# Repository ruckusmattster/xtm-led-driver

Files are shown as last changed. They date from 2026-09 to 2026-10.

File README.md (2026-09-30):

<div align="center">

# XTM LED Driver

**A flicker-free, four-decade DC LED driver for theatrical fixtures.**<br>
1.4 A down to 5 µA as pure DC: no PWM anywhere, nothing for a camera to catch.

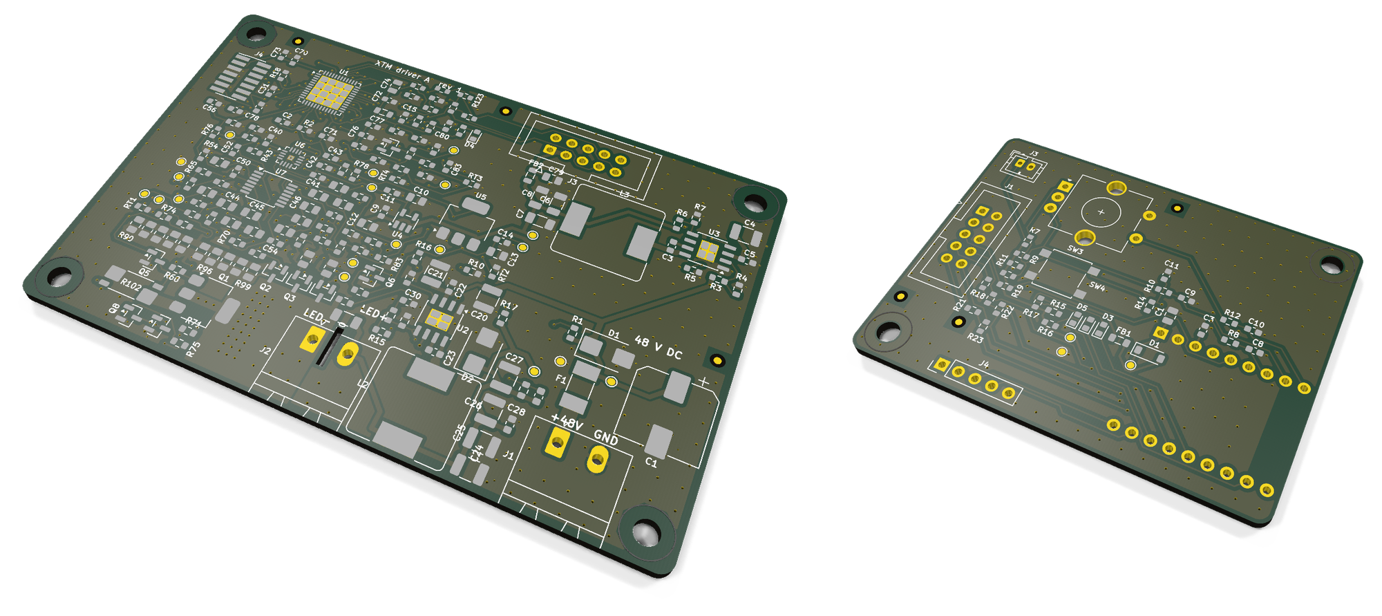
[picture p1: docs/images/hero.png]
3D renders of Board A, the driver, and Board B, the controller








[**Build guide**](docs/BUILD_GUIDE.md) ·
[**Design process**](docs/DESIGN_PROCESS.md) ·
[Hardware](docs/HARDWARE.md) ·
[Firmware](docs/FIRMWARE.md) ·
[Design record](docs/design-record/)

</div>

---

I'm building four stage fixtures around the **Xicato XTM19803050CCA** (19 mm LES, 3000 K, about
5000 lm at 1.4 A). Off-the-shelf drivers either dim with PWM, which rolling-shutter cameras turn
into bands, or bottom out around 1%, which makes the end of every fade snap to black. This
project is a two-board driver that does neither: the LED current is DC at every level from full
output down to 5 µA (0.0004%), fades are smooth enough to film in 240 fps slow motion, and each
fixture is a normal dimmable light in Home Assistant with a knob on the back and a sync button
that makes the others follow it.

Everything is here: the schematics (as code), the design calculations and simulations, scripted
KiCad 9 layouts that come out DRC-clean, Gerbers and placement files, BOMs with verified part
numbers, firmware for both boards with its tests, and the procedures to bring it up, calibrate
it and prove it doesn't flicker.

## Highlights

- **Four DC ranges, not PWM.** Four linear current sinks with 0.1 Ω, 1 Ω, 10 Ω and 100 Ω shunts
  sit in parallel under the LED. Each covers a decade at the same 14–140 mV sense voltage, so
  every range is equally precise, and a calibrated tail carries the last decade and a half to 5 µA.
- **Crossovers you can't see.** Where two ranges meet, both channels share the current on a
  log-domain blend, and the incoming channel idles at a small keep-alive current so it's already
  regulating when it's needed. Simulated deviation at a crossover: 0.14% on a 10 s fade.
- **A tracking buck that stays out of the picture.** A forced-PWM buck at 400 kHz holds the LED
  anode about 1 V above what the sinks need, set ahead of every current change by the MCU. Its
  ripple sits far above anything a camera or eye integrates.
- **Precision where it counts.** 16-bit DAC, zero-drift op-amps, Kelvin-sensed shunts (a
  four-terminal 0.1 Ω and 0.1% thin film for the rest), a guarded "precision island" on a 4-layer board. After calibration each range
  holds about ±0.1% of reading.
- **Real-time control on the driver.** An STM32G431 runs fades at 4 kHz, the crossovers, the
  headroom loop and the protection (a shorted LED clamps every sink within 100 µs). Wi-Fi never
  touches the light.
- **A friendly controller.** Board B is a socketed Waveshare ESP32-S3-Zero running ESPHome:
  Home Assistant light, rotary encoder with push, status LED, and fixture-to-fixture sync over
  ESP-NOW with authenticated packets. Every fixture also works completely on its own.
- **Layout by script.** Python scripts place every part, draw the critical copper by hand-coded
  rules, route the rest with Freerouting, pour and stitch ground, run DRC and export JLCPCB files.
  Both boards come out with 0 errors and 0 unconnected items.

## How it works

```mermaid
flowchart TB
  mains(["Mains"]) --> psu["Mean Well LRS-100-48<br/>isolated 48 V, off-board"]
  subgraph A["Board A · driver · 90 × 60 mm, 4 layers"]
    fuse["Fuse + TVS"] --> buck["Tracking buck<br/>LMR38020, forced PWM"]
    fuse --> aux["Aux buck + LDOs<br/>5.5 V · 5 V · 3.3 V"]
    mcu["STM32G431<br/>4 kHz control loop"] -->|SPI| dac["DAC80504<br/>4 × 16-bit"]
    dac --> sinks["OPA4388 + 4 linear sinks<br/>0.1 Ω · 1 Ω · 10 Ω · 100 Ω"]
    mcu -->|"DAC → feedback"| buck
    sinks -.->|"cathode tap<br/>fast trip"| mcu
  end
  subgraph L["LED"]
    led(["Xicato XTM<br/>up to 1.4 A"])
  end
  subgraph B["Board B · controller · 60 × 45 mm"]
    knob["Encoder · push · sync"] --> esp["ESP32-S3-Zero<br/>ESPHome"]
  end
  ha(["Home Assistant"])
  other(["Other fixtures"])
  psu -->|"48 V DC"| fuse
  buck -->|"LED+"| led
  led -->|"LED−"| sinks
  mcu ---|"10-way ribbon<br/>UART · 5.5 V · reset"| esp
  esp -.-|"Wi-Fi"| ha
  esp -.-|"ESP-NOW"| other
```

The **sinks** set the LED current; the **buck** only supplies the voltage they need. Board A's
MCU knows the LED's forward voltage at every current (it learns it as it runs), so on a rising
cue it raises the buck first and then the current, and on a falling cue the reverse. Only a
level, a fade time and status cross the ribbon to Board B.

<picture>
  <source media="(prefers-color-scheme: dark)" srcset="docs/images/ranges-dark.png">
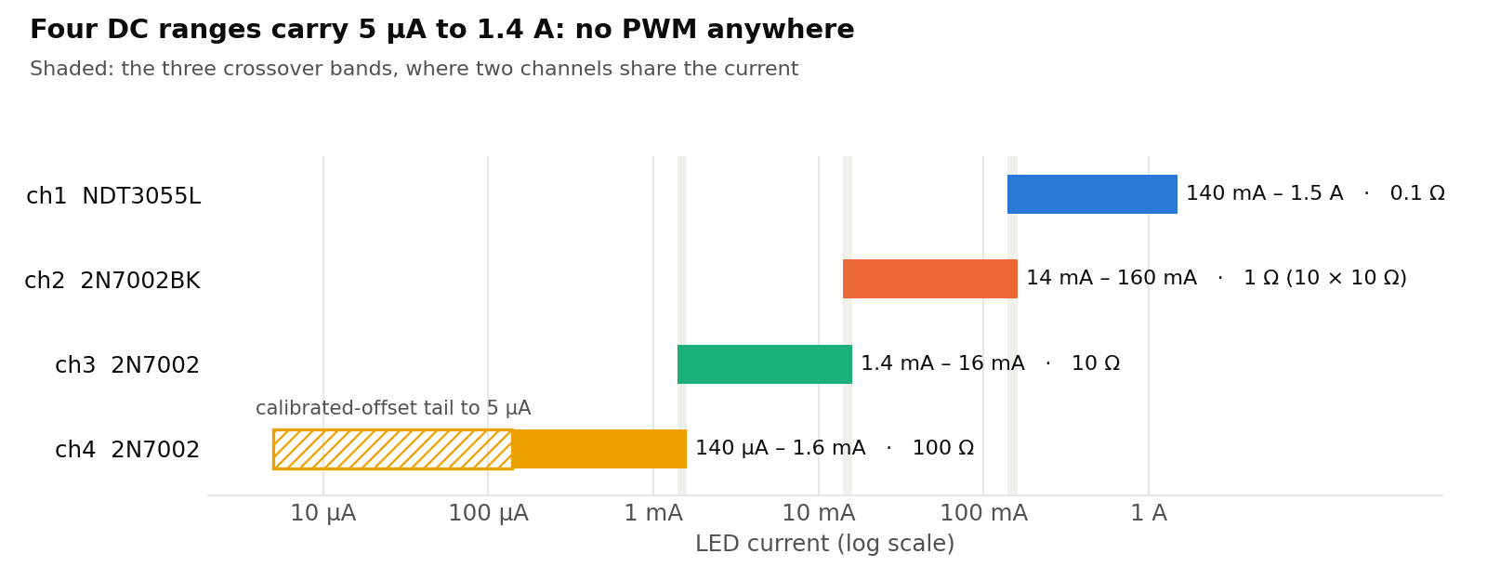
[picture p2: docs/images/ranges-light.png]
Bar chart of the four current ranges on a log scale: ch4 140 µA to 1.6 mA with a tail to 5 µA, ch3 1.4 to 16 mA, ch2 14 to 160 mA, ch1 140 mA to 1.5 A
  
</picture>

Brightness is exponential in the setting, so every step looks the same size: 1% of the scale is
about 13% more light, from 5 µA at the bottom to 1.4 A at the top.

<picture>
  <source media="(prefers-color-scheme: dark)" srcset="docs/images/curve-dark.png">
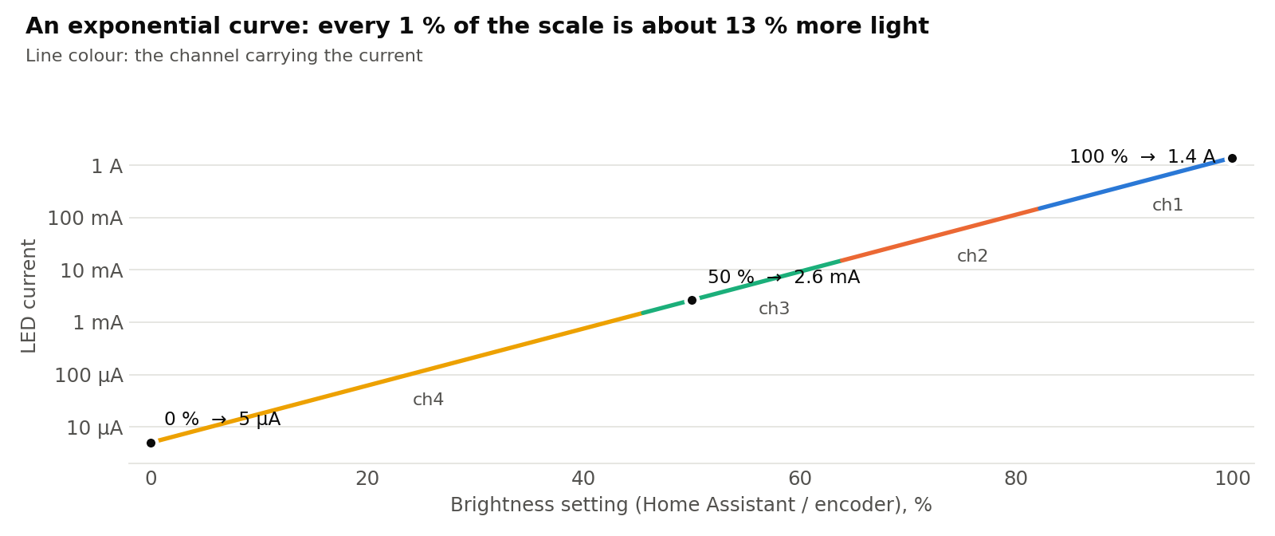
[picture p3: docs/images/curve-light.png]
Line chart of LED current against brightness setting on a log axis: a straight line from 5 µA at 0% to 1.4 A at 100%, coloured by the channel carrying the current
  
</picture>

## The boards

| | Board A: driver | Board B: controller |
| --- | --- | --- |
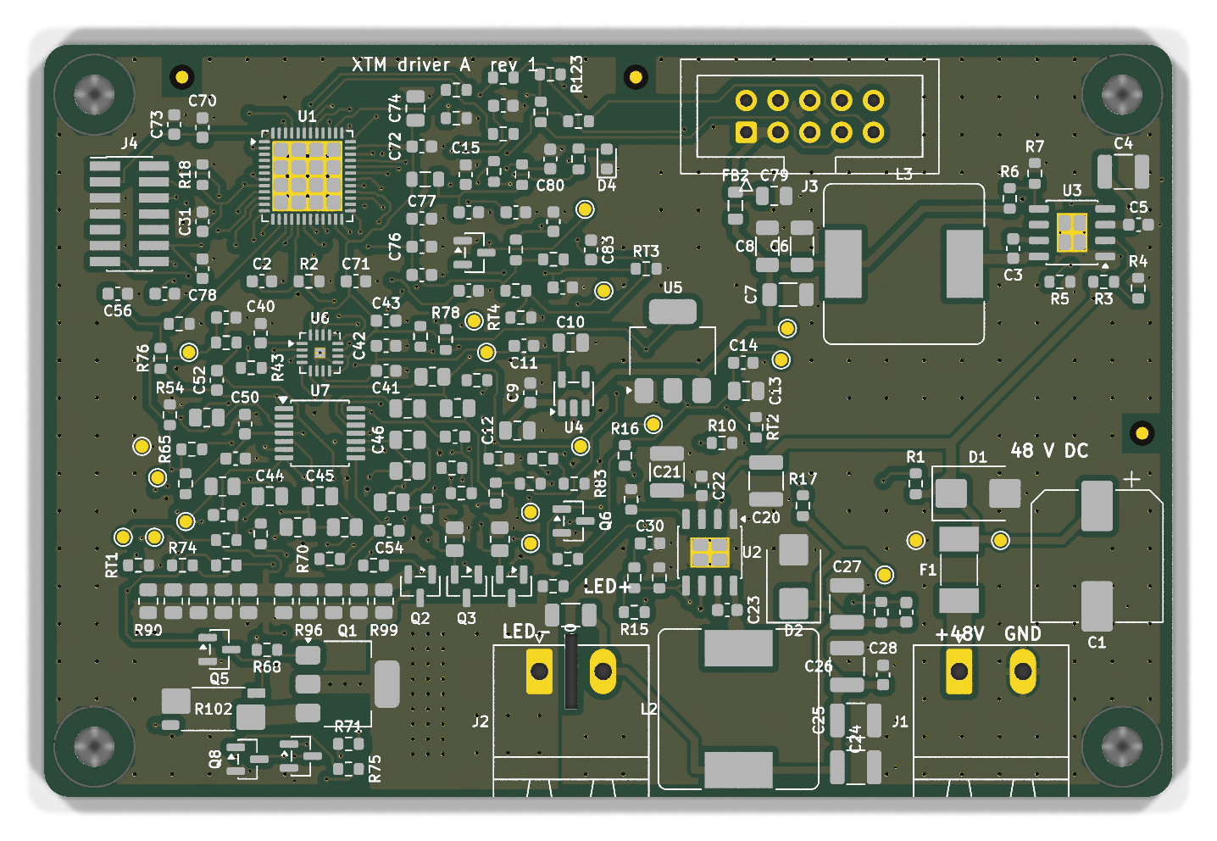
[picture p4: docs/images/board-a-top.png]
Board A top
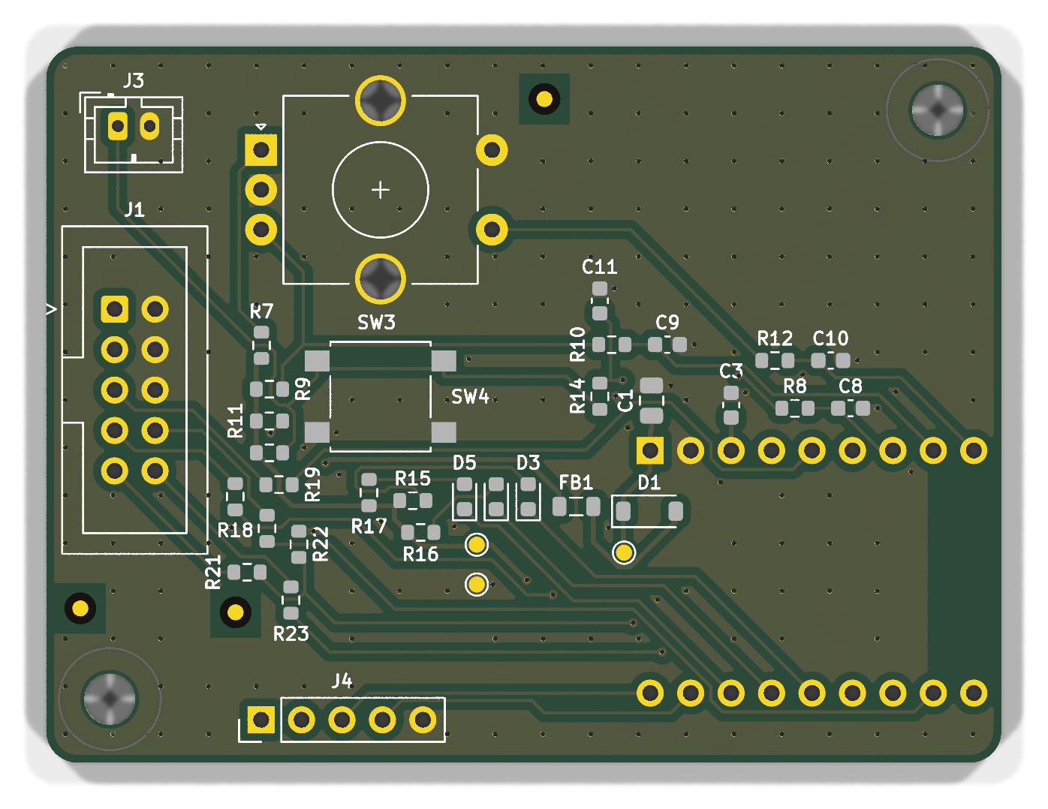
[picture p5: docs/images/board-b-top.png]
Board B top
| **Top** |  |  |
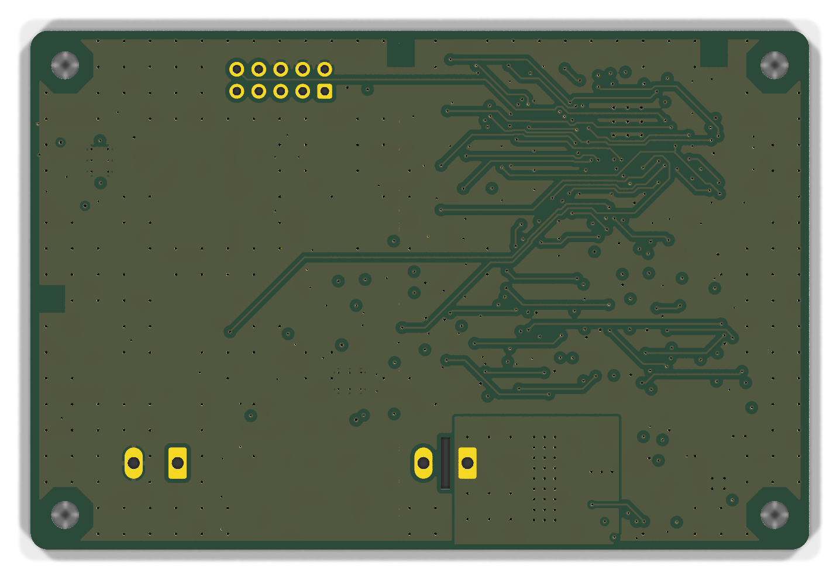
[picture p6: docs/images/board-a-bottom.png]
Board A bottom
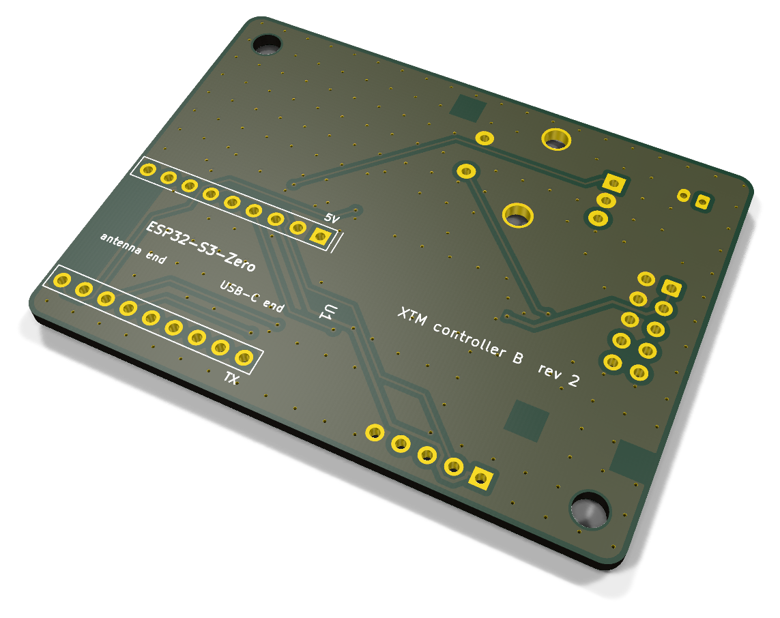
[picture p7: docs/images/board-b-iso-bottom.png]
Board B bottom with the ESP32-S3-Zero sockets
| **Bottom** |  |  |
| Size | 90 × 60 mm, 4 layers, ENIG | 60 × 45 mm, 2 layers, ENIG |
| Parts | 206 on 96 nets | 42 on 32 nets |
| Does | 48 V in, tracking buck, four sinks, protection, fades, calibration | Wi-Fi and Home Assistant, knob, sync, status LED |
| Key parts | STM32G431CBU6, DAC80504, OPA4388, 2 × LMR38020, NDT3055L, WSK2512 | Waveshare ESP32-S3-Zero-M on sockets, Bourns PEC11R encoder |
| Layout result | 0 DRC errors, 0 unconnected | 0 DRC errors, 0 unconnected |

Renders are bare boards from KiCad (no 3D models for the parts). The ESP32-S3-Zero plugs into
two sockets on Board B's back, so it can be pulled out and flashed over its own USB-C.

## Specifications

Design values from the calculations and simulations in [`design/`](design/). None of this has
been measured on hardware yet.

| Parameter | Design value |
| --- | --- |
| Output | 5 µA to 1.4 A DC (1.5 A with tolerance), four ranges plus a calibrated tail |
| Brightness curve | Exponential: 0–100% → 5 µA–1.4 A, about 13% more light per 1% step |
| Flicker target | Under 1% at any frequency from 100 Hz to 20 kHz, at every level and during fades |
| Accuracy after calibration | ±0.09–0.11% RSS in each range; ±0.6% at 14 µA and ±1.6% at 5 µA |
| Crossover smoothness | 0.11–0.14% on a 10 s full-range fade, 0.9–1.5% on a 1 s fade (simulated) |
| Response | Snaps within 5 ms; fades updated at 4 kHz, from instant to 10 minutes |
| Input | 48 V DC (43.2–52.8 V) from a Mean Well LRS-100-48; about 45 W at full output |
| LED voltage | 3.5 V floor to 38 V usable, 40.4 V hard ceiling |
| Protection | Shorted LED (every sink clamped within 50–100 µs), open LED, undervoltage, four temperature sensors with derating, DAC read-back, watchdog, 3 A fuse, TVS on input and output |
| Link loss | Board A blinks twice and settles at 20% if Board B goes quiet; planned restarts hold the level |
| Control | Home Assistant (ESPHome native API), encoder with push, sync button and a header for a panel-mount button |
| Group sync | ESP-NOW broadcast, fixture to fixture, HMAC-SHA256 authenticated; no router or HA in the path |

## Status

| Stage | State |
| --- | --- |
| ✅ Circuit design, calculations, crossover simulation | Done; `design/calc.py` asserts the limits that matter |
| ✅ Schematics (as code) with connectivity check | Done; 0 ERC errors on both boards |
| ✅ Part numbers | Every numbered part checked against a distributor or manufacturer page (29 Sep 2026) |
| ✅ PCB layout | Done by script; both boards 0 DRC errors, 0 unconnected |
| ✅ Board A firmware | Builds (50–58 KB of 126 KB, depending on the toolchain); 97,146 host-test checks pass |
| ✅ Board B firmware | ESPHome config validates; 89 unit checks and a 43-check end-to-end test on ESPHome's Linux build pass |
| ⏳ ESP32-S3 build | Not yet run; the CI workflow in `.github/workflows/` runs it on every push |
| ⏳ Fabrication, assembly, bring-up, flicker measurements | Not started |
| ⚠️ Known firmware issue | Board A detects an open LED only near full output, and learns a bad correction while the LED is disconnected; see [known issues](docs/FIRMWARE.md#known-issues) |

If you build one before I do, I'd love to hear how it went.

## Repository map

```text
xtm-led-driver/
├── design/                 schematics as code, calculations, simulation
│   ├── board_a.py          every Board A part and pin-to-net connection
│   ├── board_b.py          the same for Board B
│   ├── catalog.py          part data: MPNs, LCSC numbers, footprints, verification notes
│   ├── build.py            regenerates hardware/ and runs the connectivity check (ERC)
│   ├── calc.py             every design number; prints calc_output.txt
│   ├── sim/handover.c      time-domain model of a crossover between two sinks
│   ├── compare_netlists.py checks your own KiCad schematic against the generated netlist
│   └── kicad_pos_to_jlc_cpl.py   KiCad position file → JLCPCB CPL, with rotation fixes
├── hardware/               generated from design/: per board, sheet tables, netlist, BOMs
│   ├── board_a/  board_b/
│   ├── board_a.kicad_dru   custom DRC rules (48 V spacing, precision-island clearance)
│   └── LAYOUT.md           the layout rules the scripts follow and you review against
├── layout/                 scripted KiCad 9 layout + Freerouting
│   ├── run_layout.bat      Windows launcher (double-click)
│   ├── make_board.py       stages: place, route, pour, stitch, DRC, export
│   ├── board_a_layout.py   Board A placement, hand-drawn copper, pours, rules
│   ├── board_b_layout.py   Board B the same
│   ├── lib/XTM.pretty/     this project's ESP32-S3-Zero socket footprint
│   └── out/                the finished boards: KiCad projects, Gerbers, CPL, DRC reports
├── firmware/
│   ├── board-a/            STM32G431 firmware in C (CMake), host tests, calibrate.py, flicker.py
│   └── board-b/            ESPHome configs + the xtm_driver external component, tests
└── docs/
    ├── BUILD_GUIDE.md      how to use these files and build the whole thing
    ├── DESIGN_PROCESS.md   how the design got here, and why
    ├── HARDWARE.md         circuit reference
    ├── FIRMWARE.md         firmware reference
    └── design-record/      the Phase 1 review and Phase 2 detailed design, as written
```

## Quick start

**Just want the boards?** The finished layouts are in [`layout/out/`](layout/out/): upload
`board_a-gerbers.zip` and `board_b-gerbers.zip` to JLCPCB with the settings in
[the build guide](docs/BUILD_GUIDE.md#6-order-the-pcbs-and-stencils), and order parts from the
hand-assembly BOMs in [`hardware/`](hardware/). Read [section 5](docs/BUILD_GUIDE.md#5-review-before-ordering)
first.

**Want to check or change the design?**

```sh
python3 design/build.py            # regenerate netlists and BOMs, run the connectivity check
python3 design/calc.py             # every design number (needs numpy, and gcc for the simulation)
make -C firmware/board-a/tests     # Board A host tests
make -C firmware/board-b/tests     # Board B unit tests
layout\run_layout.bat              # both layouts, on Windows with KiCad 9 and Java 21
```

**Building the firmware?**

```sh
cd firmware/board-a
cmake -B build -G Ninja -DCMAKE_TOOLCHAIN_FILE=cmake/arm-none-eabi.cmake && cmake --build build

cd ../board-b
cp secrets.yaml.example secrets.yaml   # fill in Wi-Fi and keys
esphome run xtm-1.yaml
```

The [build guide](docs/BUILD_GUIDE.md) walks through all of it, from installing the tools to a
calibrated, flicker-tested fixture.

## Documentation

| Document | What's in it |
| --- | --- |
| [Build guide](docs/BUILD_GUIDE.md) | Every step to make one yourself: tools, files, ordering, assembly, flashing, bring-up, calibration, flicker testing, use, troubleshooting, pinouts |
| [Design process](docs/DESIGN_PROCESS.md) | From a 0–10 V dimmer idea to this: the requirements, the reviews, the decisions and what changed them |
| [Hardware reference](docs/HARDWARE.md) | Both boards block by block, with values and the reasoning behind them |
| [Firmware reference](docs/FIRMWARE.md) | Board A's control loop, the link protocol, the ESPHome component |
| [Layout scripts](layout/README.md) | Running and changing the automated layout |
| [Layout rules](hardware/LAYOUT.md) | Stackup, floorplan, power and sense routing, clearances |
| [Design record](docs/design-record/) | The Phase 1 review and the Phase 2 detailed design, complete, as written |

## The design in one chart

The first plan used PWM for the bottom decade and handed the current between ranges with a
simple crossfade. Working through the dynamics showed the crossfade would dip the light by up to
17% on a fast fade, because the incoming channel starts from a wound-down integrator. Priming it
with a keep-alive current and blending in the log domain fixed it:

<picture>
  <source media="(prefers-color-scheme: dark)" srcset="docs/images/crossover-dark.png">
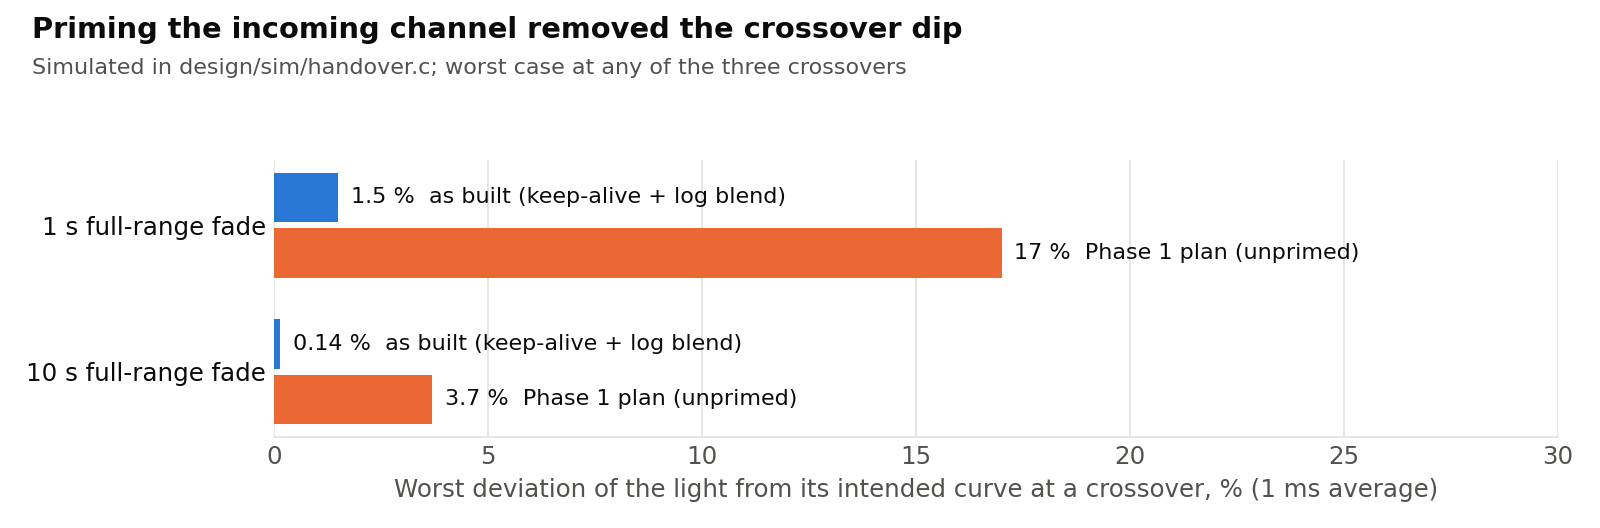
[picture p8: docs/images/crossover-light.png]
Bar chart: worst crossover deviation is 1.5% as built versus 17% in the Phase 1 plan on a 1 s fade, and 0.14% versus 3.7% on a 10 s fade
  
</picture>

That story, and the others like it, are in [the design process](docs/DESIGN_PROCESS.md).

## Safety

Board A runs from 48 V and can put 38 V on the LED connector. Neither board carries mains: the
48 V comes from a separate, certified, isolated supply (Mean Well LRS-100-48) with its own fused
inlet. Wire and enclose the mains side of that supply properly, or have someone qualified do it.
Never plug or unplug the LED while the output is on.

## Acknowledgements

- [KiCad](https://www.kicad.org), [Freerouting](https://github.com/freerouting/freerouting),
  [ESPHome](https://esphome.io) and [Home Assistant](https://www.home-assistant.io) do the heavy
  lifting.
- `firmware/board-a/third_party/` carries Arm's CMSIS (Apache-2.0) and ST's STM32G4 device files
  (Apache-2.0) and LL drivers (BSD-3-Clause), under their own licences.
- The ESP32-S3-Zero footprint's pin order was cross-checked against
  [jtomka/kicad-esp32-s3-zero](https://github.com/jtomka/kicad-esp32-s3-zero).

## License

Not chosen yet. Until a `LICENSE` file is added, the default applies: all rights reserved,
except the third-party files under their own licences.

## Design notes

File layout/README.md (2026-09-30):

# Board layout scripts

These scripts turn the two netlists in `design/` into finished KiCad 9 boards and JLCPCB files,
without anyone drawing the layout by hand. For each board they:

1. build the outline, mounting holes, slots and keep-outs, and place every part: the connectors,
   ICs and power parts at fixed coordinates, the small parts next to the pins they serve;
2. draw the copper that decides whether the board works before anything is routed: both switch
   nodes and bootstrap links (L1 only, no vias), the fused 48 V input and the +48V trunk to the
   buck, Q1's source to its shunt, the ch2 shunt ladder's bus bars, the CATHODE tab copper and heat
   spreader with its vias, the L2 ground plane, escapes for the few pins the router can't get out
   of, and a via to the plane beside every ground pad, while there's still room for them;
3. route everything else with Freerouting (kept out of the CATHODE copper), clean up what it
   leaves (stubs, doubled segments, dangling vias), and route again whatever is still open;
4. pour ground, stitch every pour fragment and pad the pours miss, place the reference labels;
5. run KiCad's DRC with the project's custom rules (`hardware/board_x.kicad_dru`: the 48 V
   spacing from IPC-2221B, 0.5 mm where a bare pad is involved and 0.3 mm between coated tracks;
   2 mm between precision and HV nets; 10 mm from the switch nodes; no vias on them);
6. export Gerbers, drill files and a JLCPCB placement file, and preview images.

The result is a normal KiCad project you open, inspect and adjust like one you drew yourself.

## What you need

- **KiCad 9.0** (any 9.0.x) from https://www.kicad.org/download/windows/ , installed to its default
  folder. Nothing else from KiCad: the scripts use its own Python and `kicad-cli`.
- **A Java 21 runtime** for Freerouting. From a Command Prompt:
  `winget install EclipseAdoptium.Temurin.21.JRE` (or the Temurin 21 JRE installer from
  https://adoptium.net with "Add to PATH" ticked). Open a new Command Prompt afterwards.
- **Internet on the first run**, to download Freerouting 1.9.0 (5 MB, from its GitHub releases)
  into `layout\tools\`. If that's blocked, download `freerouting-1.9.0.jar` from
  https://github.com/freerouting/freerouting/releases/tag/v1.9.0 into `layout\tools\` yourself, or
  set `FREEROUTING_JAR` to where you put it. (Board B's footprint for the ESP32-S3-Zero on its
  sockets is this project's own, in `lib\XTM.pretty`.)

Freerouting 1.9.0 rather than the newer 2.x on purpose: on Board A, 2.1 left over a hundred
connections open where 1.9 leaves a handful, and 2.1 ignores its pass limit.

## Running it

Double-click `run_layout.bat`, or from a Command Prompt in this folder:

```bat
run_layout.bat                          :: both boards, start to finish
run_layout.bat board_b                  :: one board
run_layout.bat board_a --stage place    :: placement only, with a preview (a minute)
run_layout.bat board_a --attempts 10    :: more routing attempts (each board tries 6 by default)
```

Board B takes a few minutes and Board A 5 to 30, most of it in Freerouting, which opens its own
window while it works and closes it when it's done: leave it alone. The same command in the
"KiCad 9.0 Command Prompt" (Start menu) is `python make_board.py board_a`.

Each run writes `out\board_a\` (or `board_b`):

| File | What it is |
| --- | --- |
| `board_a.kicad_pro`, `.kicad_pcb`, `.kicad_dru` | The KiCad project: open the `.kicad_pro` |
| `board_a-gerbers.zip` | Gerbers and drill files for JLCPCB, ready to upload |
| `board_a-cpl-jlc.csv` | Placement file in JLCPCB's format (`board_a-pos.csv` is KiCad's own) |
| `board_a_drc.json` | The final DRC report |
| `board_a-1-FCu_FSilkS.png` and the others | Preview images of each copper layer (SVG if no PNG converter) |
| `board_a_run.log` | What happened, with the DRC summary at the end |
| `board_a_freerouting-1.log`, `.dsn`, `.ses` | The router's input, output and log |

The last line of the log reads `done in ... s: 0 DRC errors, 0 unconnected` when the board is
complete. `run_layout.bat` says so too, and exits with an error otherwise.

## If connections are left open

Freerouting's result changes from run to run. If the log ends with a few connections open:

1. Run the board again, perhaps with `--attempts 10`; each attempt clears a wider circle
   around what's still open before routing it again; or
2. open `out\board_a\board_a.kicad_pro` in KiCad, route the ratsnest lines that remain (they're
   listed in the log), press **B** to refill the zones, save, close KiCad, and run
   `run_layout.bat board_a --stage export`. That re-stitches the pours, re-runs the DRC and writes
   new Gerbers and placement files without touching anything you drew.

The export stage is also how to regenerate the outputs after any hand edit. Running the full
script again starts over from the netlist and discards hand edits.

## Checking the result before ordering

Open each `.kicad_pro` in KiCad 9 and go through this list. The DRC covers the numeric rules; these
are the things a rule can't see.

- **Inspect > Design Rules Checker**, "Refill all zones" ticked: no errors, nothing unconnected.
  Silkscreen warnings are fine; look at any that sit on a pad.
- **View > 3D Viewer**: every part present and on the right side; J1, J2 and J3's openings face
  off the board. Board B's U1 is on the back, shown by its outline on the F.Fab/B.Fab layers
  (there's no 3D model for the module).
- Board A power stage: U2's SW pin, C23 and L2 pad 1 joined by short, wide copper on L1 with no
  vias (the same for U3, C3 and L3); C22 right at U2's VIN pin with a ground via beside it.
- Board A cathode: J2 pin 1, C60, R110 and the four drains all on the tab copper; the heat
  spreader under it on the bottom layer, joined by the grid of vias; R102 at least 2 mm from it.
- Board A sinks: each channel's SNSHI and SNSLO tracks start at the shunt's Kelvin pads (R102
  pads 2 and 3; NT1/NT2 at the ladder's mid-points; NT3–NT6 at R100 and R101); the divider
  bottoms (R46, R48, R50, R52) and C44–C47 return to SNSLO, not to ground.
- Board A precision island: nothing from the switch nodes nearby; the DRC's 2 mm rule keeps HV
  copper away.
- Board B: U1's two socket rows on the back, pin 1 (square pad) at the USB-C end nearest the
  middle of the board; no copper on either side under the antenna end at the right-hand edge.
  Print the board 1:1 (File > Plot, B.Cu, B.SilkS and Edge.Cuts to PDF, mirrored) and lay the
  module on it, pins into the pads, before ordering.
- Holes: Board A's four M3 holes and Board B's two are unplated, with nothing inside their rings.
- The Gerbers in KiCad's Gerber viewer (or JLCPCB's): four copper layers for Board A and two for
  Board B, the slot between J2's pads in the drill/outline file, paste layers present.

References that didn't fit on the silkscreen are on the F.Fab layer: for hand assembly, print it
(File > Plot, F.Fab and Edge.Cuts to PDF) as the assembly drawing.

At JLCPCB: upload the Gerber zip; for assembly, use `hardware/board_x/board_x-bom-jlc.csv` as the
BOM and `board_x-cpl-jlc.csv` as the placement file, and check every part's rotation in their
preview (their library's zero angle doesn't always match KiCad's; polarised parts and the ICs are
the ones to look at).

## What the scripts don't do

- They don't keep each Kelvin pair (SNSHIx with SNSLOx) side by side: the router draws them
  separately. They start at the right sense points, which is what matters most at these slow
  signals; redrawing them as pairs by hand is the one refinement worth the time.
- The router doesn't know which tracks matter more than others: look over the power stage, the
  sinks and the precision island against `hardware/LAYOUT.md` before ordering.
- Freerouting's result varies from run to run, and the placement of small parts follows simple
  rules; a second run can come out better or worse.

## Changing the layout

Everything that decides the layout is in `board_a_layout.py` and `board_b_layout.py`:

- `L.place("U2", 53.1, 40.5, 270)`: fixed parts, in mm from the board's top-left corner, rotation
  in degrees counter-clockwise. Move one, run `--stage place` to see it, then run the whole board.
- `A([...], Rect(x0, y0, x1, y1), anchor_pad=...)`: small parts placed automatically inside the
  rectangle, as close as possible to the pad named (decoupling capacitors) or to the parts they
  connect to. `SPACING` sets the room left between them for routing.
- `NET_CLASSES` and `PATTERNS`: track widths and clearances per net. The widths have to fit the
  pins a net lands on (0.2 mm reaches the 0.5 mm-pitch QFN pins).
- `prerouted()`, `cathode_copper()` and `finish()`: the copper drawn by hand and the pours.
- `SPEC`: how the board is routed: attempts and the time each may take, whether to start over
  every few attempts (`restart_every`, Board B) or keep repairing (Board A), the ground fan-out,
  and which nets are poured rather than routed.

The netlists themselves come from `design/board_a.py` and `design/board_b.py`; after changing
those, run `python design/build.py` (BOMs, sheet tables and netlists) and then the layout.

## Files

| File | Role |
| --- | --- |
| `make_board.py` | The run itself: stages, routing attempts, checks, outputs |
| `board_a_layout.py`, `board_b_layout.py` | Each board's placement, pre-drawn copper, pours and rules |
| `pcbkit.py` | Building a board from a netlist: footprints, placement, tracks, vias, zones, keep-outs |
| `route.py` | Freerouting round trip, clean-up, stitching, DRC, previews, fabrication outputs |
| `kicadlib.py` | Finds KiCad 9's footprint libraries, and this project's own in `lib\` |
| `run_layout.bat` | Windows launcher: finds KiCad and Java, runs both boards |

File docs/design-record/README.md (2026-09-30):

# Design record

The two design documents as they were written during the project. They're addressed to me: I
wrote a brief, Claude reviewed it (Phase 1), I answered its questions, and Claude produced the
detailed design (Phase 2). They're kept as the record of *why* the design is what it is.

| Document | What's in it |
| --- | --- |
| [Phase 1: design review](phase1-review.md) | The critique of my original brief (PWM, the buck, the headroom loop), the error and leakage budgets, power and thermal budgets, the picks for the open decisions, and my answers |
| [Phase 2: detailed design](phase2-detailed-design.md) | Every value on both boards with its reasoning, the crossover analysis, schematics, layout rules, parts and ordering, both firmwares, bring-up, calibration, flicker verification, the pre-order checklist and every assumption |

Where these differ from each other, Phase 2 wins; where either differs from the files in the
repository, the files win. For a shorter, current overview, start with the
[design process](../DESIGN_PROCESS.md), the [hardware reference](../HARDWARE.md) and the
[firmware reference](../FIRMWARE.md).

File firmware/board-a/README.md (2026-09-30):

# Board A firmware (STM32G431CBU6)

Bare-metal C on ST's LL drivers. Runs the four sinks, the tracking buck, fades, crossovers,
headroom, protection, the link to Board B and a calibration console.

## Layout

| Path | What |
| --- | --- |
| `src/main.c` | Start-up order and the main loop |
| `src/app/control.c` | The controller: 4 kHz tick (fades, crossovers, V_out lead, sink codes), fault handling, headroom learning, blink sequences |
| `src/app/link.c` | Board B protocol (COBS + CRC-16 frames, see `src/core/link_protocol.h`) and link-loss handling |
| `src/app/console.c` | Calibration and bring-up console on the STLINK virtual COM port |
| `src/app/settings.c` | Parameters settable from Board B or the console |
| `src/core/` | Portable logic with host tests: brightness curve and light matching, channel calibration and blend, fade engine, LED model, framing, parameter storage format |
| `src/hw/` | Everything that touches a register |
| `third_party/` | CMSIS core, the G4 device header and startup file, and the LL headers, with their licences (`VERSIONS.txt` records the upstream commits) |
| `tests/` | Host tests for `src/core` |
| `tools/calibrate.py` | Current and light calibration over the console |

## Build

Needs CMake 3.20 or later, Ninja or Make, and `arm-none-eabi-gcc` 12 or later. The Arm GNU
Toolchain or the xPack build both work; the firmware was compiled here with xPack GCC 14.2.1.

```sh
cmake -B build -G Ninja -DCMAKE_TOOLCHAIN_FILE=cmake/arm-none-eabi.cmake
cmake --build build
```

That gives `build/board_a.elf`, `.bin` and `.hex`, 50–58 KB of the 126 KB available depending on
the toolchain. The last
2 KB page of flash holds the calibration and settings.

If the toolchain isn't on your PATH, add `-DARM_TOOLCHAIN_DIR=/path/to/toolchain/bin` to the first command.

Host tests (any C compiler; they run under AddressSanitizer):

```sh
make -C tests
```

## Flash

Plug the STLINK-V3MINIE into J4 (STDC14; its cable is keyed) and power Board A from 48 V.
The STLINK senses the target's voltage but does not power it. Any one of these works:

```sh
# STM32CubeProgrammer
STM32_Programmer_CLI -c port=SWD mode=UR -w build/board_a.elf -v -rst
# OpenOCD
openocd -f interface/stlink.cfg -f target/stm32g4x.cfg -c "program build/board_a.elf verify reset exit"
# pyOCD
pyocd flash -t stm32g431cbux build/board_a.elf
```

The factory option bytes are what this design expects. Leave nSWBOOT0 = 1 so the PB8/BOOT0
pin decides boot mode: that is how Board B can put Board A in its ROM bootloader through the
ribbon later. Check them with `STM32_Programmer_CLI -c port=SWD -ob displ`.

## Console

The console runs on the same STLINK's virtual COM port at 115200 8N1. Every command answers
with `key=value` lines and ends with a line starting `ok` or `err`.

| Command | Does |
| --- | --- |
| `st` | One status line: state, level, current, V_out, cathode, 48 V, codes, gate monitors, temperatures, link |
| `lvl L [ms]`, `b pos [ms]`, `off` | Set a level (0-65535, or 0-1 on the curve) with an optional fade |
| `raw ch code`, `rawi ch amps`, `ka ch`, `dark`, `exit` | Calibration mode: one channel alone at a DAC code, at a current, at its keep-alive, or all off; `exit` leaves |
| `cal ch amps` | Record the measured current for the raw channel's present code. Two points replace the channel's model; a third low point is its keep-alive |
| `calreset ch`, `calshow`, `dark_a amps` | Calibration housekeeping |
| `set id value`, `get id`, `params` | Settings (ids in `src/core/link_protocol.h`, `enum link_param`) |
| `save` | Write calibration and settings to flash. The write waits until the light is off or below 10 mA, because erasing flash stalls the CPU for about 20 ms |
| `vf`, `clear`, `id [n]`, `defaults`, `reboot` | Learned V_f table, clear a latched fault, blink to identify, factory defaults (not saved), restart |

## Calibration

See [the build guide, "Calibrate"](../../docs/BUILD_GUIDE.md#12-calibrate), or section "Calibration" of
[the Phase 2 design](../../docs/design-record/phase2-detailed-design.md#calibration). In short:

```sh
pip install pyserial        # and pyvisa for a SCPI meter
python3 tools/calibrate.py current --port /dev/ttyACM0 [--dmm VISA-resource]
python3 tools/calibrate.py lux --port /dev/ttyACM0
python3 tools/calibrate.py fleet --port /dev/ttyACM0 --ref <lux>
```

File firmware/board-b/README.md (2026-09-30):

# Board B firmware (ESPHome, ESP32-S3)

Board B is an ESPHome device. A local external component, `xtm_driver`, talks to Board A over
the ribbon UART, exposes the fixture to Home Assistant as a dimmable light, reads the knob,
and runs the ESP-NOW group sync.

## Layout

| Path | What |
| --- | --- |
| `xtm-common.yaml` | The device configuration, shared by every fixture |
| `xtm-1.yaml` … `xtm-4.yaml` | One per fixture: name and keys, then includes `xtm-common.yaml` |
| `secrets.yaml.example` | Copy to `secrets.yaml` and fill in |
| `components/xtm_driver/` | The external component |
| `components/xtm_driver/link_client.*` | The Board A link: framing, pings, level ownership, start-up, retries (no ESPHome code, so it's tested on a PC) |
| `components/xtm_driver/sync_core.*` | Group sync logic (no ESPHome code either) |
| `components/xtm_driver/xtm_*.{h,cpp}` | ESPHome glue: the hub, the light, entities, ESP-NOW transport |
| `components/xtm_driver/link_protocol.h`, `frame.h`, `frame_c.h` | Verbatim copies of Board A's `src/core` files; the tests fail if they drift |
| `tests/` | Unit tests, and an end-to-end test on ESPHome's Linux build (`tests/host`) |

## Build and flash

Needs ESPHome 2026.9.0 or later (Python 3.12 or later): `pip install esphome`, or `uv tool install esphome`.

```sh
cp secrets.yaml.example secrets.yaml      # then edit it
esphome run xtm-1.yaml                    # first time: the module's USB-C; afterwards over Wi-Fi
```

Board B's ESP32 is a Waveshare ESP32-S3-Zero plugged into two sockets on the back of the board.
For the first flash, pull it out and plug it into the computer with a USB-C cable. If the port
doesn't show up, unplug it, hold its BOOT button while plugging the cable back in, and run the
command again. Then put it back in its sockets, USB-C end toward the middle of the board (the
silkscreen on the back marks both ends). Every later update goes over Wi-Fi. Logs:
`esphome logs xtm-1.yaml` (over Wi-Fi once it's running).

Never plug USB into the module while it's in Board B with the ribbon from Board A connected:
its 5V pin is its USB supply, so Board A's 5.5 V would push back into the computer. For USB logs
in place, unplug the ribbon first; the module then runs from USB, with no link to Board A.

Each fixture needs its own API key in `secrets.yaml` (it also encrypts OTA updates). All
fixtures share `sync_key`.

## What it does

**The light.** Home Assistant sees one dimmable light. Brightness goes to Board A as a 16-bit
level on Board A's own curve (so `gamma_correct` is fixed at 1.0), and a transition goes as
one "fade to X over T ms" command that Board A runs itself. ESPHome's loop timing never
touches the light.

**Knob and buttons.** One detent is 1% of the brightness scale, about a 13% change in light,
as an 80 ms fade; spinning fast takes 2× or 4× steps. Turning up from off starts at the
bottom; turning down stops at the bottom (the push switches off). Push toggles with a 400 ms
fade. The sync button is described below.

**Who decides the level.** Board B does. It sends a level when the light's target changes and
otherwise leaves Board A alone. Board A echoes the last level it received in every STATUS
(`level_link`), so Board B re-sends only when that echo shows a problem: a frame lost on the
wire, Board A reset, or Board A's link-loss fallback. A level typed on Board A's console
stands until Board B next changes the light.

**Restarts.**

| What restarts | What happens |
| --- | --- |
| Both boards (power-up) | The light's saved state (`restore_mode: RESTORE_DEFAULT_OFF`) fades in over 1 s |
| Board B, planned (OTA, restart button) | Board B asks Board A to hold for 30 s (120 s for OTA); the light doesn't change; Board B adopts Board A's level when it's back |
| Board B, crash | Board A blinks twice and drops to the link-loss level (20%) after 1.5 s; Board B restores the previous level over 1 s when it's back |
| Board A | Board B sends its level again over 1 s |

**Status LED** (on Board B, dimmed to 30%, 25 kHz PWM):

| Pattern | Meaning |
| --- | --- |
| Green, first 2 s | Starting |
| Red, slow blink | No link to Board A |
| Red, fast blink | Board A reports a fault (see the Fault sensor) |
| Blue, steady | This fixture leads the sync group |
| Blue, short blip each second | This fixture follows the group |
| Amber blip every 3 s | Not connected to Wi-Fi (the fixture still works) |
| Off | Normal |

**Entities.** Light; LED current and voltage; driver output and 48 V input voltages; four
temperatures; driver state, fault, sync role and firmware; link, derating, calibrated and
light-matched flags; clear fault, identify and restart buttons; Board A settings (link-loss
level, bottom current, full-scale current, fleet reference light, link timeout); a Sync lead
switch.

## Group sync

Press the sync button on any fixture: it becomes the lead and every other fixture follows its
level. Press it on another fixture and the lead moves there. Press it on the lead to end the
group; every fixture keeps its level. Adjusting a follower by hand (knob, push, Home
Assistant) takes that fixture out of the group. A fixture that restarts while a group is
running rejoins it.

It runs over ESP-NOW broadcasts, fixture to fixture, with no Home Assistant or router in the
path. The lead sends its target and remaining fade time on every change (repeated after 100
and 300 ms) and once a second; followers let go after 5 s without hearing it. Every packet
carries an HMAC-SHA256 tag under `sync_key`, so fixtures with a different key, and anyone
else's radio, are ignored.

ESP-NOW shares the Wi-Fi radio's channel, so every fixture in a group must be on the same
access point. Without one, sync is unreliable: each ESP32 keeps scanning channels looking for
it. For a venue with no Wi-Fi at all, a variant of `xtm-common.yaml` with `wifi:`, `api:`,
`ota:` and `captive_portal:` removed and `espnow: channel: 1` added syncs reliably, at the
cost of Home Assistant and over-the-air updates (reflash with the module out, over its USB-C).

## Tests

```sh
make -C tests                        # unit tests: link client and sync (ASan/UBSan)

cd tests/host                        # ESPHome's Linux build against a simulated Board A
esphome compile --only-generate xtm-host.yaml
python3 build_host.py                # compiles it with the system g++
python3 run_host_test.py             # drives it through the native API, as Home Assistant does
python3 check_sync_glue.py           # type-checks the ESP-NOW glue against ESPHome's headers
```

`run_host_test.py` covers turn on and off with transitions, the knob and push, settings,
buttons, a lost frame, a Board A reset, a Board A fallback, link silence, planned and
unplanned restarts of Board B, and power-up restore.

What could not be run here: the ESP32-S3 build itself (`esphome compile xtm-1.yaml`), because
it downloads the toolchain from the PlatformIO registry. The component sources are the same
ones compiled and tested in the host build above. Run that compile first.

## Not included

Flashing Board A from Board B. The ribbon carries BOOT0 and NRST for it, and the component
already drives both (the Restart driver button pulses NRST), but the STM32 bootloader client
isn't written. Flash Board A with the STLINK.

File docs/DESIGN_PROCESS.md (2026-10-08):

# Design process

How this went from "a dimmer for my Xicato fixtures" to a two-board, four-decade driver with its
own firmware and scripted layout, in the order it happened, with the reasoning at each turn.

I did this in collaboration with Claude. Claude assisted in firmware development and testing, documentation, and helped answer my questions regarding design practices.
The complete documents from the two design phases are in [`design-record/`](design-record/).

```mermaid
flowchart TB
  subgraph p1["1 · From idea to brief"]
    direction LR
    a["0–10 V dimmer<br/>for an LTF driver"] --> b["Own CC driver:<br/>requirements"] --> c["Architecture:<br/>tracking buck +<br/>parallel sinks"] --> d["Design brief<br/>(locked decisions)"]
  end
  subgraph p2["2 · Design"]
    direction LR
    e["Phase 1 review<br/>+ my answers"] --> f["Phase 2<br/>detailed design"] --> g["Independent<br/>final check"]
  end
  subgraph p3["3 · Layout and build"]
    direction LR
    h["Scripted layout<br/>(KiCad 9)"] --> i["Board B rev 2:<br/>socketed ESP32"] --> j(["Build and<br/>measure"])
  end
  p1 --> p2 --> p3
```

---

## 1. Where it started

I'm building four stage fixtures around the **Xicato XTM19803050CCA**: a 19 mm LES, 3000 K,
roughly 5000 lm module driven at up to 1.4 A. The first plan was modest: an ESPHome controller
putting out 0–10 V to an off-the-shelf constant-current driver.

Two requirements broke that plan:

- **Smooth dimming to 0.1% of full output.** 0–10 V interfaces are specified to about 1% at best,
  and most drivers bottom out well above 0.1%, so the end of every fade snaps to black.
- **Flicker-free on camera, including phone slow motion.** Cameras would be pointed at these
  fixtures. Most drivers dim the bottom of their range with PWM or drop into pulse-skipping at
  light load; a rolling shutter turns either into bands across the frame.

Neither can be fixed from outside the driver, so I dropped the 0–10 V stage and the commercial
driver and decided to build the constant-current driver myself: one board for the power and
current control, a separate ESPHome board for the controls, fed by an off-the-shelf isolated
48 V supply so that no mains voltage ever touches my boards.

## 2. Choosing an architecture

With cameras ruling out PWM, the whole range had to be analog, and 0.1% at the bottom means the
current-sense signal can't be allowed to shrink to nothing. Several ways to get there came up:

| Option | Verdict |
| --- | --- |
| One buck as the current source, with switched sense shunts | A buck at 0.1% load runs into its minimum on-time and pulse-skips into the audio band; the range switching is a glitch in every fade |
| Buck for the top, a linear sink for the bottom decade | Works, but adds a mode change and a second kind of handover |
| A dedicated current-source IC for the bottom (LT3092 and similar) | Less design work, but you inherit its accuracy and drift rather than choosing your own shunts |
| A second small buck in parallel | Two switchers, cross-conduction, and the small one still pulse-skips at its own bottom |
| **A tracking buck feeding linear sinks that do all the current control** | **Chosen** |

The chosen structure: the buck never regulates current. It holds the LED's anode about 1 V above
what the sinks need, so it drops out of the accuracy path entirely. The current is set by
**parallel linear sinks**, each with its own FET, op-amp and shunt straight to ground, one per
decade: 0.1 Ω for 140 mA–1.4 A, 1 Ω for 14–140 mA, 10 Ω for 1.4–14 mA. Every range sees the same
14–140 mV of sense voltage, so every range is equally precise. Parallel currents simply add, so
a range change is one channel ramping up while the other ramps down, with no FET in any sense
path and each FET sized for its own current.

Then the question "why stop at 1.4 mA?" Perceived brightness goes roughly as the square root of
luminance, so 0.1% of the light still looks like about 3% brightness, and the last step to black
is visible. Going a decade deeper makes the fade look like it disappears rather than switches
off. My brief did that with **PWM on the low channel for the bottom decade**, down to 140 µA
average.

### The brief

I wrote a detailed brief with the requirements and a set of "locked decisions" to design around:

1. An isolated 48 V module; **no mains voltage on either of my boards**.
2. A buck that may be asynchronous and pulse-skip, with a slow analog headroom loop and OVP
   around 40 V.
3. Three parallel linear sinks with Kelvin-sensed shunts.
4. A crossfade with hysteresis between ranges.
5. PWM on the low channel for the bottom decade.
6. A 16-bit quad DAC and a logarithmic curve.
7. An ESP32 running ESPHome on Board B, with an encoder, a push button and a sync button.

## 3. Phase 1: the review that changed the plan

The first phase was a critique of the brief before any schematic existed. Three of the locked
decisions didn't survive analysis. The full review is
[design-record/phase1-review.md](design-record/phase1-review.md).

**Buck ripple reaches the LED even with ideal sinks.** Capacitance from the LED's cathode to
ground (the off channels' FETs, the leads, the module-to-heatsink path) has to be charged through
the LED whenever V_out moves, and no sink sees that current. At 140 µA the LED's dynamic
resistance is about 4.6 kΩ, so a pulse-skipping buck rippling 20 mV at 10 kHz would put 0.9%
flicker on the light by itself. **Fix:** a synchronous buck locked in forced PWM at a fixed
400 kHz, far above anything a camera or eye integrates.

**The case for PWM falls apart.** Off-channel leakage flows through the LED continuously, so its
error is the same whether the average comes from PWM or DC. And the LED doesn't really switch
off between pulses: the cathode capacitance keeps it conducting at microamps. Meanwhile PWM adds
pulse-charge errors that drift with the FET's threshold, beats with the buck, and phone banding
at short exposures. **Fix:** a fourth DC range, 100 Ω for 140 µA–1.4 mA: one small FET, one
precision resistor, and the fourth sections of the op-amp and DAC that were there anyway.
Below 140 µA it keeps dimming on calibrated offset to about 5 µA.

**A slow headroom loop can't follow a snap cue.** The LED's forward voltage rises with current,
so a snap from 10% to full would starve the sink until a slow loop caught up, then overshoot.
**Fix:** move the headroom loop into an MCU on Board A with feed-forward: it knows (and learns)
the forward voltage at every current, raises V_out *before* raising the current, and lowers the
current before V_out on the way down.

Smaller changes: a **100 W** supply instead of 60 W (the worst case is 56 W); a **static blend**
between ranges instead of hysteresis (a stateless blend has nothing to hunt); a **fast
comparator trip**, because a shorted LED doesn't "fall out" but puts all of V_out across the
active FET; a **V_out floor** so that off really is dark; and a **zero bias plus gate clamps**, so
DAC code 0 is reliably off. And one observation that shaped the calibration plan: the module's
own ±10% flux tolerance dwarfs the driver's accuracy, so matching fixtures needs a light gain per
fixture, not just matched current.

The real-time control went to an **STM32G431** on Board A, so fades, ranging, headroom and faults
stay deterministic and independent of Wi-Fi: a Wi-Fi stack crash can't leave the LED unsafe.

## 4. Phase 2: the detailed design

Phase 2 put a value on every part, wrote both boards' firmware, and wrote the bring-up,
calibration and flicker procedures. The complete document is
[design-record/phase2-detailed-design.md](design-record/phase2-detailed-design.md).

### Every number from a script

Every value comes from [`design/calc.py`](../design/calc.py), which asserts the limits that
matter (loop phase margins, the buck's minimum on- and off-times, inductance, the V_out ceiling),
and from a time-domain model of a crossover, [`design/sim/handover.c`](../design/sim/handover.c).
Change a value, rerun, and anything that breaks fails loudly.

### The flaw the simulation found

Modelling the crossovers in the time domain turned up a real problem with the Phase 1 plan. A
channel sitting unused has its integrator wound down to 0 V. Before it can carry any current, its
output has to climb to the FET's threshold, about 2 V, at a rate set by a tiny error signal. So
during a crossfade the incoming channel lagged its setpoint through the whole band, and the
light dipped: about 3.5% on a 10-second fade and 16% on a 1-second one. Visible, and on camera.

The fix has three parts. **Keep-alive:** a channel about to be needed regulates a tiny current
(2.5 µA on the 10 Ω channel, for example), which parks its integrator at the FET's threshold,
ready to move; the MCU subtracts that current from the active channel. **Arming:** a channel arms
when the level passes half its band's bottom, or when a fade's trajectory will reach its band
within 0.4 s. **A log-domain blend:** inside a band, the ratio of the two channels' currents runs
linearly in log(I), so each channel's share grows exponentially, which a loop biased near
threshold can follow.

<picture>
  <source media="(prefers-color-scheme: dark)" srcset="images/crossover-dark.png">
  Bar chart: worst crossover deviation 1.5% as built versus 17% for the Phase 1 plan on a 1 s fade; 0.14% versus 3.7% on a 10 s fade
</picture>

### Other changes that came out of the detail

- **A 22 nF capacitor across the LED.** It makes the cathode follow V_out at audio frequencies,
  so buck ripple barely reaches the LED current: the ripple allowed at the bottom of the range
  rose from about 6 mV to over 100 mV. With it in place the two bucks free-run instead of being
  synced to the MCU.
- **The MCU holds the main buck off whenever it's in reset**, so a crashed or unprogrammed MCU
  can't light the LED.
- **The buck's feedback network was rescaled**, because the STM32's buffered DAC can't swing
  within 0.2 V of its rails.
- **An ADC tap on each op-amp output**, so firmware sees when a channel is primed or short of
  headroom.
- **Off and on are sequenced, with a voltage-mode tail.** Below 5 µA the sink holds and V_out
  keeps falling instead, and the LED's current follows it exponentially down to picoamps. The
  final fade to black is continuous, with no last step.
- **The LED heatsink and the 48 V side stay unearthed.** A floating heatsink follows the array's
  voltage, which keeps its capacitance out of the ripple path.

### Schematics as code

Instead of drawing schematics, every part and every pin-to-net connection is declared in Python
([`design/board_a.py`](../design/board_a.py), [`board_b.py`](../design/board_b.py)), with the
part data in [`catalog.py`](../design/catalog.py). One command regenerates the netlists, BOMs and
sheet tables and runs a connectivity check. That gave one source of truth for connectivity, a
check on every build, and a design that doesn't depend on a particular KiCad version's schematic
format. Anyone who wants a drawn schematic can capture it from the sheet tables and prove it
matches with `compare_netlists.py`.

### Firmware, tested before there's hardware

Board A's firmware splits into `src/core` (the curve, calibration, blend, fade engine, LED model,
framing, parameter storage: no registers) and `src/hw`. The core runs on a PC under
AddressSanitizer: 97,146 checks. Board B's ESPHome component is tested the same way, and
end-to-end: ESPHome's Linux build runs the component against a simulated Board A on a
pseudo-terminal, driven through the same native API Home Assistant uses.

### Testing kept to a minimum, by design

Per my answer, nothing gets measured before layout. The design instead states its assumptions
about the XTM (a low-current slope near 0.65 V per e-fold, at most about 50 nA of internal
bypass, 0.3–1 nF on the cathode) and makes the one thing that depends on them, the tail's end
point, a setting. The bring-up procedure is seven steps, each with a pass line, that prove the
board is safe and the loops behave; calibration and a flicker check catch the rest.

## 5. The independent check

| Found | Changed |
| --- | --- |
| The DAC80504's 2.5 V reference, undivided, sits exactly at the datasheet's VDD/2 limit on a 5 V supply, where a reference alarm turns every output off | Reference halved and gain doubled (REFDIV and GAIN strapped high), full scale unchanged; the footprint corrected to TI's RTE0016D with its 0.8 mm pad |
| The buck enable was on PB9, which the STM32's ROM bootloader uses as its CAN transmit pin, idling high: the buck would have started during a reflash | Moved to PC13, with a pull-down |
| No distributor stocked the WSK2512 0.1 Ω shunt | The two-terminal WSL2512 named as a same-pads fallback, with its effect on the error budget |
| ST's STDC14 header part has alignment pins that need holes the footprint lacks | FTSH-107-01-L-DV-K instead of -K-A |
| LCSC's encoder is the knurled-shaft variant; a chosen electrolytic was a 12.5 mm can; two LEDs were out of stock; a ferrite rated 500 mA sat on a 600 mA rail | BOM corrected, each replacement verified |
| The thermal estimate used a generic board | Recomputed on the real 90 × 60 mm outline and copper: about 127 °C FET junction in 45 °C air, against 150 °C |
| — | Encoder footprint with round lug holes; tactile switch footprint that current KiCad versions still ship |

Every part number in the BOMs now carries a status saying where and when it was verified, and the
parts that don't need a specific maker are listed by description.

## 6. Layout by script

I use KiCad 9 on Windows, and I wanted a layout I could regenerate after any change rather than a
one-off drawing. So the layout is done by Python scripts running inside KiCad 9 (see
[`layout/`](../layout/)): they place every part, draw the copper that decides whether the board
works, route the rest with Freerouting, pour and stitch ground, check everything with KiCad's
DRC and a set of custom rules, and export JLCPCB's files. The rules they follow are written down
in [`hardware/LAYOUT.md`](../hardware/LAYOUT.md), which doubles as the review checklist.

Getting both boards to **0 DRC errors and 0 unconnected** took solving a series of problems:

- **Router version.** Freerouting 2.1 left over a hundred connections open on Board A and ignored
  its pass limit; 1.9.0 leaves a handful and is pinned.
- **The router cut through copper that matters.** Q1's heat-spreading "tab" copper is on the LED
  cathode net, and the router happily ran other tracks through it. The scripts now pass keep-out
  areas to Freerouting.
- **No room left for ground vias.** After routing, 83 ground pads had nowhere to put a via to the
  plane. The scripts now fan out a via beside every ground pad *before* routing, with the track
  width adapted to each pad.
- **Router crumbs.** Dangling stubs and vias connected to nothing, removed automatically from the
  DRC report.
- **Missing pour.** KiCad removed "island" pour fragments before the stitching vias that would
  have connected them were placed; island removal is now off while stitching.
- **A connectivity bug in my own tools.** Two pads with the same number on one part (a switch's
  pad 2, twice) were treated as joined when KiCad doesn't join them; pads are now tracked by
  their unique IDs.
- **High-voltage spacing.** A blanket 0.6 mm clearance on the 48 V nets walled the buck's enable
  pin in. The rules now follow IPC-2221B's table for 51–100 V properly: 0.5 mm where a bare pad is
  involved, 0.3 mm between coated tracks and on inner layers.
- **Layer use.** Routing about 200 parts on the outer layers alone left too many connections
  open, so the third layer carries signals too, with the second a solid, unbroken ground plane.
- **Heat.** The channel-1 FET dissipates 1.2 W with no heatsink. The layout gives it 2.3 cm² of
  copper on top, 2.8 cm² on the bottom and 39 vias between them.

Board A now routes completely on the first attempt in about four minutes; Board B in under one.

<picture>
  <source media="(prefers-color-scheme: dark)" srcset="images/floorplan-dark.png">
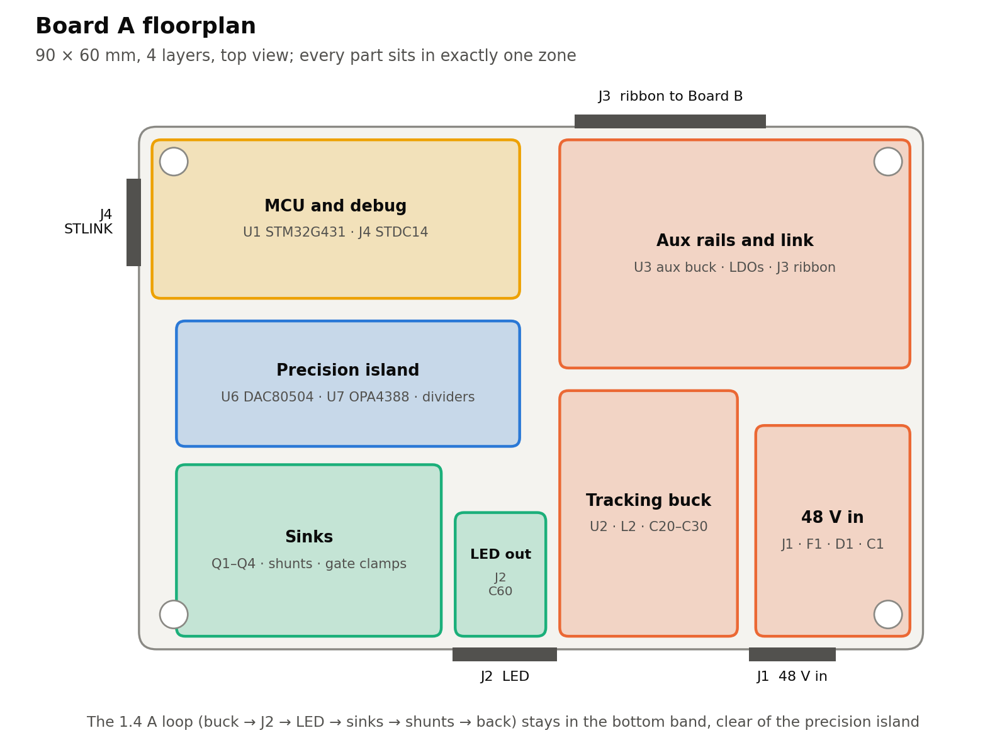
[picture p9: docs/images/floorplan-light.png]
Board A floorplan: MCU top left, aux rails top right, precision island in the middle left, sinks and LED output bottom left, tracking buck and 48 V input bottom right
  
</picture>

## 7. Board B, revision 2: a socketed module

The first Board B carried a bare ESP32-S3-WROOM-1 module with its own USB-C connector, ESD
protection, 3.3 V regulator and reset circuit. The USB-C receptacle (0.5 mm pitch) was the
hardest part to hand-solder on either board and the one the router struggled with most. So I
looked at the alternatives:

| Option | For | Against |
| --- | --- | --- |
| WROOM module on the board (as designed) | Smallest, cleanest | The fiddly USB-C and support parts; a dead module means desoldering |
| A pre-built dev board SMD-soldered flat | Fewer parts | Still soldered in; castellations are hard to inspect or rework |
| **A dev board with male headers in female sockets** | 17 fewer parts, no USB-C to solder, a ten-second swap, flashed off the board | Height; the module's own quirks |

The **Waveshare ESP32-S3-Zero-M** won: ESP32-S3 with 4 MB flash and 2 MB PSRAM, its own USB-C,
regulator and buttons, a ceramic antenna, and 2.54 mm edge pins with headers already fitted.
Its trade-offs shaped the board:

- On its sockets it stands 12–14 mm tall, and the operator panel sits a few millimetres above
  Board B's top side, on the encoder's nut. So the sockets are on the **back**.
- Its 5V pin is its USB supply, with no diode. A Schottky keeps USB power out of Board A, but
  nothing keeps Board A's supply out of a computer, so the module is **flashed out of its
  sockets**.
- It fits turned round, which would put 5 V on a GPIO, so the back silkscreen names both ends
  and marks pins 1 and 18.
- Its footprint is this project's own, drawn from Waveshare's figures and cross-checked against
  a community footprint and product photos, so the build guide asks for a 1:1 print check.
- The link to Board A moved to IO1/IO2, keeping UART0 (which the boot ROM talks on) off Board A's
  line; IO3, a strapping pin, is left spare.

## 8. What's next

1. Build the first set and run bring-up; the procedures are written to fail early and clearly.
2. Measure what the design assumed about the XTM at microamp currents (its low-current slope,
   internal bypass and cathode capacitance) and set the tail's end point from it.
3. Calibrate, then verify flicker with the photodiode rig and a phone at 240 fps.
4. Run the ESP32-S3 build in CI (the workflow in `.github/workflows/` does it).

Improvements on the list, none needed for a first build: a matched divider network (it would
restore Phase 1's tighter error budget), 10 ppm/°C shunts, routing each Kelvin pair side by side
by hand, a larger Board A outline for thermal margin, and a bootloader client on Board B so it
can reflash Board A over the ribbon (the ribbon already carries BOOT0 and NRST for it).

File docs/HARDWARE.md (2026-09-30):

# Hardware reference

Both boards block by block: what each part of the circuit does, its values, and why. Every
number comes from [`design/calc.py`](../design/calc.py) (output in
[`calc_output.txt`](../design/calc_output.txt)) and the crossover model
[`design/sim/handover.c`](../design/sim/handover.c). For every part and pin, see the sheet tables
[`hardware/board_a/board_a-sheets.md`](../hardware/board_a/board_a-sheets.md) and
[`board_b-sheets.md`](../hardware/board_b/board_b-sheets.md); for the full reasoning, the
[Phase 2 design](design-record/phase2-detailed-design.md).

## Contents

- [System](#system)
- [Board A: power entry and aux rails](#board-a-power-entry-and-aux-rails)
- [Board A: tracking buck](#board-a-tracking-buck)
- [Board A: setpoints and the four sinks](#board-a-setpoints-and-the-four-sinks)
- [Board A: crossovers](#board-a-crossovers)
- [Board A: LED output, protection, off and on](#board-a-led-output-protection-off-and-on)
- [Board A: MCU](#board-a-mcu)
- [Board A: accuracy](#board-a-accuracy)
- [Board A: thermal](#board-a-thermal)
- [Board A: layout](#board-a-layout)
- [Board B](#board-b)
- [The ribbon link](#the-ribbon-link)

---

## System

| Item | Value |
| --- | --- |
| Supply | Mean Well LRS-100-48 (110 W, 43.2–52.8 V adjustable, left at 48 V), off-board, its case earthed |
| Load | Xicato XTM19803050CCA: 1.4 A rated (1.5 A with tolerance), V_f 28.6 / 29.9 / 36.0 V (min / typ / max at 1.4 A over 20–90 °C), ±10% flux |
| Draw at full output | About 45 W typical, 54 W worst case: 41–49% of the supply's rating |
| Board A | 90 × 60 mm, 4 layers, 206 parts, 96 nets |
| Board B | 60 × 45 mm, 2 layers, 42 parts, 32 nets |

The LED current is set entirely by four linear sinks under the LED's cathode. The buck only
supplies the voltage they need, set by the MCU ahead of every change in current.

## Board A: power entry and aux rails

*Sheet A1.*

| Block | Parts and values | Why |
| --- | --- | --- |
| Input | J1 Phoenix MSTBA 2,5/2-G-5,08 (pin 1 +48 V). F1 Littelfuse 0452003.MRL, 3 A slow-blow. D1 SMBJ58A. C1 47 µF 100 V electrolytic, 10 × 10.2 mm | F1 protects the wiring below the supply's hiccup threshold; D1 clamps surges and conducts on reverse polarity so F1 or the supply's hiccup takes over; C1 damps the supply leads |
| 48 V monitor | 100k / 6.2k with 10 nF, to PB0 | 52.8 V reads 3.08 V |
| Aux buck U3 | LMR38020FDDAR at 500 kHz: RT 52.3k, FB 100k / 22.1k (5.53 V), EN 280k / 10k from VIN, BOOT 100 nF. L3 SRR1260-150M (15 µH). In: 4.7 µF 100 V 1210 + 100 nF. Out: 3 × 22 µF 25 V 1206 | Starts at about 36 V (31.9–40.6 V over the EN tolerance); the same part as the main buck |
| +5VA | TPS7A2050PDBVR from 5.5 V | DAC, op-amp and the zero-bias source |
| +3V3 | LDL1117S33R from 5.5 V; a ferrite and 1 µF + 100 nF to VDDA/VREF+ | The MCU. The raw 5.5 V also feeds Board B over the ribbon |

## Board A: tracking buck

*Sheet A2.*

- **Converter:** U2, LMR38020FDDAR in **forced PWM** at 400 kHz (RT 64.9k). L2 SRR1260-330M,
  still 26.4 µH at −20%, above the 24.4 µH the datasheet needs at 39 V; its 2.8 A saturation
  current covers the 1.84 A peak in use. Input 2 × 4.7 µF 100 V 1210 + 100 nF; output 4 × 4.7 µF
  + 100 nF (about 10 µF effective at 30 V): 27 mV p-p ripple at 400 kHz.
- **Feedback with injection:** 200k top, 7.32k bottom; the MCU's DAC (PA4) injects through
  8.25k + 8.25k with 47 nF from the midpoint to ground. A 22 pF C_ff footprint (C29) is not fitted.
- **Transfer:** **V_out = 40.44 − 12.12 × V_dac**, 9.8 mV per 12-bit code.
  - DAC at its 0.2 V buffer limit: 38.0 V, 1 V above the worst-case need (36.0 V + 1.0 V headroom).
  - DAC at 3.05 V: the 3.5 V floor (off).
  - DAC stuck at 0 V: a 40.4 V ceiling, below D2's 43 V standoff.
  - V_out follows the DAC with a 0.19 ms time constant, 95% in about 0.6 ms.
- **Safe off:** EN comes from PC13 with a 100k pull-down, so the buck is off whenever the MCU is
  in reset, unprogrammed or in its ROM bootloader.
- **Status:** power-good to PC4 (100k pull-up); D2 SMBJ43A on V_out; V_out sensed through
  1M / 82k with 10 nF to PA0.
- **Loop:** the injection lowers loop gain to 0.38–0.72× of a plain divider, which lowers the
  crossover and adds phase margin. Every operating point from 3.5 V to the 40.4 V ceiling meets
  the 131 ns minimum on-time and 300 ns minimum off-time with 43.2–52.8 V in (38 V sits exactly
  at the off-time limit at 43.2 V, so the supply stays at 48 V).

## Board A: setpoints and the four sinks

*Sheets A3 and A4.*

**Setpoints.** A DAC80504 (U6), four 16-bit channels, runs its 2.5 V reference halved and its
gain doubled (REFDIV and GAIN strapped to VIO) for 2.5 V full scale; undivided, the reference
would sit at the datasheet's VDD/2 limit on 5 V, where an alarm turns every output off. REF has
220 nF; RSTSEL low, so it powers up at zero. SPI mode 1 on PA15/PB3/PB5/PB4 through 22 Ω; the
firmware reads the registers back every few milliseconds, the alarm included. Each channel then
goes through a **÷13 divider** (12.0k / 1.00k, 0.1%, 25 ppm/°C thin film, 10 nF C0G): 192 mV full
scale, 2.93 µV per code. The bottom of every range is code 4771, where one code is 0.021%.

**Sinks.** OPA4388 (U7) sections A–D, one per channel. Each loop:

| Element | Value | Role |
| --- | --- | --- |
| Integrator | R_IN 1.00k from the Kelvin sense to −IN; C_C 2.2 nF C0G from output to −IN | The loop's compensation, identical on every channel |
| Gate drive | R_G 220 Ω at the gate | Isolates the FET's capacitance |
| Zero bias | 1.82 MΩ from a BIAS node (10k / 1k from +5VA, 1 µF): 250 µV | Worst-case code-0 input is 126 µV, so code 0 is firmly off |
| Gate clamp | 2N7002BK gate to ground, its gate pulled up to +3V3 by 100k | On in reset; holds the gate at 90–210 mV even with the op-amp at its rail |
| Gate monitor | 100k / 100k from the op-amp output, 1 nF at the ADC pin | Firmware sees when a channel is primed or short of headroom |

| | ch1 | ch2 | ch3 | ch4 |
| --- | --- | --- | --- | --- |
| Range | 140 mA–1.5 A | 14–160 mA | 1.4–16 mA | 5 µA–1.6 mA |
| Shunt | Vishay WSK2512 0.1 Ω, four-terminal | 10 × 10 Ω 0.1% 0805 in a ladder, Kelvin via net ties | 10 Ω 0.1% 0805 | 100 Ω 0.1% 0805 |
| FET | NDT3055L (SOT-223) | 2N7002BK | 2N7002 | 2N7002 |
| Clamp pin / monitor pin | PC6 / PA6 | PA8 / PA7 | PC10 / PB2 | PB7 / PB15 |
| Loop crossover (keep-alive, range bottom, band top) | 43 Hz, 8.3 kHz, 21.6 kHz | 46 Hz, 7.6 kHz, 20.5 kHz | 46 Hz, 16 kHz, 36 kHz | 46 Hz, 0.9 kHz at 5 µA, 54 kHz |
| Phase margin | ≥ 89° | ≥ 89° | ≥ 89° | ≥ 89° |
| Keep-alive current | 250 µA | 25 µA | 2.5 µA | 0.25 µA |

The small FETs are chosen for leakage: off channels leak straight through the LED, and at 5 µA
every nanoamp counts. Nexperia's 2N7002 specifies gate leakage ≤100 nA at ±15 V, where the
2N7002BK allows 10 µA at 20 V, so the 10 Ω and 100 Ω channels use the plain 2N7002.

## Board A: crossovers

Where two ranges meet (1.4–1.6 mA, 14–16 mA, 140–160 mA) both channels carry current.

1. **Keep-alive.** An armed channel regulates 25 µV above its calibrated dead-zone edge (25 µV / R_s,
   2.5 µA on the 10 Ω channel), which parks its integrator at the FET's threshold. The firmware
   subtracts the keep-alive current from the active channel. A channel arms once the level passes
   half its band's bottom, or when a fade will reach its band within 0.4 s; it disarms below a
   quarter. Channel 4 stays armed whenever the light is on.
2. **Priming** from the dead zone takes 70–320 ms (threshold 1.0–2.5 V); the gate monitor shows
   when it's done.
3. **Log-ratio blend.** Inside a band, ln(I_high / I_low) runs linearly in log(I), so each
   channel's share grows exponentially. The blend stays monotonic unless the two channels'
   calibrated gains disagree by more than 3.6%; after calibration they agree to about 0.1%.

| Full-range fade | Deviation at a crossover, as built | Without priming (the Phase 1 plan) |
| --- | --- | --- |
| 1 s | 0.9–1.5% for about 10 ms, while the light changes 1.3% per ms | 15–17% |
| 10 s | 0.11–0.14% | 3.1–3.7% |
| 60 s | ≤ 0.03% | — |

Simulated summed sink current against the intended curve, after a 1 ms low-pass (roughly what a
240 fps frame integrates). Fades update the DAC at 4 kHz; static levels never update.

## Board A: LED output, protection, off and on

*Sheet A5.*

**The cathode node.** J2 (pin 1 LED−, pin 2 LED+) has C_a, 22 nF 100 V X7R, across its pins; the
node carries the four drains and a 1 MΩ tap into 1 nF, clamped by a BAV199, to PA1. From 100 Hz
to 20 kHz, down to 5 µA, it now takes over 200 mV of V_out ripple to make 1% of LED-current
modulation, against 6.5 mV without C_a.

**Short.** PA1 is also COMP1's input, at a fixed 3.0 V from the internal DAC3; its interrupt
engages all four gate clamps in about 1 µs, 50–100 µs in all with the tap's RC. The trip is masked
only while the expected cathode voltage is above 2.6 V (V_out leading a turn-on) and for 3 ms
after; a V_f reading under 15 V catches a short on the next ADC pass. A V_out stuck at its
ceiling, which would put 16 W in the FET, trips it too.

**Open LED.** V_out reaches its ceiling while the cathode stays near 0 V: firmware drops to the
floor and reports it. With the default LED model that only happens near full output; see the
[firmware's known issues](FIRMWARE.md#known-issues).

**Off:** every sink in its dead zone and V_out at its 3.5 V floor, where the array can't conduct.

**On:** V_out rises first, then the sink comes up; C_a lifts the cathode about 16 V on the way up
and the sink pulls it back, with the LED current appearing only in the last 2 V and no overshoot.

| Turn-on target | Time to first light |
| --- | --- |
| 5 µA | about 52 ms |
| 140 µA | about 1.9 ms |
| 1 mA | about 0.26 ms |
| Above 1 mA | under 0.1 ms, plus the 0.6 ms V_out step |

**Fade to black.** Below the tail's end point (5 µA by default, adjustable), the sink holds just
above the remaining current and V_out keeps falling instead. The LED current then follows V_out
exponentially, at 1.5% per buck-DAC code and a decade per 1.5 V, down to picoamps before the
floor. There is no last step to see.

## Board A: MCU

*Sheet A6.* STM32G431CBU6 (Cortex-M4F, 170 MHz from the internal HSI16). The full pin map is in
the [build guide's appendix](BUILD_GUIDE.md#appendix-a-connectors-and-pinouts). Each VDD pin and
VBAT has 100 nF, with one 4.7 µF bulk; VDDA and VREF+ have 1 µF + 100 nF behind a ferrite. Four
NTCs (at the channel-1 FET, the main buck, the aux rails and the precision section) feed the
thermal limits. J4 is ST's STDC14 connector for the STLINK-V3MINIE, which also carries the
calibration console on its virtual COM port.

## Board A: accuracy

After calibration, with the board within ±20 °C of its calibration temperature:

| Range | Current | Sense | RSS | Worst case |
| --- | --- | --- | --- | --- |
| 1 (0.1 Ω) | 140 mA / 1.4 A | 14 / 140 mV | ±0.11% / ±0.10% | ±0.27% / ±0.20% |
| 2 (1 Ω) | 14 / 140 mA | 14 / 140 mV | ±0.09% / ±0.09% | ±0.23% / ±0.17% |
| 3 (10 Ω) | 1.4 / 14 mA | 14 / 140 mV | ±0.09% / ±0.09% | ±0.23% / ±0.17% |
| 4 (100 Ω) | 140 µA / 1.4 mA | 14 / 140 mV | ±0.11% / ±0.09% | ±0.28% / ±0.17% |
| Tail | 14 µA / 5 µA | 1.4 / 0.5 mV | ±0.6% / ±1.6% | ±1.3% / ±3.4% |

Range 4 and the tail include about 70 nA of board and FET leakage, which always adds current.
With the WSL2512 fallback for R102, range 1 widens to ±0.17% RSS. The biggest terms are the two
discrete 25 ppm/°C divider resistors, budgeted as if they drifted in opposite directions; a
matched network would tighten every range. None of this touches smoothness: one DAC code is
0.021% at the bottom of a range.

The module's own flux tolerance (±10%) is far larger, which is why fixtures are matched on light,
not just current ([build guide, section 12](BUILD_GUIDE.md#12-calibrate)).

## Board A: thermal

About 2.8 W at full output on 90 × 60 mm of 4-layer board in still air: +22 °C of average rise
over the enclosure air.

- **Channel-1 FET:** 1.2 W. On 5 cm² of its own copper (2.3 cm² on top, 2.8 cm² on the bottom,
  39 vias between), taken at 50 °C/W, its junction runs about 82 °C over the air: about 127 °C in
  45 °C air, against a 150 °C limit. (onsemi rates it at 42 °C/W on 6.5 cm² of 2 oz copper and
  95 °C/W on 0.4 cm².)
- **If it runs hot:** 0.8 V of headroom instead of 1.0 V at full current saves 0.28 W; a
  100 × 70 mm outline would take about 5 °C off the board's rise.

| NTC | Derate from | Trip at |
| --- | --- | --- |
| Channel-1 FET | 95 °C | 110 °C |
| Main buck | 90 °C | 105 °C |
| Aux rails | 90 °C | 105 °C |
| Precision section | 75 °C | 90 °C |

## Board A: layout

The layout rules, in full, are [`hardware/LAYOUT.md`](../hardware/LAYOUT.md). In short:

| Layer | Copper | Use |
| --- | --- | --- |
| L1 top | 1 oz | Every part; signals, both switch nodes, the Kelvin pairs, local power copper, Q1's tab copper, then a GND pour |
| L2 | 0.5 oz | GND, solid: no splits, no tracks |
| L3 | 0.5 oz | Signals, then a GND pour |
| L4 bottom | 1 oz | Signals, Q1's heat spreader under its tab, then a GND pour |

<picture>
  <source media="(prefers-color-scheme: dark)" srcset="images/floorplan-dark.png">
  Board A floorplan with seven zones
</picture>

- **Switch nodes** on L1 only, as small as the current allows, no vias; the input loops closed
  through L2 directly under each buck.
- **Kelvin pairs** start at each shunt's own sense points (R102's pads 2 and 3; net ties on the
  ladder and the 10 Ω and 100 Ω shunts); divider bottoms and their filter capacitors return to
  the sense-low net, never to the plane.
- **The precision island** is a ground cage: pour around and between its parts, stitching every
  3 mm, L2 solid under it. No 48 V-class net within 2 mm of a precision net (a DRC rule).
- **Leakage:** the cathode net compact and soldermasked, a 1 mm slot between J2's pads, and a
  mandatory wash after assembly.
- **High-voltage spacing** (IPC-2221B, 51–100 V): 0.5 mm wherever a bare pad is involved, 0.3 mm
  between coated tracks and on inner layers.

| Path | Current | As laid out |
| --- | --- | --- |
| +48V_RAW, J1 → F1 | 1.5 A | 2 mm, drawn |
| +48V, F1 → the bucks; VOUT | 1.5 A | 0.6 mm, routed (IPC-2221 minimum 0.53 mm) |
| CATHODE, J2 → Q1 | 1.5 A | The tab copper |
| SRC1, Q1 → R102 | 1.5 A | 1.5 mm, drawn; four vias at R102's ground end |
| +5V5 rails | 0.6 A | 0.5 mm |
| Signals, Kelvin pairs, logic rails | < 50 mA | 0.2 mm |

## Board B

A Waveshare ESP32-S3-Zero (ESP32-S3FH4R2: 4 MB flash, 2 MB PSRAM) in two 1 × 9 sockets on the back
of a 2-layer board. The module brings its own USB-C, 3.3 V regulator (ME6217C33, 800 mA) and
BOOT/RESET buttons, so Board B keeps only the power entry, the controls and the link.

Board B's back, with the two socket rows for the ESP32-S3-Zero

- **Power:** ribbon +5V5 (pins 1 and 3) through a 2 A ferrite and a B5819W Schottky to the
  module's 5V pin, about 5.1 V. The module's regulator makes +3V3 for the encoder pull-ups and the
  LEDs. The Schottky keeps a USB supply out of Board A; nothing keeps Board A's supply out of a
  computer, so the module is flashed out of its sockets.
- **Encoder:** Bourns PEC11R-4220F-S0024 (24 detents, push switch), with Bourns' recommended
  filter on A, B and the push: 10k pull-up, 10k series, 10 nF.
- **Sync:** a 6 × 6 mm tactile switch in parallel with a JST PH header for a panel button, same RC.
- **Status LED:** separate red, green and blue LEDs, active low, dimmed with 25 kHz PWM.
- **Antenna:** the module's antenna end sits at the board's edge over a copper keep-out; keep
  15 mm of clearance from metal, and the board at least 100 mm from Board A and the LED leads.
- **Layout:** 60 × 45 mm, 1.6 mm, 1 oz, ENIG; power tracks 0.3 mm, the rest 0.2 mm; GND poured on
  both sides.

GPIO assignments are in the [build guide's appendix](BUILD_GUIDE.md#appendix-a-connectors-and-pinouts).

## The ribbon link

A 10-way, 2.54 mm IDC ribbon, straight through, up to about 0.5 m (good to 1 m).

| Pin | Signal | Pin | Signal |
| --- | --- | --- | --- |
| 1 | +5V5 (A → B) | 2 | GND |
| 3 | +5V5 (A → B) | 4 | GND |
| 5 | UART, A → B | 6 | GND |
| 7 | UART, B → A | 8 | BOOT0 (B → A) |
| 9 | A_OK (A → B) | 10 | NRST (B → A, open-drain) |

UART at 115200 8N1 with 100 Ω series resistors at each end; the transmit line sits between two
grounds. BOOT0 and NRST let Board B reset Board A, and later reflash it through the STM32's ROM
bootloader (the bootloader client isn't written yet). A_OK has a 100k pull-down on Board B, so an
unplugged ribbon reads "not OK". The protocol is in [the firmware reference](FIRMWARE.md#the-link-between-the-boards).

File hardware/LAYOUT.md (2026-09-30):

# Layout guide

The scripts in `layout/` draw both boards in KiCad 9 by following this guide (`layout/README.md` says how to run them and what to check); the guide is also what to review their result against, or to draw a board by hand from `hardware/board_a.net` and `board_b.net`. It fixes everything that decides whether the boards work: layers, zones, loops, sense routing, widths and clearances. `board_a.kicad_dru` / `board_b.kicad_dru` hold the clearances as KiCad custom rules, with the net classes listed at the top. Coordinates are millimetres from each board's top-left corner.

## Board A: stackup and outline

JLCPCB's standard 1.6 mm four-layer stackup (7628 prepreg, about 0.2 mm from L1 to L2), ENIG. Nothing needs controlled impedance.

| Layer | Copper | Use |
| --- | --- | --- |
| L1 top | 1 oz | Every part. Signals, both switch nodes, the Kelvin pairs, local power copper, Q1's tab copper, then a GND pour |
| L2 | 0.5 oz | GND, solid. No splits, no tracks |
| L3 | 0.5 oz | Signals, then a GND pour over everything else |
| L4 bottom | 1 oz | Signals, Q1's heat spreader (CATHODE) under its tab, then a GND pour |

Routing some 200 parts on L1 and L4 alone left too many connections open, so L3 carries signals as well (an earlier version of this guide kept it for +48V and VOUT pours). Every L1 track still has the unbroken L2 plane under it, and the power paths are wide enough on L1 without the L3 pours (see the width table).

- 90.0 × 60.0 mm, 2 mm corner radius. Four non-plated M3 holes (3.2 mm, 6.5 mm keep-out on every layer) at (4, 4), (86, 4), (4, 56) and (86, 56). None connects to GND: the 48 V side stays unearthed (answer 4).
- Bottom edge: J1 (48 V in) between x = 70 and 80, J2 (LED out) between x = 36 and 48, wire entry facing off the board. J2's pin 1 is LED− (CATHODE, on the sinks' side) and pin 2 is LED+ (VOUT, on the buck's side), so neither path crosses the other. Top edge: J3 (ribbon) between x = 50 and 72. Left edge: J4 (STDC14).
- No heatsink: in the wood or plastic enclosure (your answer 4 in Phase 1) Board A cools through its own copper, 2.8 W at full, about 22 °C above the enclosure air on average (a 100 × 70 mm outline would take about 5 °C off that). Mount it on 10 mm standoffs with free air on both faces, near a vent. If it stands vertical, put the J1/J2 edge at the top so the power band's warm air doesn't rise across the precision island.
- Mount it within about 300 mm of the XTM, whose leads are 400 mm.

## Board A: floorplan

Top view, 1 character = 1 mm across, 1 line = 2 mm down:

```text
+-----------------------------------------------------------------------------------------+
| +-----------------------------------------+   +---------------------------------------+ |
| | MCU and debug                           |   | Aux rails and link                    | |
| | U1, J4 (left edge)                      |   | U3, L3, U5; J3 (top edge)             | |
| |                                         |   |                                       | |
| |                                         |   |                                       | |
| |                                         |   |                                       | |
| |                                         |   |                                       | |
| |                                         |   |                                       | |
| |                                         |   |                                       | |
| +-----------------------------------------+   |                                       | |
|   +---------------------------------------+   |                                       | |
|   | PRECISION ISLAND                      |   |                                       | |
|   | U6 DAC, U7 op-amp, dividers,          |   |                                       | |
|   | bias; U4 at the right edge;           |   +---------------------------------------+ |
|   | ground cage                           |   +---------------------+                   |
|   |                                       |   | Tracking buck       |                   |
|   |                                       |   | U2, L2,             +-----------------+ |
|   |                                       |   | C20-C30             | 48 V in         | |
|   |                                       |   |                     | J1, F1,         | |
|   +---------------------------------------+   |                     | D1, C1          | |
|   +-------------------------------+           |                     |                 | |
|   | Sinks                         |           |                     |                 | |
|   | Q1 + R102 on tab copper       +-----------+                     |                 | |
|   | Q2-Q4, R90-R101               | J2        |                     |                 | |
|   |                               | LED out   |                     |                 | |
|   |                               | + C60     |                     |                 | |
|   |                               |           |                     |                 | |
|   +-------------------------------+-----------+---------------------+-----------------+ |
|                                                                                         |
+-----------------------------------------------------------------------------------------+
```

Every part except the holes and fiducials sits in exactly one zone (checked against the netlist):

| Zone | Where | Parts |
| --- | --- | --- |
| 48 V in | x 70–90, y 34–60 | J1, F1, D1, C1, R1, TP1, TP8 |
| Tracking buck | x 48–70, y 30–60 | U2, L2, C20–C30, D2, R10–R17, RT2, TP5, TP10 |
| LED output | x 36–48, bottom edge | J2 with C60 across its pins; R110, the cathode end of the cathode tap |
| Sinks | x 4–41, y 37–60 | Q1 on its tab copper with R102 and RT1; Q2–Q4 in a row along the top edge of the tab copper, R100/R101 with NT3–NT6 above Q3/Q4; the R90–R99 ladder with NT1/NT2; R68–R71 at the gates, Q5–Q8 and R72–R75 where there's room between the island and the sinks |
| Precision island | x 4–44, y 22–40 | U6, U7, R44–R54, R60–R67, R76–R83, C40–C48, C50–C55, RT4, TP7, TP9, TP12–TP19; U4 with C10–C12 and TP3 at its right edge |
| MCU and debug | x 0–44, y 0–20 | U1, J4, C56–C59, C70–C78, C80–C83, FB1, C15, C16, R40–R43, R120–R129, D4, TP6, TP11; R18/C31, R2/C2 and C61/D3 at their ADC pins |
| Aux rails and link | x 48–90, y 0–28 | U3, L3, C3–C9, C13, C14, R3–R7, U5, FB2, C79, J3, RT3, TP2, TP4 |

The 1.4 A loop (buck → J2 → LED → sinks → shunts → back to the buck and J1) stays in the bottom band, so none of its return current crosses the precision island. Board B's supply current returns through J3 in the aux corner, also clear of it. Both switch nodes sit at least 10 mm from every precision net.

## Board A: power layout

1. U2's input loop: C22 (100 nF) right at U2's VIN pin with a GND via beside its other pad; U2's own GND reaches the same L2 plane through its exposed pad's vias, so the loop closes through L2 directly under the part. C20/C21 beside it. U3 has C5 at its VIN pin and C4 beside it. (EN sits between VIN and GND on these parts; a capacitor straddling both pins would wall EN in behind the HV spacing, so EN leaves through a via and +48V comes in from C20 between C22's GND pad and that via.)
2. Both switch nodes (BUCK_SW, AUX_SW) on L1 only, as small as the current allows, with no vias: 0.5 mm past the BOOT capacitor's pad, then 1.2 mm to the inductor, about 5 mm in all. BOOT capacitors C23 and C3 straight across BOOT and SW.
3. L2 against U2's SW pin. Only plane copper under either inductor, on every layer.
4. U2's feedback network (R12–R15, C29, C30) beside its FB pin, on the side away from L2. R12 takes VOUT at the output capacitors C24–C27, not at J2.
5. U2 and U3 exposed pads: the footprint's own thermal vias (0.2 mm) to L2, L3 and L4. These, a 3 × 3 array of 0.3 mm vias under U1's exposed pad and a single one in U6's 0.8 mm pad are the only vias in any pad, all tented on L4 so solder can't run through.
6. C60 (C_a) directly across J2's pins, above the slot. J2 pin 1 sits on the CATHODE tab copper; VOUT reaches pin 2 from the output capacitors, so the loop through the LED leads closes at the board edge.
7. Q1: CATHODE copper on L1 from its tab to J2 pin 1 (x 26–41, y 44.6–59.4: 2.3 cm²), joined by 39 vias of 0.3 mm to a heat spreader on L4 (x 22–41, same rows: 2.8 cm²). The vias are densest right beside the tab, where the heat enters the copper, and three sit under Q1's body on its middle pin's strip. Q2–Q4's drains, C60 and R110 touch its top edge. The router is kept out of both areas. onsemi rates the NDT3055L at 42 °C/W on 6.5 cm² of 2 oz copper and 95 °C/W on 0.4 cm²; for these 5 cm² of 1 oz over two layers `design/calc.py` takes 50 °C/W, which puts the junction about 82 °C above the enclosure air at 1.4 A, 127 °C at 45 °C air, against a 150 °C limit. It adds about 110 pF to the cathode, well inside the 1000 pF the ripple budget allows. RT1 beside Q1.
8. R102 at least 2 mm from Q1's tab copper. Its I− pad goes to GND with four or more vias at the pad and wide L1 copper toward the buck's GND.

## Board A: sinks and the precision island

1. **Kelvin pairs.** Each channel's SNSHIx and SNSLOx start at the shunt's own sense points below and run to the island in 0.2 mm tracks, ideally together, on L1 over the L2 plane, with the same number of vias on both. The divider bottoms (R46, R48, R50, R52) and the 10 nF C44–C47 return to SNSLOx, never to the plane. The layout script gets the start points right and leaves the rest to the router, which doesn't keep the two tracks side by side; at these slow signals where they start matters far more, but redrawing each pair side by side by hand is the one refinement worth making.
   - Ch1: R102's pads 2 and 3.
   - Ch2: the ten 10 Ω resistors R90–R99 as rungs between two 1 mm bus bars, SRC2 fed at one end and GND taken out at the opposite end so every rung sees the same path. NT1 at the SRC2 bar's midpoint, NT2 at the GND bar's midpoint.
   - Ch3 and ch4: NT3/NT4 on R100's pads, NT5/NT6 on R101's.
2. **Setpoints.** Each divider pair (R45/R46 and so on) side by side in the same orientation, so both resistors sit at one temperature; C44–C47 at U7's +IN pins. Only the divider tops load DAC_OUT1–4. C40 on U6's REF pin, and nothing else on that net.
3. **Op-amp.** C52–C55 (2.2 nF) and R60–R63 (1 kΩ) at U7's −IN pins; R64–R67 (1.82 MΩ) from BIAS straight to those pins; R53, R54 and C48 (the bias source) in the middle of the island. C50/C51 on U7's V+ pin; C41, C42 and C43 on U6's VDD and VIO.
4. **Gates.** R68–R71 (220 Ω) at the FET gates, not at the op-amp, with the clamp FETs Q5–Q8 and their pull-ups R72–R75 beside them. The gate-monitor dividers R76–R83 at U7's outputs, and C56–C59 at the MCU's ADC pins.
5. **Guarding.** The island is a ground cage: L1 GND pour around and between its parts, stitching vias every 3 mm across it and along its edges, L2 solid under it, and the GND pours of L3 and L4 filling around whatever tracks pass there. Every node inside sits within 0.2 V of GND, so the pour is also an equipotential guard. No HV-class net comes within 2 mm of a precision net (a DRC rule).
6. **Leakage at the bottom of the range.** At 5 µA, 50 nA of stray current is 1%. Keep the CATHODE net compact and soldermasked, cut a 1.0 mm non-plated slot, 6 mm long, between J2's two pads so flux or dirt can't bridge them, and wash the board after assembly.
7. **Temperature sensors.** RT2 between U2 and L2, RT3 between U3 and the LDOs, RT4 between U6 and U7.

## Board A: MCU

1. 100 nF on each VDD pin (C70–C73), C74 at the 3.3 V entry, C76 on VDDA (pin 21) and C77 on VREF+ (pin 20), fed through FB1. U1's exposed pad soldered and stitched to L2.
2. SPI series resistors at the driving end: R40–R42 at U1, R43 at U6's SDO.
3. The sense dividers put their high-voltage resistor at the high-voltage end and the rest at the MCU: R17 at the output capacitors with R18/C31 at PA0; R1 at +48 V with R2/C2 at PB0; R110 at the cathode with C61 and D3 at PA1. Each long trace then carries only a few volts, filtered at the pin.
4. BUCK_DAC (PA4) runs to R15 beside U2 over the plane and away from the switch nodes; C30 filters it at the buck.
5. Link: R121–R123 at U1; R120 (BOOT0 pull-down) and C78 (NRST) at their pins.

## Track widths and clearances

IPC-2221 widths for a 10 °C rise, from `design/calc.py`, and what the layout script uses. Routed tracks take their net class's width (the router can't widen a track where there's room), so the HV class is set to what still reaches U2's and U3's 1.27 mm-pitch pins with the HV spacing; the paths drawn before routing are wider.

| Path | Current | Minimum on L1 (1 oz) | As laid out |
| --- | --- | --- | --- |
| +48V_RAW: J1 → F1 | 1.5 A | 0.53 mm | 2 mm, drawn |
| +48V: F1 → U2, U3 | 1.5 A | 0.53 mm | 0.6 mm, routed (HV class) |
| VOUT: L2 → C24–C27 → J2 pin 2 | 1.5 A | 0.53 mm | 0.6 mm, routed (HV class) |
| CATHODE: J2 pin 1 → Q1 | 1.5 A | 0.53 mm | the tab copper (a pour) |
| SRC1: Q1 → R102 | 1.5 A | 0.53 mm | 1.5 mm, drawn; R102's GND end has four vias |
| BUCK_SW | 1.5 A rms, 1.84 A peak | 0.53 mm | 0.5 mm past C23's BOOT pad, then 1.2 mm; drawn |
| SRC2 and GND bus bars | 0.16 A | — | 1 mm, drawn, for rung symmetry rather than current |
| +5V5, +5V5_LINK | 0.6 A | 0.15 mm | 0.5 mm, routed (Aux class) |
| AUX_SW | 0.6 A | 0.15 mm | 0.5 mm, then 0.8 mm; drawn |
| Signals, Kelvin pairs, +3V3, +3V3A, +5VA | < 50 mA | — | 0.2 mm, to reach the 0.5 mm-pitch QFN pins |

- Vias: 0.2 mm drill, 0.5 mm pad for signals and for each GND pad's own via to the L2 plane, placed before routing while there's still room beside every pad (JLCPCB's four-layer minimum is 0.2 mm / 0.45 mm, so this is standard pricing); 0.3 mm drill, 0.6 mm pad on the HV and Aux nets and for the stitching vias, which sit every 3 mm across the board wherever there's room.
- HV-class nets (+48V_RAW, +48V, VOUT, BUCK_SW, BUCK_BOOT, AUX_SW, AUX_BOOT, CATHODE), from IPC-2221B's Table 6-1 for 51–100 V: 0.5 mm to any other net where a bare pad is involved (A6, component terminations), 0.3 mm between copper under solder mask on L1 and L4 (B4 asks 0.13 mm), 0.3 mm on L2 and L3 (B1 asks 0.1 mm). The router keeps 0.5 mm throughout, since it can't tell a pad from a track. (An earlier version used 0.6 mm everywhere, B2's figure for bare copper conductors, which these boards don't have outside the pads; it walled U2's EN pin in.) Everything else 0.2 mm. Checked against KiCad 9's footprints, every part's own pins meet 0.5 mm: the tightest are the SOT-23 sinks Q2–Q4, 0.53 mm from the drain (CATHODE) to the gate and source pads (the rules file exempts them anyway, since a part sets its own pin spacing), then 0.645 mm from U2's and U3's lead pads to their exposed pads.
- Copper 0.5 mm from the board edge, pours 1 mm.

## Fabrication, silkscreen and cleaning

- Order: 4 layers, 1.6 mm, JLC's standard stackup, ENIG, 1 oz outer and 0.5 oz inner, tented vias, and a 0.12 mm stencil. The layouts don't reserve a spot for JLC's order number: have it removed, or let JLC place it (it's only silkscreen). The KiCad footprints split the paste on the exposed pads of U1, U2, U3 and U6 into windowpanes that keep paste off their vias.
- Silkscreen: +48V and − at J1; LED+ (red) and LED− at J2; pin-1 marks on J3, J4, U1, U6 and U7; a 48 V warning at J1; board name and revision.
- After assembly, wash the board with isopropyl alcohol and a soft brush, especially around J2, the CATHODE net, the sinks and the precision island, then dry it warm (50 °C, 30 minutes). Flux residue between a 40 V node and the cathode is the one thing that can visibly shift the bottom of the range.

## Board B

1.6 mm, two layers, 1 oz, ENIG: parts, signals and a GND pour on top, a GND pour on the bottom. 60.0 × 45.0 mm with a 2 mm corner radius; non-plated M3 holes at (4, 41) and (56, 4), with the encoder's panel nut as the third fixing.

The ESP32 is a Waveshare ESP32-S3-Zero, bought with its pin headers fitted (ESP32-S3-Zero-M), plugged into two 1×9 2.54 mm female headers 15.24 mm apart on the **bottom** of the board. It brings its own USB-C, 3.3 V regulator and BOOT/RESET buttons, and comes out of its sockets to be flashed. It hangs behind the board because the operator panel sits on the encoder, only a few millimetres above the top side, while the module on its sockets stands 12–14 mm tall: allow that much, plus a millimetre or two, behind Board B in the enclosure.

| Part | Where |
| --- | --- |
| U1 ESP32-S3-Zero on two 1×9 sockets | Bottom side, centred at (48.1, 33.0), long axis across the board: its antenna end at the right-hand edge, its USB-C end pointing into the board. Pins 1–9 (5V, GND, 3V3, IO1–IO6) along y = 25.4 from x 37.9 to 58.3; pins 10–18 (IO7–IO13, RX, TX) back along y = 40.6. No copper on either layer under the antenna end (a keep-out in the footprint); the silkscreen on the back names the module and marks both ends |
| SW3 encoder | Top-left, shaft and nut through the operator panel |
| D3–D5 with R15–R17, SW4 | Below the encoder, visible and reachable through the panel; J3 (external sync button) in the top-left corner |
| J1 ribbon with R18–R23 | Left edge, the series resistors and R22 at the connector |
| FB1, D1, C1, C3 | Between J1 and U1; C1 at U1's 5V pin, C3 at its 3V3 pin |
| R7–R14, C8–C11 | R7, R9, R11, R13 at the encoder; R8, R10, R12, R14 and C8–C11 at U1's IO4–IO7 |
| J4, TP1–TP3 | Bottom edge and bottom middle |

- Power: Board A's +5V5 through FB1 and D1 to U1's 5V pin, which is also the module's USB supply. D1 keeps USB power out of Board A; nothing keeps Board A's supply out of a computer plugged into the module, so the module is flashed out of its sockets, or with the ribbon unplugged.
- Power tracks 0.3 mm (0.5 A at most), everything else 0.2 mm.
- The two sockets must be exactly parallel: solder them with the module plugged in.
- If the enclosure is metal, the antenna end needs a plastic window or 15 mm of clearance to the metal (Espressif's figure for its modules).
- Mount Board B at least 100 mm from Board A and from the LED leads.

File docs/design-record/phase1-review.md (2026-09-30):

# 4-decade LED driver — Phase 1 design review

26 September 2026

> **About this document.** This is the Phase 1 design review as it was written, before any
> schematic existed: Claude's critique of my original brief, addressed to me, with my answers to
> its questions recorded at the end. It's kept as a record of *why* the design looks the way it
> does. The Phase 2 design ([phase2-detailed-design.md](phase2-detailed-design.md)) supersedes it
> wherever the two differ, and the files in the repository supersede both. Section numbers like
> "3.2" refer to sections of my brief.

## Summary

The architecture is sound, but three locked decisions should change before layout. The biggest is PWM for the bottom decade: both of its stated benefits fail on analysis, and a fourth DC range does the job better.

1. **Forced-PWM buck, not pulse-skipping.** Capacitance at the LED cathode turns audio-band V\_out ripple into LED current that no sink sees: 20 mV at 10 kHz is 0.9% flicker at 140 µA.
2. **A fourth DC range (100 Ω) instead of PWM.** Leakage error is I\_leak / I\_avg either way, and the cathode's capacitance keeps the LED conducting at microamp levels between pulses regardless. DC puts no intentional modulation on the LED and fades smoothly to about 5 µA.
3. **Headroom control moves into the Board A MCU, with feed-forward.** A slow loop can't follow a snap cue; the MCU raises V\_out before it raises current.
4. **Smaller changes:** a 100 W supply instead of 60 W (worst case is 56 W); a static blend instead of hysteresis; a fast comparator trip, because a shorted LED puts all of V\_out across the active FET; a \~3 V floor on V\_out so "off" is truly dark; and a zero bias plus gate clamps so code 0 really means off.

After calibration every range holds about ±0.05–0.08% RSS (±0.15% worst case), and 140 µA holds ±0.08% plus whatever the XTM leaks internally. The module's own ±10% flux tolerance dwarfs that, so the driver's precision buys smoothness and monotonicity; matching fixtures needs one light gain each.

Your answers are recorded below. The detailed design continues in the Phase 2 doc, which supersedes this review where the two differ.

## Block diagram

```mermaid
flowchart TB
  psu["Isolated 48 V supply<br/>(off-board, 100 W)"] -->|48 V| buck["Tracking buck<br/>forced PWM, 400 kHz"]
  psu -->|48 V| aux["Aux buck + LDOs"]
  buck -->|"V_out = V_f + headroom"| led(["XTM LED array"])
  subgraph S["Four parallel linear sinks, one per decade"]
    direction LR
    s1["0.1 Ω"] ~~~ s2["1 Ω"] ~~~ s3["10 Ω"] ~~~ s4["100 Ω (new)"]
  end
  led -->|cathode| S
  dac["Quad 16-bit DAC"] --> S
  mcu["Board A MCU<br/>fades, ranging, headroom, faults"] --> dac
  mcu -->|"own DAC → FB"| buck
  led -.->|"cathode read-back, fast trip"| mcu
  mcu ---|"UART ribbon: level, fade, status"| esp["Board B: ESP32-S3 + ESPHome<br/>encoder, sync button"]
```

Board A owns every real-time decision: it sets V\_out ahead of each current change, reads the cathode node back, and runs the fades. Only a level, a fade time and status cross the ribbon to Board B. The mains never touches either board.

## Critique of the locked decisions

Three locked decisions should change before schematic capture: the buck must not pulse-skip, the bottom decade should be a fourth DC range instead of PWM, and the headroom loop should run in the Board A MCU with feed-forward. The rest stand, with the notes below.

| Locked decision | Verdict | Why, in one line |
| --- | --- | --- |
| 3.1 Isolated 48 V module, no mains on the boards | Keep; raise the rating to 75–100 W | Worst-case load is \~56 W before temperature derating |
| 3.2 Buck may be asynchronous and pulse-skip | Change: synchronous, forced-PWM, fixed frequency | Audio-band V\_out ripple reaches the LED through cathode-node capacitance |
| 3.2 Slow analog headroom loop with a DAC reference | Change: digital loop in the MCU, with feed-forward | A slow loop can't follow snap cues |
| 3.2 OVP \~40 V, soft-start, shorted LED "falls out" | Keep OVP and soft-start; add a fast comparator trip and a \~3 V V\_out floor | A short doesn't fall out: all of V\_out lands across the active FET |
| 3.3 Three parallel linear sinks | Keep; add a zero bias and gate clamps; accept ±35 ppm/°C on the 0.1 Ω shunt | DAC code 0 is not reliably "off"; the best four-terminal 0.1 Ω part I found is ±35 ppm/°C |
| 3.4 Crossfade with hysteresis | Keep the crossfade; drop the hysteresis | A static blend has nothing to hunt |
| 3.5 PWM on the low channel for the bottom decade | Change: a fourth DC range, 100 Ω | Both stated benefits fail; PWM adds flicker risk |
| 3.6 16-bit quad DAC, log curve | Keep; the DAC serves four sinks | The buck setpoint moves to the MCU's own DAC |
| 3.7 ESP32 + ESPHome on Board B | Keep | See the ESPHome section |

### Buck ripple reaches the LED even with ideal sinks

The sinks hold their own currents, but capacitance from the LED cathode to ground outside the active loop — off-channel FET C\_oss, the leads, the module-to-heatsink path — must be charged through the LED whenever V\_out moves. That displacement current flows through the emitting junctions, and no sink sees it.

```latex
i_{LED} \approx 2\pi f\,C_n\,v_{out}\quad (f \ll f_c),\qquad f_c = \frac{1}{2\pi r_d C_n},\qquad r_d = \frac{n\,N\,V_T}{I}
```

With C\_n ≈ 1 nF and nNV\_T ≈ 0.65 V (about ten dies in series, ideality \~2.5), r\_d is 4.6 kΩ at 140 µA and f\_c is about 34 kHz. A pulse-skipping buck that ripples 20 mV at 10 kHz pushes 1.3 µA through the LED: 0.9% of 140 µA, the whole flicker budget from one source.

- "Ripple stays inside the headroom margin" is necessary but not sufficient. At the bottom of the range the limit is ripple amplitude times frequency.
- Fix: a synchronous buck locked in forced-PWM at a fixed ≥400 kHz, so ripple sits far above 20 kHz, plus a small output LC stage.
- At the switching frequency the cathode node is effectively grounded, so the LED sees v\_out / (nNV\_T): about 1.5% at 400 kHz for 10 mV of ripple before the LC stage. That is out of band, and the LC stage takes it below 0.1%.
- Keep C\_n small. A small-die high-channel FET helps here and with leakage.

### The PWM rationale does not survive, so use a fourth DC range

Both stated reasons for PWM fail once the off-phase is modeled.

1. **Leakage.** Off-channel leakage flows through the LED continuously, off-phase included. Its error is I\_leak / I\_avg in either scheme: 1 µA is 0.7% at a 140 µA average whether that average comes from PWM or DC.
2. **"The LED only sees ≥1.4 mA."** When the sink turns off, the LED keeps conducting while it charges C\_n. The current decays as I₀ / (1 + t/τ), with τ = C\_n·nNV\_T / I₀ ≈ 0.46 µs.

```latex
Q_{tail} = I_0\,\tau\,\ln\!\left(1 + \frac{T_{off}}{\tau}\right) \approx 1.4\,\text{mA} \times 0.46\,\mu\text{s} \times \ln 79 \approx 2.8\,\text{nC}
```

That is half the 5.6 nC delivered per pulse at 25 kHz and 10% duty, spread over currents from 1.4 mA down to microamps. The array does run in the microamp regime.

PWM also costs something:

- **Pulse-charge error.** Gating the reference loses roughly 0.5 µs per pulse while the op-amp leaves its negative rail and slews to V\_th. That is \~12% of a 4 µs pulse, and it drifts with V\_th's tempco.
- **Phone banding.** At 1/8000 s a sensor row integrates about three 25 kHz periods, so rows can differ by up to \~30% of this fixture's light.
- **Interactions.** The buck beats against the PWM unless it's synced, and the headroom loop must sample in step with the pulses.

The fourth range is a 100 Ω shunt covering 140 µA–1.4 mA at the same 14–140 mV sense voltage.

- Cost: one small FET, one precision resistor, the quad op-amp's fourth section, and the DAC's fourth channel. The headroom loop no longer needs either, because it moves into the MCU.
- The LED is DC at every level: no intentional modulation, and no phone banding.
- Below 140 µA it keeps dimming on calibrated offset to about 5 µA before switching off, so the last step is 28× smaller than the 0.01% one PWM would leave. At 5 µA the lens still glows faintly if you look straight into it, but the light it throws is negligible.
- One genuine argument for pulsing remains. The blue pump's spectrum shifts with current density, so CCT at 140 µA DC may differ slightly from 1.4 mA pulses. On a remote-phosphor module I expect this to be small; bring-up checks it against the phone's white balance.

If you keep PWM, I'd build it with current steering (the 1.4 mA sink never turns off; a make-before-break FET pair diverts it), a buck clock synced to the PWM, and headroom sampled at the end of each on-phase.

### A slow headroom loop can't follow snap cues

The datasheet's typical V\_f rises from 27.9 V at 500 mA to 29.9 V at 1.4 A, and further from 140 mA. A snap from 10% to full would bottom out the high-channel sink until a slow loop caught up. The cue would lag, then overshoot as the op-amp recovers from saturation.

- The Board A MCU raises V\_out first, to a learned V\_f(I, T) plus headroom, waits 1–2 ms, then ramps current. Going down, it lowers current first, then V\_out.
- A slow integral trim (\~1 Hz) only corrects the V\_f model, so the loop stays much slower than the sinks.
- The MCU reads the cathode node through a high-impedance path, never a resistive divider: a 1 MΩ divider at 1 V steals 1 µA, or 0.7% at 140 µA.
- The MCU's own DAC sets V\_out through FB injection, arranged so an MCU in reset (DAC pin high-impedance) drops V\_out to its \~3 V floor and the LED goes dark.

### OVP, open LED, shorted LED, and "off"

- **Open LED.** The sinks pull the cathode to 0 V and the loop drives V\_out to its ceiling. The FB network makes \~39 V the highest V\_out that can be commanded; a TVS covers transients, and firmware flags "V\_out at ceiling, no headroom".
- **Shorted LED.** This doesn't fall out naturally. The sinks still limit current, but all of V\_out (\~31 V) lands across the active FET: about 43 W at full output. An on-chip comparator watches the cathode against a threshold firmware sets just above the expected headroom, and trips the gate clamps within microseconds. Retries run with V\_out at its \~3 V floor, where the FET sees at most 1.4 A × 2.9 V ≈ 4 W, and firmware reports the short once V\_f reads under 15 V.
- **Off.** If V\_out stays at operating voltage, 10–100 nA of off-channel leakage keeps the module faintly lit, which shows in a blackout. Off means every sink off and V\_out at its floor.

### Sinks: keep, but zero code is not reliably off

- The DAC80504's zero-code error (0.5 mV typical, 1.5 mV max) is 33–100 µV after the divider. With op-amp offset, that leaves the 0.1 Ω channel conducting 0.3–1 mA at code 0.
- Fix: a deliberate \~+200 µV bias on each inverting input so code 0 is firmly off, plus a gate-clamp FET per channel that defaults on while the MCU is in reset. Calibration absorbs the bias.

### Handover: keep the crossfade, drop the hysteresis

Make the split a fixed function of the total current: all on the lower channel below the band, all on the upper channel above it, a linear blend inside. With no state there is nothing to hunt, so hysteresis has no job.

- The blend stays monotonic unless the two channels' gains disagree by about 6% in opposite directions. After calibration they agree to \~0.05%.
- Bands at 1.4–1.6 mA, 14–16 mA and 140–160 mA: each lower channel runs to 160 mV of sense, and the upper channel starts from zero.

### Absolute accuracy is set by the module, not the driver

The XTM's lumen output is ±10% of typical ([datasheet](https://www.xicato.com/wp-content/themes/xicato/documentuploads/DS%20XTM%20Standard%20Series%20062723.pdf)), so four fixtures at identical current can differ by up to 20% in light. The driver's \~0.05% matters for smoothness and monotonicity. For fixture matching, store one light-output gain per fixture, measured with a photodiode.

## Questions for you

Your answers, from 26 September. Question 14 went unanswered, so its default stands.

| # | Question | Your answer |
| --- | --- | --- |
| 1 | Replace PWM with a fourth DC range (100 Ω, 140 µA–1.4 mA)? | Yes |
| 2 | Accept the other changes: forced-PWM buck, digital headroom loop with feed-forward, 100 W supply, no hysteresis, and a ±35 ppm/°C four-terminal 0.1 Ω shunt? | Yes |
| 3 | Can you run the five-step XTM bench test before layout? | Yes, but keep testing to a minimum, so assumptions replace the tests |
| 4 | Is the fixture enclosure metal, and is the chassis or LED heatsink earthed? | Wood or plastic; metal only where heatsinking needs it; earthing if required |
| 5 | How far is Board A from the XTM and from Board B, and is there chassis area for a gap pad? | No fixed distances; the physical form is flexible |
| 6 | What is the fastest cue you need, and the slowest fade? | My call, without going to extraordinary lengths |
| 7 | Maximum air temperature inside the fixture, and is haze or fog used? | No haze or fog; temperature depends on the material, from common 3D-printing plastics to laser-cut stock |
| 8 | Venue network: one access point? Home Assistant? Standalone operation? | Default: one access point, Home Assistant usually present, every fixture fully standalone |
| 9 | What should the sync button do? | Toggling on makes every other fixture match this one; ownership moves to whoever toggles on |
| 10 | On losing the link to Board B, hold the last level or fade out? | Blink and drop to 20% |
| 11 | Do you want a footprint for a future DMX512 input? | No |
| 12 | What test gear do you have? | A university electronics lab's bench equipment |
| 13 | Match fixtures on current only, or also store a light gain per fixture? | Lux at a set distance and a couple of levels, if that stays simple; otherwise current only |
| 14 | Mains: US 120 V, with a fused IEC inlet and the supply inside each fixture? | Not answered; the default (yes) stands |

## Error budget per range

After per-channel gain and offset calibration, every DC range holds about ±0.05–0.08% (RSS) of reading, ±0.15% worst case, with the board within ±20 °C of its calibration temperature. The bottom of the 100 Ω range adds leakage; absolute light is limited by the module's ±10% flux tolerance, not by the driver.

The DAC80504 runs at gain 1 (2.5 V full scale) into a ÷15 matched divider, so every range sees 0–167 mV of sense and one LSB is 2.54 µV. Each range spans codes of roughly 5,500 (14 mV) to 63,000 (160 mV).

**Offset-type errors** (µV at the sense node, fixed in size, so worst at the bottom of each range):

| Source | Budget | At 14 mV sense | At 140 mV sense |
| --- | --- | --- | --- |
| Op-amp offset drift, budgeted at 10× the OPA4388's 0.005 µV/°C typical, over 20 °C | 1.0 µV | 0.007% | 0.0007% |
| DAC INL left after a 2-point calibration (±1 LSB max) | 2.5 µV | 0.018% | 0.0018% |
| DAC offset drift, ±1 µV/°C per the datasheet with 1.5× margin, over 20 °C, ÷15 | 2.0 µV | 0.014% | 0.0014% |
| Thermal EMF at shunt terminations (2 µV on the 0.1 Ω channel) | 1.0 µV | 0.007% | 0.0007% |
| Op-amp bias current (≤500 pA) into \~1 kΩ | 0.5 µV | 0.004% | — |
| **RSS** | **3.5 µV** | **0.025%** | **0.0025%** |

**Gain-type errors** (ppm of reading, the same at every level in a range):

| Source | Budget |
| --- | --- |
| DAC80504 reference, 5 ppm/°C max (2 typical), plus its 1 ppm/°C gain drift, over 20 °C | 120 ppm |
| Divider ratio tracking, ≤5 ppm/°C matched network, over 20 °C | 100 ppm |
| 1, 10 and 100 Ω thin-film shunts at ±25 ppm/°C over 20 °C | 500 ppm |
| 0.1 Ω WSK2512 four-terminal strip, ±35 ppm/°C guaranteed, over 20 °C | 700 ppm |
| 0.1 Ω self-heating at 1.4 A (196 mW, about +12 °C): 410 ppm raw, \~100 ppm after a quadratic calibration term | 100 ppm |

With ±10 ppm/°C thin-film parts the 1–100 Ω shunt line drops to 200 ppm, and ranges 2–4 fall to about ±0.04% RSS.

**Result per range, after calibration:**

| Range | Shunt | Current | Sense | RSS | Worst case |
| --- | --- | --- | --- | --- | --- |
| 1 | 0.1 Ω | 140 mA | 14 mV | ±0.08% | ±0.15% |
| 1 | 0.1 Ω | 1.4 A | 140 mV | ±0.07% | ±0.11% |
| 2 | 1 Ω (10 × 10 Ω) | 14 mA | 14 mV | ±0.06% | ±0.12% |
| 2 | 1 Ω | 140 mA | 140 mV | ±0.05% | ±0.08% |
| 3 | 10 Ω | 1.4 mA | 14 mV | ±0.06% | ±0.12% |
| 3 | 10 Ω | 14 mA | 140 mV | ±0.05% | ±0.08% |
| 4 | 100 Ω | 140 µA | 14 mV | ±0.08% incl. leakage | ±0.17% |
| 4 | 100 Ω | 1.4 mA | 140 mV | ±0.05% | ±0.08% |
| Tail | 100 Ω | 14 µA | 1.4 mV | ±0.6% | ±1.1% |
| Tail | 100 Ω | 5 µA | 0.5 mV | ±1.6% | ±2.9% |

- The range-4 and tail rows include the \~70 nA of estimated leakage from the next section, which always adds current. They exclude any leakage inside the XTM itself until it is measured.
- Absolute accuracy also carries the calibration reference: about ±0.05% for a 6½-digit DMM reading a four-terminal reference resistor. Relative matching between fixtures calibrated on the same meter is better.
- Inside a blend band the error is a weighted mix of two channels' errors, so it never exceeds the worse of the two.

**Smoothness and monotonicity.** One DAC code at the bottom of a range is 0.018% of reading, about 50× below a \~1% brightness step anyone could see. The DAC80504 is specified monotonic, and the static blend stays monotonic unless two channels disagree by \~6%, so the whole transfer curve is monotonic down to the tail.

**Flicker, 100 Hz–20 kHz, at the worst point (140 µA):**

| Source | Estimate | Basis |
| --- | --- | --- |
| Buck switching ripple through C\_n | out of band | Forced-PWM buck at a fixed 400 kHz puts nothing in the audio band |
| 48 V supply ripple, including burst mode at light load | target <0.1%, measured at bring-up | Input LC filter plus the buck's line rejection, then i = 2πf·C\_n·v |
| Op-amp, DAC and divider noise in a 20 kHz bandwidth | \~0.01% rms | \~1.4 µV rms from the op-amp (7 nV/√Hz), the DAC (78 nV/√Hz ÷ 15) and the divider, against 14 mV of sense |
| Headroom trims | not flicker | \~1 Hz trims of a few tens of mV, RC-filtered; each moves \~30 pC through C\_n |
| DAC updates during fades | not flicker | 1 kHz updates of an intended change |

What this sets for Phase 2: audio-band ripple on V\_out must stay under about 6 mV. In the tail r\_d is so high that above \~1 kHz the LED sees v/nNV\_T directly, and 6.5 mV is 1% at 5 µA.

## Low-end integrity

On a clean board the stray currents at the cathode node total about 70 nA at 55 °C, or +0.05% at 140 µA. Board contamination can make that 100× worse, and the XTM's own internals are unknown until measured, so both get first-class treatment.

| Path | Effect on LED current | Estimate, 55 °C, clean board | At 140 µA | Basis |
| --- | --- | --- | --- | --- |
| 0.1 Ω channel FET (NDT3055L), off at V\_DS ≈ 1 V | adds | ≤\~65 nA | +0.046% | Only hot guarantee: 50 µA at 60 V and 125 °C. Scaled at least 2× per 10 °C down to 55 °C, then \~√(V + 0.7 V) down to 1 V |
| 1 Ω and 10 Ω channel FETs (2N7002BK, 2N7002), off | adds | \~5 nA total | +0.004% | Both guaranteed ≤10 µA at 150 °C; scaled the same way |
| Board surface, anode (up to 37 V) to cathode node | subtracts | 4 nA at 10 GΩ; 370 nA at 100 MΩ with flux and humidity | −0.003% clean, −0.26% dirty | Why cleaning and guarding are mandatory |
| 100 Ω channel's own gate leakage, into its shunt | subtracts | ≲1 nA | \~0 | 2N7002: ≤100 nA guaranteed at ±15 V, and it runs near 2 V. Not the 2N7002BK, which allows 10 µA at 20 V |
| Cathode sense path (clamp diodes, ADC pin) | either sign | ≤2 nA | ≤0.001% | High-impedance tap, no resistive divider |
| Op-amp bias into the sense node | either sign | ≤0.5 nA | \~0 | OPA4388 ≤500 pA |
| Protection element inside the XTM, if any | subtracts (bypasses the dies) | unknown | unknown | Measure before layout |

Datasheets bound FET leakage only at rated voltage, and the NDT3055L's 1 µA limit at 25 °C is a test floor that, read literally, would allow \~0.5 µA here. The tracking buck keeps every off channel near 1 V, which is what makes a power FET usable at 140 µA at all. Bring-up measures the real number, and a FET that exceeds its budget gets swapped.

### Board leakage: layout, guards, cleaning

- Keep V\_out (the anode net, up to 37 V) and the 48 V net on the opposite side of Board A from the cathode node and every sense node, at least 5 mm apart, with an exposed ground guard trace between them.
- Ring each op-amp's inputs, the divider taps and the feedback nodes with exposed guard traces tied to analog ground. Those nodes sit at 0–167 mV, so a ground guard is within 167 mV of what it protects.
- Make the cathode node one compact copper island carrying only the four drains, the LED connector's cathode pin and the sense tap.
- Use an LED connector with at least 5 mm between anode and cathode, such as a 5.08 mm pluggable terminal block.
- After all soldering, strip every trace of flux from the analog region with a dedicated flux remover and a brush, rinse with isopropyl alcohol, and bake 1 h at 60–70 °C.
- Bring-up verifies it: with the LED unplugged and all sinks off, the cathode node must leak under 10 nA at 25 °C.
- Then conformal-coat the analog region with an acrylic coating. Venues are humid and haze fluid leaves glycol films; keep silicone-based products away, since silicone oil is on the XTM's avoid list.

### The XTM's internals: assumptions instead of tests

Per your note, nothing gets measured before layout. The design assumes the XTM bypasses at most \~50 nA at operating voltage, has a low-current slope nNV\_T near 0.65 V, and puts no more than 1 nF between its cathode and ground. None of these changes the circuit. If the very bottom of a fade shows a jump or a dropout, raise the tail's end point, which is one firmware setting.
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

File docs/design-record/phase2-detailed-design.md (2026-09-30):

# 4-decade LED driver — Phase 2 detailed design

30 September 2026

> **About this document.** This is the Phase 2 detailed design as it was written: every value on
> both boards, the reasoning behind it, and the bring-up, calibration and flicker procedures,
> addressed to me and built on my answers to the [Phase 1 review](phase1-review.md). It's the
> most complete single description of the design. Paths are relative to the repository root.
> The only edits since: the embedded floorplan is now an image, two notes about KiCad versions and
> the ESP32 footprint are brought up to date, and a location is generalised.
>
> **Errata, found later.** Where these differ, follow the [build guide](../BUILD_GUIDE.md):
> - Bring-up step 4 should use `b 1`, not `b 0.3`: the firmware only flags an open LED once V_out
>   reaches its ceiling, which happens near full output. Follow it with `reboot` to discard the
>   corrections learned with nothing connected ([known issues](../FIRMWARE.md#known-issues)).
> - The console prints faults as numbers (`fault=1` short, `fault=2` open), and the LED voltage is
>   `vout` minus `vcath`.
> - In step 5, `b 0 10000` ends at 5 µA, not dark; use `lvl 0 10000`.
> - Restoring a calibration by hand needs a final `save`.
> - The layouts don't mark a spot for JLC's order number, and U6's footprint splits its paste
>   into four windows.
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

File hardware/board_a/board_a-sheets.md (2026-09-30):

# Board A (driver): sheet tables

Generated by `design/build.py` from `design/board_a.py`. Every pin of every part is listed; `NC` means deliberately unconnected. Net names in CAPS match the KiCad netlist.

## Sheet A1: Power entry and auxiliary rails
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

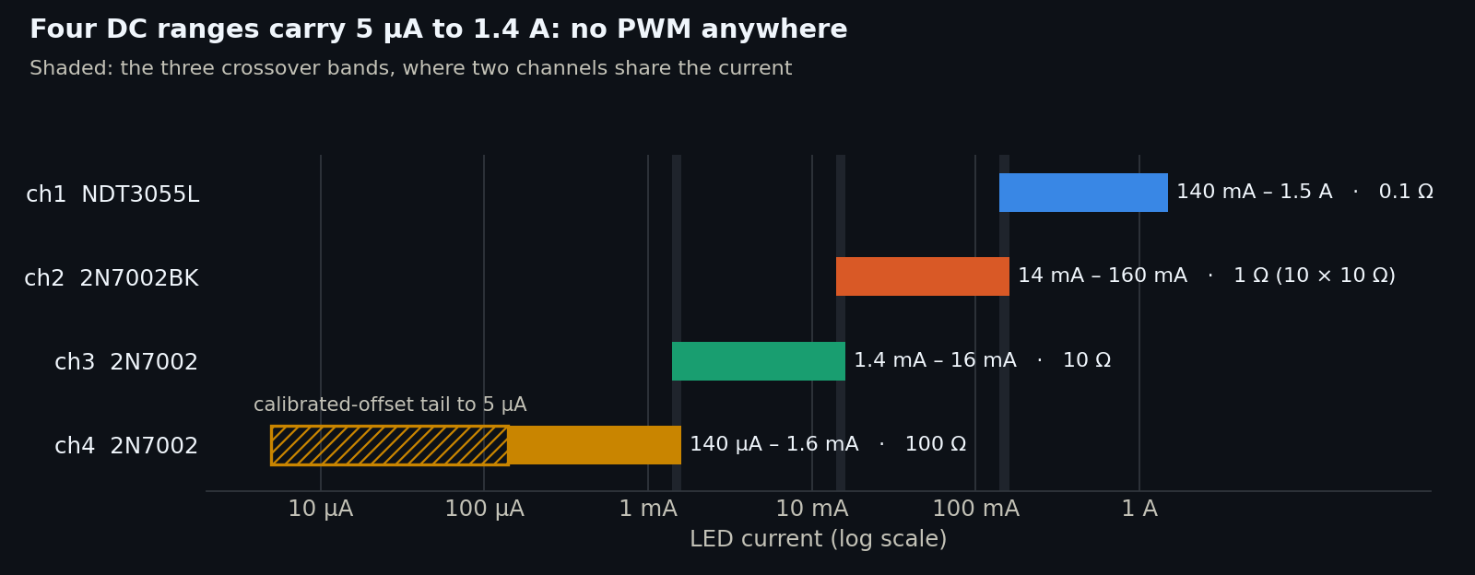
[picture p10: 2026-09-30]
docs/images/ranges-dark.png

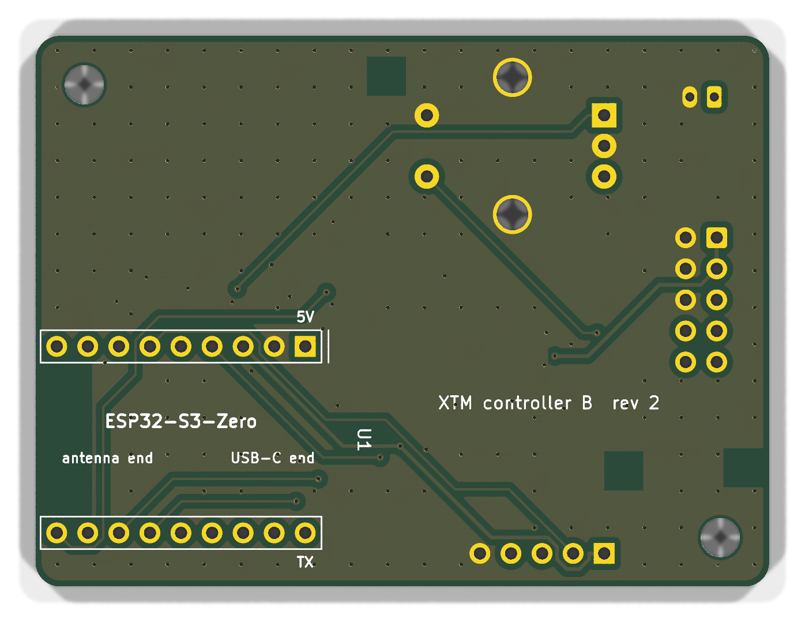
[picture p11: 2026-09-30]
docs/images/board-b-bottom.png

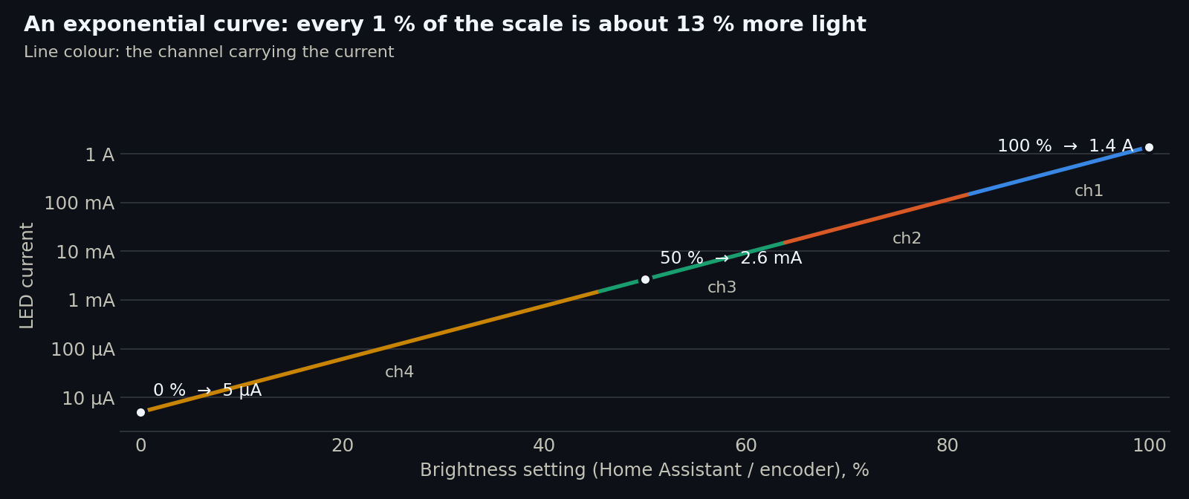
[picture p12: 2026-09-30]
docs/images/curve-dark.png

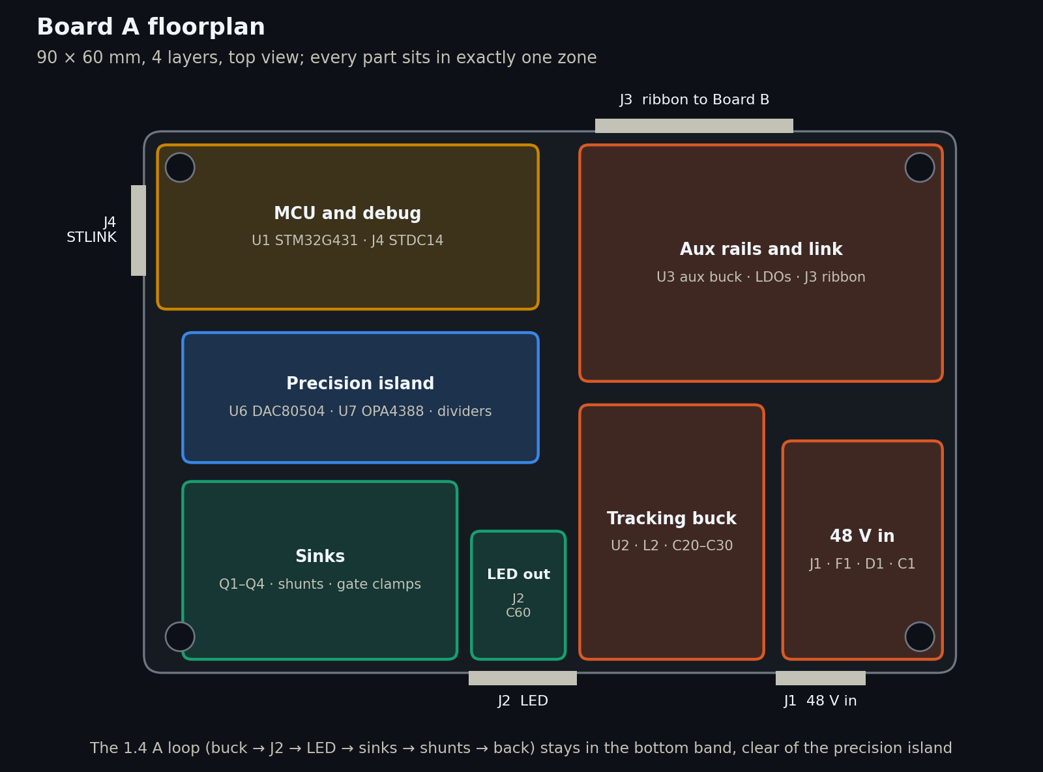
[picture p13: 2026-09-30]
docs/images/floorplan-dark.png

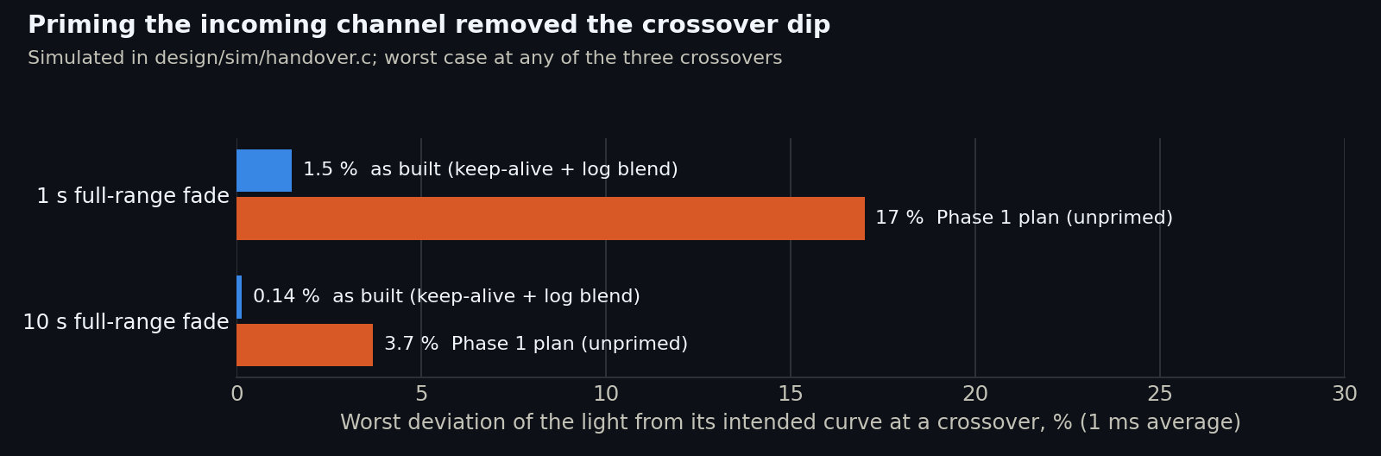
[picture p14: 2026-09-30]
docs/images/crossover-dark.png

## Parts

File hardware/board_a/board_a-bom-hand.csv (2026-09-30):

Refs | Qty/board | Qty for 7 boards (+spares) | Value | Description | Manufacturer | MPN | Digi-Key | Mouser | LCSC | Footprint | Placement | Status | Notes
C1 | 1 | 9 | 47uF 100V | 47 uF 100 V aluminium electrolytic, SMD 10 x 10.2 mm, 105 C | Honor Elec | RVT2A470M1010 |  |  | C87862 | CP_Elec_10x10 | stencil | verified LCSC C87862 (10 x 10.2 mm) | Any 47 uF 100 V SMD electrolytic in a 10 x 10 mm can fits. (The EEE-FK2A470AQ named earlier is a 12.5 mm can)
C2 C31 C80 C81 C82 C83 | 6 | 54 | 10nF | 10 nF 50 V X7R 0603 |  |  |  |  |  | C_0603_1608Metric | stencil | describe
C3 C11 C14 C16 C23 C41 C43 C50 C70 C71 C72 C73 C76 C77 C78 | 15 | 135 | 100nF | 100 nF 50 V X7R 0603 | YAGEO | CC0603KRX7R9BB104 |  |  | C14663 | C_0603_1608Metric | stencil | verified LCSC (this session)
C4 C20 C21 C24 C25 C26 C27 | 7 | 55 | 4.7uF 100V | 4.7 uF 100 V X7S 1210 | TDK | C3225X7S2A475K200AB |  |  | C2167998 | C_1210_3225Metric | stencil | verified LCSC (Phase 2) | LCSC and JLC out of stock on 29 Sep 2026; Newark, Avnet and Future stock it. Any 4.7 uF >= 100 V X7R/X7S 1210 fits
C5 C22 C28 | 3 | 31 | 100nF 100V | 100 nF 100 V X7R 0603 |  |  |  |  |  | C_0603_1608Metric | stencil | describe
C6 C7 C8 | 3 | 31 | 22uF | 22 uF 25 V X5R 1206 | Samsung | CL31A226KAHNNNE |  |  | C12891 | C_1206_3216Metric | stencil | verified LCSC C12891
C9 C15 C42 C48 C51 C75 | 6 | 54 | 1uF | 1 uF 25 V X5R or X7R 0603 |  |  |  |  |  | C_0603_1608Metric | stencil | describe
C10 C12 C74 | 3 | 31 | 4.7uF | 4.7 uF 25 V X5R/X7R 0805 | Samsung | CL21A475KAQNNNE |  |  | C1779 | C_0805_2012Metric | stencil | verified LCSC C1779
C13 C79 | 2 | 24 | 10uF | 10 uF 25 V X5R 0805 | Samsung | CL21A106KAYNNNE |  |  | C15850 | C_0805_2012Metric | stencil | verified LCSC C15850
C29 | 0 | 0 | 22pF C0G | 22 pF 50 V C0G/NP0 0603 | Samsung | CL10C220JB8NNNC |  |  | C1653 | C_0603_1608Metric | not fitted | verified LCSC C1653
C30 | 1 | 17 | 47nF | 47 nF 50 V X7R 0603 | Samsung | CL10B473KB8NNNC |  |  | C1622 | C_0603_1608Metric | stencil | verified LCSC C1622
C40 | 1 | 17 | 220nF | 220 nF 25 V X7R 0603 | Samsung | CL10B224KA8NNNC |  |  | C21120 | C_0603_1608Metric | stencil | verified LCSC C21120
C44 C45 C46 C47 | 4 | 38 | 10nF C0G | 10 nF 50 V C0G/NP0 0805 |  |  |  |  |  | C_0805_2012Metric | stencil | describe
C52 C53 C54 C55 | 4 | 38 | 2.2nF C0G | 2.2 nF 50 V C0G/NP0 0603 |  |  |  |  |  | C_0603_1608Metric | stencil | describe
C56 C57 C58 C59 C61 | 5 | 45 | 1nF C0G | 1 nF 50 V C0G/NP0 0603 |  |  |  |  |  | C_0603_1608Metric | stencil | describe | C0G, not X7R
C60 | 1 | 17 | 22nF 100V | 22 nF 100 V X7R 1206 (C_a across the LED) |  |  |  |  |  | C_1206_3216Metric | stencil | describe
D1 | 1 | 8 | SMBJ58A | 600 W TVS, 58 V standoff, unidirectional | Littelfuse | SMBJ58A |  |  | C157526 | D_SMB | stencil | verified LCSC (Phase 2)
D2 | 1 | 8 | SMBJ43A | 600 W TVS, 43 V standoff, unidirectional | Littelfuse | SMBJ43A |  |  | C315993 | D_SMB | stencil | verified LCSC (Phase 2)
D3 | 1 | 8 | BAV199 | Low-leakage series diode pair, SOT-23 | Nexperia | BAV199,215 |  |  | C40919 | SOT-23 | stencil | verified LCSC C40919 = BAV199,215
D4 | 1 | 17 | green | Green LED 0603, Vf ~3.1 V | Hubei KENTO | KT-0603G |  |  | C12624 | LED_0603_1608Metric | stencil | verified LCSC C12624
F1 | 1 | 8 | 3A T | 3 A slow-blow SMD fuse, 125 V AC/DC, 2410 (Nano2 452) | Littelfuse | 0452003.MRL |  |  |  | Fuse_Littelfuse-NANO2-451_453 | stencil | verified element14 listing
FB1 | 1 | 17 | 600R@100MHz | Ferrite bead 600 ohm at 100 MHz, 0805, 500 mA, 0.3 ohm (VDDA only) | Sunlord | GZ2012D601TF |  |  | C1017 | L_0805_2012Metric | stencil | verified JLC C1017 (Basic)
FB2 | 1 | 17 | 600R@100MHz 2A | Ferrite bead 600 ohm at 100 MHz, 0805, 2 A, 90 mohm | Sunlord | UPZ2012E601-2R0TF |  |  | C98308 | L_0805_2012Metric | stencil | verified JLC C98308
FID1 FID2 FID3 | 3 | 21 | FID | Fiducial |  |  |  |  |  | Fiducial_1mm_Mask2mm | stencil | n/a
H1 H2 H3 H4 | 4 | 28 | M3 | M3 mounting hole, unplated |  |  |  |  |  | MountingHole_3.2mm_M3 | stencil | n/a
J1 J2 | 2 | 15 | MSTBA 2,5/2-G-5,08 | 2-pos 5.08 mm pluggable header; mating plug MSTB 2,5/2-ST-5,08 (1757019) | Phoenix Contact | 1757242 |  |  |  | PhoenixContact_MSTBA_2,5_2-G-5,08_1x02_P5.08mm_Horizontal | hand | verified phoenixcontact.com (1757242 header, 1757019 plug)
J3 | 1 | 8 | 2x5 box header | 2x5 2.54 mm shrouded box header, vertical, through-hole (any maker; key slot toward the board edge) |  |  |  |  |  | IDC-Header_2x05_P2.54mm_Vertical | hand | describe
J4 | 1 | 8 | STDC14 | 2x7 1.27 mm SMD header with keying notch, no alignment pins (STDC14 for the STLINK-V3MINIE) | Samtec | FTSH-107-01-L-DV-K |  |  |  | PinHeader_2x07_P1.27mm_Vertical_SMD | stencil | verified samtec.com 29 Sep 2026 (in stock) | Not the -K-A version ST's manual names: its alignment pins need holes this footprint lacks
L2 | 1 | 8 | 33uH | 33 uH shielded power inductor, Irms 3.0 A, Isat 2.8 A typ | Bourns | SRR1260-330M |  |  | C840528 | L_Bourns_SRR1260 | stencil | verified LCSC (Phase 2) | Isat is below the LMR38020's 3.2 A typical current limit: fine at the 1.84 A peak in use; only a hard short of V_out to ground drives it into partial saturation
L3 | 1 | 8 | 15uH | 15 uH shielded power inductor, Irms 5.0 A, Isat 4.6 A typ | Bourns | SRR1260-150M |  |  | C2041333 | L_Bourns_SRR1260 | stencil | verified LCSC (Phase 2)
NT1 NT2 NT3 NT4 NT5 NT6 | 6 | 42 | NetTie | Kelvin net tie (copper only) |  |  |  |  |  | NetTie-2_SMD_Pad0.5mm | stencil | n/a
Q1 | 1 | 8 | NDT3055L | 60 V logic-level N-MOSFET, SOT-223 | onsemi | NDT3055L |  |  | C274612 | SOT-223-3_TabPin2 | stencil | verified LCSC (Phase 2)
Q3 Q4 | 2 | 15 | 2N7002 | 60 V N-MOSFET, SOT-23 (Nexperia 2N7002,215 specifically: gate leakage <=100 nA) | Nexperia | 2N7002,215 |  |  | C65189 | SOT-23 | stencil | verified LCSC C65189 = Nexperia 2N7002,215
Q2 Q5 Q6 Q7 Q8 | 5 | 36 | 2N7002BK | 60 V N-MOSFET, 2 ohm, SOT-23 | Nexperia | 2N7002BK,215 |  |  | C282405 | SOT-23 | stencil | verified LCSC (Phase 2)
R1 R6 R10 R16 R72 R73 R74 R75 R76 R77 R78 R79 R80 R81 R82 R83 R123 | 17 | 153 | 100k | Resistor 100k 1% 0603 thick film | UNI-ROYAL | 0603WAF1003T5E |  |  | C25803 | R_0603_1608Metric | stencil | verified LCSC C25803
R2 | 1 | 17 | 6.2k | Resistor 6.2k 1% 0603 thick film | UNI-ROYAL |  |  |  |  | R_0603_1608Metric | stencil | describe
R3 | 1 | 17 | 280k | Resistor 280k 1% 0603 thick film | UNI-ROYAL |  |  |  |  | R_0603_1608Metric | stencil | describe
R4 R44 R53 R120 R126 R127 R128 R129 | 8 | 72 | 10k | Resistor 10k 1% 0603 thick film | UNI-ROYAL | 0603WAF1002T5E |  |  | C25804 | R_0603_1608Metric | stencil | verified LCSC C25804
R5 | 1 | 17 | 52.3k | Resistor 52.3k 1% 0603 thick film | UNI-ROYAL |  |  |  |  | R_0603_1608Metric | stencil | describe
R7 | 1 | 17 | 22.1k | Resistor 22.1k 1% 0603 thick film | UNI-ROYAL |  |  |  |  | R_0603_1608Metric | stencil | describe
R11 | 1 | 17 | 64.9k | Resistor 64.9k 1% 0603 thick film | UNI-ROYAL |  |  |  |  | R_0603_1608Metric | stencil | describe
R12 | 1 | 17 | 200k | Resistor 200k 1% 0603 thick film | UNI-ROYAL |  |  |  |  | R_0603_1608Metric | stencil | describe
R13 | 1 | 17 | 7.32k | Resistor 7.32k 1% 0603 thick film | UNI-ROYAL |  |  |  |  | R_0603_1608Metric | stencil | describe
R14 R15 | 2 | 24 | 8.25k | Resistor 8.25k 1% 0603 thick film | UNI-ROYAL |  |  |  |  | R_0603_1608Metric | stencil | describe
R17 R110 | 2 | 24 | 1M | Resistor 1M 1% 0603 thick film | UNI-ROYAL | 0603WAF1004T5E |  |  | C22935 | R_0603_1608Metric | stencil | verified LCSC C22935
R18 | 1 | 17 | 82k | Resistor 82k 1% 0603 thick film | UNI-ROYAL |  |  |  |  | R_0603_1608Metric | stencil | describe
R40 R41 R42 R43 | 4 | 38 | 22R | Resistor 22R 1% 0603 thick film | UNI-ROYAL | 0603WAF220JT5E |  |  | C23345 | R_0603_1608Metric | stencil | verified LCSC C23345
R45 R47 R49 R51 | 4 | 38 | 12.0k 0.1% | 12.0 k 0.1% 25 ppm/C thin film 0805 | YAGEO | RT0805BRD0712KL |  |  |  | R_0805_2012Metric | stencil | verified YAGEO spec sheet; Newark, Arrow, TME stock it (29 Sep 2026) | No LCSC listing, so JLC can't place it
R46 R48 R50 R52 | 4 | 38 | 1.00k 0.1% | 1.00 k 0.1% 25 ppm/C thin film 0805 | YAGEO | RT0805BRD071KL |  |  | C110774 | R_0805_2012Metric | stencil | verified exists (LCSC C110774, RS)
R54 R60 R61 R62 R63 R125 | 6 | 54 | 1k | Resistor 1k 1% 0603 thick film | UNI-ROYAL | 0603WAF1001T5E |  |  | C21190 | R_0603_1608Metric | stencil | verified LCSC C21190
R64 R65 R66 R67 | 4 | 38 | 1.82M | Resistor 1.82M 1% 0603 thick film | UNI-ROYAL |  |  |  |  | R_0603_1608Metric | stencil | describe
R68 R69 R70 R71 | 4 | 38 | 220R | Resistor 220R 1% 0603 thick film | UNI-ROYAL | 0603WAF2200T5E |  |  | C22962 | R_0603_1608Metric | stencil | verified LCSC C22962
R90 R91 R92 R93 R94 R95 R96 R97 R98 R99 R100 | 11 | 99 | 10R 0.1% | 10 ohm 0.1% 25 ppm/C thin film 0805 | YAGEO | RT0805BRD0710RL |  |  |  | R_0805_2012Metric | stencil | verified YAGEO spec sheet; Newark, Arrow, TME stock it (29 Sep 2026) | No LCSC listing, so JLC can't place it
R101 | 1 | 17 | 100R 0.1% | 100 ohm 0.1% 25 ppm/C thin film 0805 | YAGEO | RT0805BRD07100RL |  |  |  | R_0805_2012Metric | stencil | verified YAGEO spec sheet; Newark, Arrow, TME stock it (29 Sep 2026) | No LCSC listing, so JLC can't place it
R102 | 1 | 9 | 0.1R 4T | 0.1 ohm 1% four-terminal metal strip, +-35 ppm/C, 1 W, 2512 | Vishay Dale | WSK2512R1000FEA |  |  |  | R_Shunt_Vishay_WSK2512_6332Metric_T1.19mm | stencil | verified Vishay WSK2512 datasheet; no distributor stock found 29 Sep 2026 (Octopart) | Check Vishay's lead time before ordering. In-stock fallback on the same pads: Vishay WSL2512R1000FEA (two-terminal, +-75 ppm/C; each end soldered across its current and sense pads), which widens range 1's budget to +-0.17 % RSS
R121 R122 R124 | 3 | 31 | 100R | Resistor 100R 1% 0603 thick film | UNI-ROYAL | 0603WAF1000T5E |  |  | C22775 | R_0603_1608Metric | stencil | verified LCSC C22775
RT1 RT2 RT3 RT4 | 4 | 38 | 10k NTC | NTC 10 k 1% B25/50 3380 K, 0603 | Murata | NCP18XH103F03RB |  |  | C13564 | R_0603_1608Metric | stencil | verified LCSC C13564
TP1 TP2 TP3 TP4 TP5 TP6 TP7 TP8 TP9 TP10 TP11 TP12 TP13 TP14 TP15 TP16 TP17 TP18 TP19 | 19 | 133 | TP | 1 mm test pad (copper only) |  |  |  |  |  | TestPoint_Pad_D1.0mm | stencil | n/a
U1 | 1 | 8 | STM32G431CBU6 | Cortex-M4F MCU, 128 KB flash, UFQFPN48 | STMicroelectronics | STM32G431CBU6 |  |  | C529356 | QFN-48-1EP_7x7mm_P0.5mm_EP5.6x5.6mm | stencil | verified LCSC (Phase 2) | LCSC had 61 and JLC none on 29 Sep 2026: order early (Avnet, Arrow and Newark stock it too)
U2 U3 | 2 | 15 | LMR38020FDDAR | 80 V 2 A sync buck, forced PWM, HSOIC-8 PowerPAD | Texas Instruments | LMR38020FDDAR |  |  | C5149193 | HSOP-8-1EP_3.9x4.9mm_P1.27mm_EP2.41x3.1mm_ThermalVias | stencil | verified LCSC (Phase 2) | Check the footprint's exposed pad against the datasheet's DDA0008B land pattern
U4 | 1 | 8 | TPS7A2050PDBVR | 5.0 V 300 mA low-noise LDO | Texas Instruments | TPS7A2050PDBVR |  |  | C2864504 | SOT-23-5 | stencil | verified LCSC (Phase 2); pinout from TI datasheet | Out of stock at LCSC on 29 Sep 2026; Digi-Key and Mouser stock it
U5 | 1 | 8 | LDL1117S33R | 3.3 V 1.2 A LDO | STMicroelectronics | LDL1117S33R |  |  | C435835 | SOT-223-3_TabPin2 | stencil | verified LCSC (Phase 2); pinout from ST datasheet
U6 | 1 | 8 | DAC80504RTET | Quad 16-bit DAC, 2.5 V internal reference, WQFN-16 (RTE0016D, 0.8 mm exposed pad) | Texas Instruments | DAC80504RTET | product page 9692594 |  |  | Texas_RTE0016D_WQFN-16-1EP_3x3mm_P0.5mm_EP0.8x0.8mm | stencil | verified TI and Digi-Key product pages | RTET is the 250-piece reel; RTER the 3000-piece reel. Same part. TI lists it in RTE0016D, whose exposed pad is 0.8 mm (dac80504.pdf p. 47; KiCad's Texas_RTE0016D footprint), not the 1.68 mm RTE0016C pad
U7 | 1 | 8 | OPA4388IPWR | Quad zero-drift RRIO op-amp, 10 MHz, TSSOP-14 | Texas Instruments | OPA4388IPWR | product page 10434812 |  |  | TSSOP-14_4.4x5mm_P0.65mm | stencil | verified TI and Digi-Key product pages
J1 J2 plugs (off-board) | 2 | 15 | MSTB 2,5/2-ST-5,08 | 2-pos 5.08 mm screw plug, mates J1 and J2 | Phoenix Contact | 1757019 |  |  |  | - | off-board | verified phoenixcontact.com

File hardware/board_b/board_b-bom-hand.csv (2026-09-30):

Refs | Qty/board | Qty for 7 boards (+spares) | Value | Description | Manufacturer | MPN | Digi-Key | Mouser | LCSC | Footprint | Placement | Status | Notes
C1 | 1 | 17 | 10uF | 10 uF 25 V X5R 0805 | Samsung | CL21A106KAYNNNE |  |  | C15850 | C_0805_2012Metric | stencil | verified LCSC C15850
C3 | 1 | 17 | 100nF | 100 nF 50 V X7R 0603 | YAGEO | CC0603KRX7R9BB104 |  |  | C14663 | C_0603_1608Metric | stencil | verified LCSC (this session)
C8 C9 C10 C11 | 4 | 38 | 10nF | 10 nF 50 V X7R 0603 |  |  |  |  |  | C_0603_1608Metric | stencil | describe
D1 | 1 | 8 | B5819W | 40 V 1 A Schottky, SOD-123 | JSCJ | B5819W SL |  |  | C8598 | D_SOD-123 | stencil | verified LCSC C8598 = JSCJ B5819W SL
D3 | 1 | 17 | red | Red LED 0603, Vf ~2 V | Hubei KENTO | KT-0603R |  |  | C2286 | LED_0603_1608Metric | stencil | verified LCSC C2286
D4 | 1 | 17 | green | Green LED 0603, Vf ~3.1 V | Hubei KENTO | KT-0603G |  |  | C12624 | LED_0603_1608Metric | stencil | verified LCSC C12624
D5 | 1 | 17 | blue | Blue LED 0603, Vf ~3.1 V | Hubei KENTO | KT-0603B |  |  | C2288 | LED_0603_1608Metric | stencil | verified LCSC C2288
FB1 | 1 | 17 | 600R@100MHz 2A | Ferrite bead 600 ohm at 100 MHz, 0805, 2 A, 90 mohm | Sunlord | UPZ2012E601-2R0TF |  |  | C98308 | L_0805_2012Metric | stencil | verified JLC C98308
FID1 FID2 FID3 | 3 | 21 | FID | Fiducial |  |  |  |  |  | Fiducial_1mm_Mask2mm | stencil | n/a
H1 H2 | 2 | 14 | M3 | M3 mounting hole, unplated |  |  |  |  |  | MountingHole_3.2mm_M3 | stencil | n/a
J1 | 1 | 8 | 2x5 box header | 2x5 2.54 mm shrouded box header, vertical, through-hole (any maker; key slot toward the board edge) |  |  |  |  |  | IDC-Header_2x05_P2.54mm_Vertical | hand | describe
J3 | 1 | 8 | JST PH 2 | 2-pin JST PH header for an external sync button | JST | B2B-PH-K-S(LF)(SN) |  |  |  | JST_PH_B2B-PH-K_1x02_P2.00mm_Vertical | hand | describe
J4 | 1 | 8 | 1x5 header | 1x5 2.54 mm pin header, optional |  |  |  |  |  | PinHeader_1x05_P2.54mm_Vertical | hand | describe
R7 R8 R9 R10 R11 R12 R13 R14 | 8 | 72 | 10k | Resistor 10k 1% 0603 thick film | UNI-ROYAL | 0603WAF1002T5E |  |  | C25804 | R_0603_1608Metric | stencil | verified LCSC C25804
R15 | 1 | 17 | 1k | Resistor 1k 1% 0603 thick film | UNI-ROYAL | 0603WAF1001T5E |  |  | C21190 | R_0603_1608Metric | stencil | verified LCSC C21190
R16 R17 | 2 | 24 | 220R | Resistor 220R 1% 0603 thick film | UNI-ROYAL | 0603WAF2200T5E |  |  | C22962 | R_0603_1608Metric | stencil | verified LCSC C22962
R18 R19 R20 R21 R23 | 5 | 45 | 100R | Resistor 100R 1% 0603 thick film | UNI-ROYAL | 0603WAF1000T5E |  |  | C22775 | R_0603_1608Metric | stencil | verified LCSC C22775
R22 | 1 | 17 | 100k | Resistor 100k 1% 0603 thick film | UNI-ROYAL | 0603WAF1003T5E |  |  | C25803 | R_0603_1608Metric | stencil | verified LCSC C25803
SW3 | 1 | 8 | PEC11R-4220F-S0024 | 24-detent encoder with push switch, 20 mm flatted shaft | Bourns | PEC11R-4220F-S0024 |  |  |  | RotaryEncoder_Alps_EC11E-Switch_Vertical_H20mm_CircularMountingHoles | hand | verified Bourns ordering code; Newark, Digi-Key and Mouser stock it | LCSC's C462143 is the knurled -4220K, so no LCSC number. The EC11E footprint's 1.5 mm lug slots are narrower than Bourns' 1.8 x 2.1 mm lug holes, hence the round 2.6 mm holes: test-fit a real encoder on a 1:1 print
SW4 | 1 | 8 | SYNC | 6 x 6 mm SMD tactile switch, 4 gull-wing pads (Omron B3S-1000 or C&K PTS645 SMD land); pick SW4's height so it reaches the panel |  |  |  |  |  | SW_SPST_B3S-1000 | stencil | describe
TP1 TP2 TP3 | 3 | 21 | TP | 1 mm test pad (copper only) |  |  |  |  |  | TestPoint_Pad_D1.0mm | stencil | n/a
U1 | 1 | 8 | ESP32-S3-Zero-M | Waveshare ESP32-S3-Zero with pre-soldered pin headers: ESP32-S3FH4R2 (4 MB flash, 2 MB PSRAM), USB-C, 3.3 V LDO (ME6217C33, 800 mA), BOOT and RESET buttons, ceramic antenna, 23.5 x 18 mm | Waveshare | ESP32-S3-Zero-M |  |  |  | ESP32-S3-Zero_Socket | hand: plugs into the two 1x9 sockets on the bottom | verified waveshare.com product page (SKU 25081 without header; -M = header fitted) | Pin order from Waveshare's top-view photo and the community KiCad footprint (github.com/jtomka/kicad-esp32-s3-zero). Its 5V pin is its USB VBUS: never plug USB into it while the ribbon from Board A is connected (flash it off the board)
U1 sockets | 2 | 16 | 1x9 socket | 1x9 2.54 mm female header, vertical, through-hole, about 8.5 mm tall, gold-plated contacts (any maker): the ESP32-S3-Zero's socket, soldered into U1's pads from the top |  |  |  |  |  | - | hand, bottom side | describe | Solder both with the module plugged in, so the rows end up exactly parallel

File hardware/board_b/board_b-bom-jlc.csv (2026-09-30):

Comment | Designator | Footprint | LCSC Part # | JLC class | Loading fee note
10uF | C1 | C_0805_2012Metric | C15850 | Basic | none (Economic PCBA)
100nF | C3 | C_0603_1608Metric | C14663 | Basic | none (Economic PCBA)
10nF | C8,C9,C10,C11 | C_0603_1608Metric |  | Basic (expected; pick the part in JLC's BOM tool) | none (Economic PCBA)
B5819W | D1 | D_SOD-123 | C8598 | Basic | none (Economic PCBA)
red | D3 | LED_0603_1608Metric | C2286 | Basic | none (Economic PCBA)
green | D4 | LED_0603_1608Metric | C12624 | Extended | ~$3 per unique part per order (Economic PCBA)
blue | D5 | LED_0603_1608Metric | C2288 | Extended | ~$3 per unique part per order (Economic PCBA)
600R@100MHz 2A | FB1 | L_0805_2012Metric | C98308 | Extended | ~$3 per unique part per order (Economic PCBA)
2x5 box header | J1 | IDC-Header_2x05_P2.54mm_Vertical |  | - | not placed by JLC
JST PH 2 | J3 | JST_PH_B2B-PH-K_1x02_P2.00mm_Vertical |  | - | not placed by JLC
1x5 header | J4 | PinHeader_1x05_P2.54mm_Vertical |  | - | not placed by JLC
10k | R7,R8,R9,R10,R11,R12,R13,R14 | R_0603_1608Metric | C25804 | Basic | none (Economic PCBA)
1k | R15 | R_0603_1608Metric | C21190 | Basic | none (Economic PCBA)
220R | R16,R17 | R_0603_1608Metric | C22962 | Basic | none (Economic PCBA)
100R | R18,R19,R20,R21,R23 | R_0603_1608Metric | C22775 | Basic | none (Economic PCBA)
100k | R22 | R_0603_1608Metric | C25803 | Basic | none (Economic PCBA)
PEC11R-4220F-S0024 | SW3 | RotaryEncoder_Alps_EC11E-Switch_Vertical_H20mm_CircularMountingHoles |  | - | not placed by JLC
SYNC | SW4 | SW_SPST_B3S-1000 |  | Basic (expected; pick the part in JLC's BOM tool) | none (Economic PCBA)
ESP32-S3-Zero-M | U1 | ESP32-S3-Zero_Socket |  | - | not placed by JLC

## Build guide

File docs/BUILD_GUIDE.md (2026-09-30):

# Build guide

Everything you need to go from this repository to a working, calibrated fixture: what each file
is for, which tools to install, how to regenerate or change the design, how to order boards and
parts, how to assemble, flash, bring up, calibrate and verify it, and how to use it afterwards.

> [!IMPORTANT]
> This design has been fully designed, laid out and simulated, and its firmware tested on a PC,
> but **no board has been built yet**. The first build is also the first test. Go through
> [section 5](#5-review-before-ordering) before you spend money, and treat the bring-up steps as
> real tests: stop at the first one that fails.

## Contents

0. [Before you start](#0-before-you-start)
1. [How the files fit together](#1-how-the-files-fit-together)
2. [Install the tools](#2-install-the-tools)
3. [Check or change the design (optional)](#3-check-or-change-the-design-optional)
4. [Lay out the boards (optional)](#4-lay-out-the-boards-optional)
5. [Review before ordering](#5-review-before-ordering)
6. [Order the PCBs and stencils](#6-order-the-pcbs-and-stencils)
7. [Order the parts](#7-order-the-parts)
8. [Assemble Board A](#8-assemble-board-a)
9. [Assemble Board B and the ribbon](#9-assemble-board-b-and-the-ribbon)
10. [Build the firmware](#10-build-the-firmware)
11. [Bring-up](#11-bring-up)
12. [Calibrate](#12-calibrate)
13. [Verify flicker](#13-verify-flicker)
14. [Install it in the fixture](#14-install-it-in-the-fixture)
15. [Use it](#15-use-it)
16. [Troubleshooting](#16-troubleshooting)

Appendices: [A. Connectors and pinouts](#appendix-a-connectors-and-pinouts) ·
[B. Board A console](#appendix-b-board-a-console) ·
[C. Pre-order checklist](#appendix-c-pre-order-checklist)

---

## 0. Before you start

### What one fixture needs

| Item | Notes |
| --- | --- |
| Board A (driver) | 90 × 60 mm, 4 layers, 206 parts. Takes 48 V, drives the LED |
| Board B (controller) | 60 × 45 mm, 2 layers, 42 parts, one of them a plug-in Waveshare ESP32-S3-Zero-M |
| A 10-way ribbon cable | Up to about 0.5 m (good to 1 m), IDC sockets on both ends |
| Mean Well LRS-100-48 | The isolated 48 V supply, mounted separately with a fused, switched IEC inlet |
| Xicato XTM19803050CCA | On its own heatsink (the design assumes the LED is always adequately cooled) |
| An enclosure | Wood or plastic; PETG or ASA (not PLA) anywhere near Board A or the LED heatsink |

The design is set up for **six sets** (four fixtures and two spares), with parts bought for seven.

### Skills

- **Fine-pitch SMD with a stencil and reflow:** a 0.5 mm-pitch QFN-48, a 3 × 3 mm WQFN-16 with an
  exposed pad, a TSSOP-14, two HSOP-8 with exposed pads, lots of 0603. A hot plate or reflow oven,
  a stencil, and a microscope or loupe for inspection.
- **Through-hole soldering** for the connectors, encoder and sockets.
- **Bench work:** a current-limited supply, a DMM and a scope; the procedures say exactly what
  to measure.
- **Command line:** running Python scripts, CMake and ESPHome.

### Time

| Stage | First fixture | Each after that |
| --- | --- | --- |
| Assembly (both boards) | an evening | a few hours |
| Bring-up | about 2 hours | about 30 minutes |
| Current calibration | about 10 minutes | about 10 minutes |
| Light matching (optional) | about 10 minutes | about 10 minutes |

> [!WARNING]
> **Voltages.** Board A runs from 48 V and can put 38 V on the LED connector. Never plug or unplug
> the LED while the output is on. **Neither board carries mains:** the LRS-100-48 is a certified,
> isolated supply mounted on its own. Its mains side (inlet, fuse, switch, earth) must be wired
> and enclosed properly; if that isn't something you're qualified to do, have someone who is do
> it. The XTM is damaged by reverse polarity: check J2's wiring before first light.

---

## 1. How the files fit together

The design lives in code. Every part and connection is declared once in Python; everything else
is generated from that, checked, and then laid out by scripts.

```mermaid
flowchart TD
  cat["design/catalog.py<br/>part data"] --> boards["design/board_a.py · board_b.py<br/>parts and pin-to-net connections"]
  boards --> build["design/build.py<br/>connectivity check (ERC)"]
  build --> hw["hardware/board_x/<br/>sheet tables · netlist · BOMs · CPL template"]
  boards --> lay["layout/make_board.py<br/>+ board_x_layout.py"]
  rules["hardware/board_x.kicad_dru<br/>hardware/LAYOUT.md"] --> lay
  lay --> out["layout/out/board_x/<br/>KiCad project · Gerbers · CPL · DRC report"]
  out --> jlc(["JLCPCB: boards and stencils"])
  hw --> parts(["Distributors: parts"])
  calc["design/calc.py<br/>+ sim/handover.c"] -. "values" .-> boards
  fwa["firmware/board-a"] --> A(["Board A"])
  fwb["firmware/board-b"] --> B(["Board B"])
```

### Which files do I need?

| If you want to... | Use |
| --- | --- |
| Order the boards as they are | `layout/out/board_a/board_a-gerbers.zip`, `layout/out/board_b/board_b-gerbers.zip` |
| Order the parts | `hardware/board_a/board_a-bom-hand.csv`, `hardware/board_b/board_b-bom-hand.csv` |
| Have JLCPCB assemble instead | `hardware/board_x/board_x-bom-jlc.csv` + `layout/out/board_x/board_x-cpl-jlc.csv` |
| Look at or edit the boards in KiCad | `layout/out/board_x/board_x.kicad_pro` |
| See every part and connection, sheet by sheet | `hardware/board_x/board_x-sheets.md` |
| Draw your own schematic and check it | `hardware/board_x/board_x.net` + `design/compare_netlists.py` |
| Understand a value or re-check a limit | `design/calc.py` (its output: `design/calc_output.txt`) |
| Change a part or a connection | `design/catalog.py`, `design/board_x.py`, then `design/build.py` |
| Move parts or change routing rules | `layout/board_x_layout.py`, then `layout/run_layout.bat` |
| Review a layout against the rules | `hardware/LAYOUT.md` |
| Flash Board A | `firmware/board-a/` |
| Flash Board B | `firmware/board-b/` |
| Calibrate and test for flicker | `firmware/board-a/tools/calibrate.py`, `tools/flicker.py` |

### The generated hardware files

| File (per board, in `hardware/board_x/`) | What it is |
| --- | --- |
| `board_x-sheets.md` | Every part with its value, MPN and footprint, every pin with its datasheet name and net, sheet by sheet; then the full net list. Enough to capture a schematic by hand |
| `board_x.net` | KiCad netlist with footprints and part numbers attached |
| `board_x-bom-hand.csv` | Hand-assembly BOM: one line per part type, quantity per board and for 7 sets plus spares, manufacturer, MPN, Digi-Key/Mouser/LCSC numbers, footprint, placement (stencil, hand, off-board) and verification status |
| `board_x-bom-jlc.csv` | JLCPCB format (Comment, Designator, Footprint, LCSC Part #), with each line's Basic/Extended class |
| `board_x-cpl-template.csv` | The designators JLC's CPL needs; the layout scripts fill in the real one |

In the BOMs, a **Status** of `verified ...` means that part number was checked against a
distributor or manufacturer page; `describe` means any maker's part to the description will do
(passives, headers, tactile switches), so you pick one yourself.

---

## 2. Install the tools

You only need the tools for the steps you're doing.

| Tool | Version | Needed for | Where |
| --- | --- | --- | --- |
| Python | 3.10 or later | Design scripts, calibration tools | python.org, or your OS |
| numpy | any recent | `design/calc.py`, `tools/flicker.py` | `pip install numpy` |
| gcc and make | any recent | The crossover simulation, both host test suites | Linux/macOS native; on Windows, WSL |
| KiCad | 9.0.x | Viewing the boards; the layout scripts | [kicad.org](https://www.kicad.org/download/) |
| Java runtime | 21 or later | Freerouting (layout scripts only) | `winget install EclipseAdoptium.Temurin.21.JRE`, or [adoptium.net](https://adoptium.net) |
| Freerouting | 1.9.0 exactly | Routing | Downloaded automatically on the first layout run |
| arm-none-eabi-gcc | 12 or later | Building Board A's firmware | [Arm GNU Toolchain](https://developer.arm.com/downloads/-/arm-gnu-toolchain-downloads) or xPack; Ubuntu 24.04: `apt install gcc-arm-none-eabi` |
| CMake and Ninja | CMake 3.20+ | Building Board A's firmware | cmake.org, ninja-build.org, or your package manager |
| A flasher | any | Flashing Board A | STM32CubeProgrammer, OpenOCD or pyOCD |
| ESPHome | 2026.9.0 or later (Python 3.12+) | Board B's firmware | `pip install esphome` or `uv tool install esphome` |
| pyserial (+ pyvisa) | any | Calibration over the console (pyvisa to read a SCPI meter) | `pip install pyserial pyvisa` |

On **Ubuntu 24.04** most of it is one line:

```sh
sudo apt install python3-numpy python3-serial gcc make cmake ninja-build \
    gcc-arm-none-eabi libnewlib-arm-none-eabi openocd
pip install esphome        # in a virtual environment with Python 3.12+
```

On **Windows**, install KiCad 9, the Temurin 21 JRE, Python, the Arm GNU Toolchain, CMake and
Ninja, and STM32CubeProgrammer. The layout scripts run natively (`run_layout.bat`); the host tests
and `calc.py`'s simulation want gcc, which is easiest under WSL.

Hardware for flashing: an **STLINK-V3MINIE** (its cable fits Board A's J4 and also carries the
console) and a **USB-C cable** for the ESP32-S3-Zero.

---

## 3. Check or change the design (optional)

Skip this if you're building the boards as they are.

### Regenerate and check

```sh
python3 design/build.py      # rewrites hardware/board_a and hardware/board_b, runs the ERC
python3 design/calc.py       # prints every design number and asserts the limits
```

`build.py` prints each board's part and net count and stops with an error if the connectivity
check fails (a net with only one connection, a declared power net that nothing uses, a pin left
unconnected).
The current design gives:

```text
Board A (driver): 206 parts, 96 nets, 0 ERC errors, 0 warnings
Board B (controller): 42 parts, 32 nets, 0 ERC errors, 0 warnings
```

`calc.py` reproduces `design/calc_output.txt`: the setpoint chain, the buck's feedback network
and timing limits, loop stability for all four sinks, the error budget, thermal estimates, and
(section 5) the crossover simulation, which it compiles from `design/sim/handover.c` with gcc.
It asserts the limits that matter (phase margin, the buck's minimum on- and off-times, the
inductance, the V_out ceiling), so a change that breaks one fails loudly.

### Change a part or a connection

1. **Part data** is in `design/catalog.py`: value, footprint, manufacturer, MPN, LCSC number,
   JLC class, a verification status and, for ICs, the pin names. Change a value there (or add a
   new entry).
2. **Connections** are in `design/board_a.py` and `design/board_b.py`, one `b.add(ref, part,
   {pin: net})` per part, grouped by sheet. Nets are plain names; two pins on the same name are
   connected.
3. Run `python3 design/build.py` and fix anything the ERC reports, then `python3 design/calc.py`
   if you touched anything analog.
4. Re-run the layout ([section 4](#4-lay-out-the-boards-optional)); the netlist the layout uses
   comes straight from these files.

> [!CAUTION]
> Only put a part number in the catalog if you've checked it exists and is stocked. If you're not
> sure, describe the part (value, rating, dielectric, size) and mark it `describe`; a wrong part
> number costs a board revision.

### Capture the schematic in KiCad yourself

The design has no KiCad schematic file: the schematic *is* the code and the sheet tables. If you
want one in KiCad:

- **Straight to layout:** in the PCB editor, File → Import → Netlist, pick
  `hardware/board_x/board_x.net`. Footprints and the ratsnest arrive together (the board then has
  no schematic behind it).
- **Draw it, then prove it:** enter each sheet from `board_x-sheets.md` using the net names as
  labels, export a netlist, and compare:

  ```sh
  python3 design/compare_netlists.py hardware/board_a/board_a.net my_board_a.net
  ```

  It lists every pin whose connections differ, ignoring net names.

---

## 4. Lay out the boards (optional)

The finished, checked layouts are already in `layout/out/`. **Run the scripts only if you
changed the design or the layout rules:** each run starts from the netlist and replaces
`layout/out/board_x/`, and Freerouting's result differs from run to run.

### On Windows

1. Install KiCad 9 (default folder) and a Java 21 runtime ([section 2](#2-install-the-tools)).
2. Double-click `layout\run_layout.bat`, or from a Command Prompt in `layout\`:

   ```bat
   run_layout.bat                          :: both boards, start to finish
   run_layout.bat board_b                  :: one board
   run_layout.bat board_a --stage place    :: placement only, with a preview (a minute)
   run_layout.bat board_a --attempts 10    :: more routing attempts (6 by default)
   ```

The first run downloads Freerouting 1.9.0 into `layout\tools\` (or put
`freerouting-1.9.0.jar` there yourself, or set `FREEROUTING_JAR`). Board B takes a minute or
two, Board A 5 to 30 minutes; Freerouting opens its own window while it works. Leave it alone.

### On Linux or macOS

The scripts need KiCad 9's Python (`import pcbnew` must work) and `kicad-cli` on the PATH. With
KiCad from your distribution's packages, the system Python usually has `pcbnew`:

```sh
cd layout
python3 -c "import pcbnew; print(pcbnew.Version())"   # should print 9.0.x
python3 make_board.py board_b
python3 make_board.py board_a --attempts 10
```

On macOS, run them with the Python inside the KiCad application bundle.

### What a run does and writes

Each board goes through: place every part → draw the critical copper (switch nodes, cathode
copper, shunt bus bars, ground plane, a via beside every ground pad) → route the rest with
Freerouting, clean up and retry → pour and stitch ground → DRC with the custom rules → export.
Outputs in `layout/out/board_x/`:

| File | What it is |
| --- | --- |
| `board_x.kicad_pro`, `.kicad_pcb`, `.kicad_dru` | The KiCad project; open the `.kicad_pro` |
| `board_x-gerbers.zip` | Gerbers and drill files, ready to upload |
| `board_x-cpl-jlc.csv` | Placement file in JLCPCB's format (`board_x-pos.csv` is KiCad's own) |
| `board_x_drc.json` | The final DRC report |
| `board_x-1-FCu_FSilkS.png` etc. | Previews of each copper layer |
| `board_x_run.log` | What happened; the last line says whether it's complete |

The run is complete when the log ends with `done in ... s: 0 DRC errors, 0 unconnected`.

### If connections are left open

1. Run that board again, perhaps with `--attempts 10`; or
2. open the `.kicad_pro` in KiCad, route the few ratsnest lines left (the log lists them), press
   **B** to refill zones, save, close KiCad, and run `run_layout.bat board_a --stage export`. That
   re-stitches the pours, re-runs the DRC and rewrites the Gerbers and CPL without touching what
   you drew.

The export stage is also how to regenerate outputs after any hand edit. Details:
[`layout/README.md`](../layout/README.md).

---

## 5. Review before ordering

A DRC-clean board can still be wrong in ways no rule sees. Do these before ordering, whether you
use the committed layouts or your own. The full list is [Appendix C](#appendix-c-pre-order-checklist).

**Open each board in KiCad 9** (`layout/out/board_x/board_x.kicad_pro`):

- **Inspect → Design Rules Checker**, "Refill all zones" ticked: no errors, nothing unconnected.
  Silkscreen warnings are expected (36 on Board A, 2 on Board B); look at any that sit on a pad.
- **View → 3D Viewer**: every part on the right side; J1, J2 and J3's openings face off the board.
- **Board A power stage:** U2's SW pin, C23 and L2 pad 1 joined by short, wide copper on the top
  layer with no vias (the same for U3, C3 and L3); C22 right at U2's VIN pin with a ground via
  beside it.
- **Board A cathode:** J2 pin 1, C60, R110 and the four drains on the tab copper; the heat
  spreader under it on the bottom layer, joined by 39 vias; R102 at least 2 mm from it; the 1 mm
  slot between J2's pads.
- **Board A sinks:** each SNSHIx/SNSLOx track starts at its shunt's Kelvin pads; the divider
  bottoms (R46, R48, R50, R52) and C44–C47 return to SNSLOx, not to ground.
- **Board B:** U1's two socket rows on the back, pin 1 (square pad, marked **5V**) at the USB-C
  end nearest the middle of the board; no copper under the antenna end at the right-hand edge.
- **Holes:** Board A's four M3 holes and Board B's two are unplated, nothing inside their rings.

**Print both boards 1:1** (File → Plot → PDF, scale 1:1) and lay the parts that can surprise on
their footprints: the SRR1260 inductors, the 10 × 10 mm electrolytic, the Phoenix connectors, the
box headers, the encoder (its lugs go into round 2.6 mm holes), and **the ESP32-S3-Zero on Board
B's back** (plot B.Cu, B.SilkS and Edge.Cuts **mirrored**, then put the module's pins in the pads).
The ESP32-S3-Zero footprint is this project's own (`layout/lib/XTM.pretty`), drawn from
Waveshare's figures.

**Check footprints against datasheets** for the parts that bite: U6 DAC80504 (TI RTE0016D, 0.8 mm
exposed pad, pin 1), U7 OPA4388 (TSSOP-14), U2/U3 LMR38020 (HSOP-8 exposed pad against TI's DDA
land pattern), U1 STM32G431CBU6, R102 WSK2512 (pads 1 and 4 carry current, 2 and 3 sense), Q1
NDT3055L (G-D-S, tab = drain), D3 BAV199, J4 STDC14 against Samtec's FTSH drawing.

**Check the mechanics** against your enclosure: Board A's holes and 10 mm standoffs with air on
both faces and wire access to J1/J2; Board B's encoder shaft length through your panel, **12–14 mm
of room behind Board B** for the module on its sockets, and the antenna end clear of metal.

**Compile Board B's firmware once** (`esphome compile xtm-1.yaml`, [section 10](#10-build-the-firmware)).
It's the one build that hasn't been run yet.

---

## 6. Order the PCBs and stencils

The boards are laid out for [JLCPCB](https://jlcpcb.com)'s standard capabilities. Upload each
`board_x-gerbers.zip` from `layout/out/` and choose:

| Option | Board A | Board B |
| --- | --- | --- |
| Layers | 4 | 2 |
| Dimensions | 90 × 60 mm (auto-detected) | 60 × 45 mm |
| Thickness | 1.6 mm | 1.6 mm |
| Stackup | JLC's standard 4-layer stackup (7628 prepreg); no impedance control needed | — |
| Surface finish | ENIG (flat pads for the stencil and the QFNs) | ENIG |
| Outer copper | 1 oz | 1 oz |
| Inner copper | 0.5 oz | — |
| Via covering | Tented | Tented |
| Smallest via | 0.2 mm hole / 0.5 mm pad (JLC's 4-layer minimum is 0.2 / 0.45 mm, no extra cost) | 0.3 / 0.6 mm |
| Quantity | 10 (JLC's minimum is 5) | 10 |
| Stencil | 0.12 mm, top side only | 0.12 mm, top side only |

- **Order number:** the layouts don't reserve a spot for JLC's order number. Either choose the
  option to remove it, or let JLC place it: it's only silkscreen.
- **Board A's slot:** the 1 mm × 6 mm non-plated slot between J2's pads is in the outline and
  drill files. Check it shows in JLC's Gerber viewer.
- **Exposed pads:** the KiCad footprints already split the paste on U1, U2, U3 and U6's exposed
  pads into windowpanes, so the stencil needs no changes.

### If JLCPCB assembles instead

Hand assembly is the recommendation: the precision parts should come from franchised
distributors anyway, and one stencil pass and one cleaning pass give the cleanest analog region.
If you'd rather pay for placement:

- Upload `hardware/board_x/board_x-bom-jlc.csv` as the BOM and `layout/out/board_x/board_x-cpl-jlc.csv`
  as the placement file. **Check every part's rotation in JLC's preview**, especially polarised
  parts and ICs: their library's zero angle doesn't always match KiCad's.
- Board A has 28 Extended part types (each carries a feeder fee). JLC can't place the DAC, the
  op-amp, the 0.1 Ω shunt, the fuse, the three connectors or the sixteen 0.1% resistors LCSC
  doesn't list (12.0k, 10 Ω, 100 Ω): those get soldered by hand afterwards.
- Board B has 3 Extended types; J1, J3, J4, the encoder and the sockets are hand-soldered, and the
  ESP32-S3-Zero plugs in.
- Descriptive BOM lines need a part picked in JLC's BOM tool, and some stock was short on
  29 Sep 2026 (the TDK 4.7 µF 100 V capacitors, the TPS7A2050, the STM32): pick an in-stock
  equivalent 4.7 µF 100 V 1210, and pre-order or consign the two ICs.

---

## 7. Order the parts

Order from the **hand-assembly BOMs**, `hardware/board_a/board_a-bom-hand.csv` (65 lines) and
`hardware/board_b/board_b-bom-hand.csv` (23 lines). The "Qty for 7 boards (+spares)" column is
already the buy quantity. Check stock on the day.

### The ones that are easy to get wrong

| Part | Get exactly | Not |
| --- | --- | --- |
| U2, U3 buck | **LMR38020FDDAR**, the forced-PWM variant (light-load pulse skipping would put ripple in the audio band) | LMR38020**S**DDAR |
| SW3 encoder | **PEC11R-4220F-S0024** (flatted shaft) from Digi-Key, Mouser or Newark | LCSC's PEC11R-4220K (knurled) |
| J4 debug header | **Samtec FTSH-107-01-L-DV-K** | FTSH-107-01-L-DV-K-A (its alignment pins need holes the footprint doesn't have) |
| J1, J2 on Board A | Phoenix **1757242** headers, plus **1757019** plugs (on the BOM as an off-board line) | — |
| R102 0.1 Ω shunt | Vishay **WSK2512R1000FEA** (four-terminal) | If its lead time is long: **WSL2512R1000FEA** fits the same pads (two-terminal; range 1 widens to ±0.17%) |
| Q2 / Q3, Q4 sink FETs | Nexperia **2N7002BK,215** for Q2; Nexperia **2N7002,215** for Q3, Q4 | Other makers' 2N7002: Nexperia's has the gate-leakage limit the bottom range needs |
| U1 on Board B | Waveshare **ESP32-S3-Zero-M** (headers fitted; 4 MB flash, 2 MB PSRAM) | The version without headers, unless you'll fit 2.54 mm male headers yourself |

Buy the **precision parts from franchised distributors** (TI, Digi-Key, Mouser, Newark, Arrow,
Avnet): DAC80504RTET (or RTER), OPA4388IPWR, the RT0805 0.1% 25 ppm/°C thin-film resistors,
NDT3055L and the Vishay shunt. The 10 ppm/°C RT0805BRB grade in the same values roughly halves
the drift terms in the error budget if you can find it.

**Stock notes from 29 Sep 2026:** the TDK C3225X7S2A475K200AB (4.7 µF 100 V 1210) and the
TPS7A2050PDBVR were out of stock at LCSC (any 4.7 µF ≥100 V X7R/X7S 1210 fits); LCSC had only a
few dozen STM32G431CBU6 (order early). The WSK2512 had no distributor stock.

**Descriptive lines** (18 on Board A, 6 on Board B) are passives, headers and switches where any
maker will do. For each, check value, voltage rating, dielectric (C0G where it says C0G, 100 V
where it says 100 V) and size.

**Keep the 0.1% resistors identified.** They look exactly like the 1% ones; keep them on their
tapes or in labelled bags until they're on the board.

### Not on either BOM

| Item | Per fixture | Notes |
| --- | --- | --- |
| Xicato XTM19803050CCA + heatsink | 1 | Leads are fixed, 20 AWG, 400 mm |
| Mean Well LRS-100-48 | 1 | From an authorised Mean Well distributor (marketplace units are often counterfeit) |
| Fused, switched IEC inlet + mains cord | 1 | For the supply |
| 10-way ribbon, 28 AWG, 1.27 mm pitch, with two 2 × 5 IDC sockets | 1 | Up to about 0.5 m |
| M3 standoffs (10 mm) and screws | 4 for Board A, 2 for Board B | Board B's third fixing is the encoder's panel nut |
| Encoder knob | 1 | For a 6 mm flatted (D) shaft |
| Hook-up wire for 48 V | — | 18 or 20 AWG to J1 |
| Panel-mount sync button (optional) | 1 | Normally open, to Board B's J3 with a JST PH 2-pin plug |

Once for the whole build: an **STLINK-V3MINIE** and a **USB-C cable**.

### Bench equipment

| For | You need |
| --- | --- |
| Bring-up | A bench supply to 60 V with a current limit; a DMM; an oscilloscope; a dummy load of ten 1 W white LEDs in series on a heatsink (about 30 V, good for 350 mA) |
| Calibration | A 6½-digit DMM with a 100 µA range (and 3 A); a lux meter if you'll light-match fixtures |
| Flicker check | A BPW34 (or similar PIN) photodiode, a FET-input op-amp (e.g. OPA140), 10 kΩ, 1 MΩ, 100 pF and 2.2 pF parts, two 9 V batteries; a scope with CSV export; a phone with 240 fps slow motion |

---

## 8. Assemble Board A

All SMD parts are on the top side. C29 (22 pF) is **not fitted**: its footprint is a spare.

1. **Inspect the bare board:** the J2 slot is cut, the four M3 holes are unplated.
2. **Paste** through the 0.12 mm stencil.
3. **Place** every SMD part, including J4 (the 1.27 mm debug header). Mind these:
   - **U1** STM32G431 (QFN-48), **U6** DAC80504 (3 × 3 mm WQFN-16) and **U7** OPA4388 (TSSOP-14):
     pin 1 to the silkscreen dot.
   - **U2, U3** LMR38020 (HSOP-8): exposed pad down, pin 1 to the mark.
   - **Q1** NDT3055L (SOT-223): the tab is the drain, on the big copper area.
   - **R102** WSK2512: four terminals, pads 1 and 4 carry current, 2 and 3 sense. It only fits one
     way round electrically, so check it against the footprint.
   - **D1** SMBJ58A and **D2** SMBJ43A: cathode band to the marked end. **D3** BAV199 (SOT-23).
   - **C1** electrolytic: polarity to the silkscreen.
   - **R90–R99:** the ten 10 Ω 0.1% resistors of the channel-2 ladder.
   - **0.1% resistors** in their right places: 12.0k (R45, R47, R49, R51), 1.00k (R46, R48, R50,
     R52), 10 Ω (R90–R100) and 100 Ω (R101). Check against `board_a-sheets.md` as you go.
4. **Reflow.**
5. **Inspect** under magnification: bridges on U1, U6 and U7, the exposed pads (a little solder
   visible at the edges), tombstoned 0603 parts.
6. **Hand-solder** J1 and J2 (Phoenix headers, wire openings off the board) and J3 (the 2 × 5 box
   header, key slot to the silkscreen outline).
7. **Clean. This is not optional.** Scrub the whole board with isopropyl alcohol and a soft
   brush, especially around J2, the CATHODE copper, the sinks and the precision island; rinse
   with fresh IPA; dry it warm (50 °C for 30 minutes). At 5 µA, 50 nA of leakage through flux
   residue is a 1% error: flux between a 40 V node and the cathode is the one thing that can
   visibly shift the bottom of the range.
8. **No conformal coating** (no haze or fog in this venue); keep the board clean instead.

Don't power it yet: [bring-up](#11-bring-up) starts with resistance checks.

---

## 9. Assemble Board B and the ribbon

### Board B

1. **Paste and place** the SMD parts on top: C1, C3, C8–C11, D1 (B5819W, cathode band to the
   mark), D3–D5 (red, green, blue LEDs: check polarity), FB1, R7–R23, SW4 (the tactile switch;
   pick a height that reaches your panel). **Reflow** and inspect.
2. **Hand-solder on top:** J1 (2 × 5 box header, key slot to the silkscreen), SW3 (the encoder,
   including its two mounting lugs), J3 (JST PH, for an external sync button) and J4 (the 1 × 5
   spare header, optional).
3. **Fit the ESP32-S3-Zero's sockets on the back.** Plug the module's pins into the two 1 × 9
   sockets first. Then put the sockets into U1's footprint **from the back of the board**, module
   hanging below it, with the module's **USB-C end toward the middle of the board** and its
   **antenna end at the board's right-hand edge** (the back silkscreen says "USB-C end" and
   "antenna end", and marks pin 1 **5V** and pin 18 **TX**). Tack one pin of each socket from the
   top side, check everything sits square, then solder all 18 pins and pull the module out.
   Soldering with the module in keeps the two sockets exactly parallel.
4. **Clean** with IPA.

> [!CAUTION]
> The module also fits rotated 180°, which puts 5 V on a GPIO. Always check the USB-C end points
> into the board and the antenna end sits at the edge.

The module is flashed **out of its sockets** ([section 11, step 7](#11-bring-up)).

### The ribbon

A straight-through 10-way ribbon, pin 1 to pin 1 (Board A's J3 and Board B's J1 have the same
pinout, [Appendix A](#appendix-a-connectors-and-pinouts)). Crimp both IDC sockets with the red
stripe on pin 1, keys on the same side, so the cable isn't twisted. The box headers' keys then
stop it going in the wrong way.

---

## 10. Build the firmware

### Board A (STM32G431)

```sh
cd firmware/board-a
cmake -B build -G Ninja -DCMAKE_TOOLCHAIN_FILE=cmake/arm-none-eabi.cmake
cmake --build build
make -C tests                 # host tests for src/core (97,146 checks, ASan/UBSan)
```

That gives `build/board_a.elf`, `.bin` and `.hex`: 50–58 KB of the 126 KB available, depending on
the toolchain (the last 2 KB page holds calibration and settings). If the toolchain isn't on your PATH, add
`-DARM_TOOLCHAIN_DIR=/path/to/toolchain/bin` to the first `cmake` line.

### Board B (ESPHome on the ESP32-S3-Zero)

1. Create your secrets file:

   ```sh
   cd firmware/board-b
   cp secrets.yaml.example secrets.yaml
   ```

2. Fill it in: your Wi-Fi SSID and password; a fallback hotspot password (8+ characters); one
   **sync key** shared by every fixture (12–64 characters); and one **API key per fixture**,
   32 random bytes in base64, each made with:

   ```sh
   python3 -c "import os,base64;print(base64.b64encode(os.urandom(32)).decode())"
   ```

   Keep `secrets.yaml` out of version control (the `.gitignore` already does).

3. Compile each fixture's configuration once, to check it:

   ```sh
   esphome compile xtm-1.yaml       # the first run downloads the ESP32 toolchain
   ```

   `xtm-1.yaml` to `xtm-4.yaml` differ only in name and API key; they all include
   `xtm-common.yaml`, which is the device.

4. Optional tests (Linux or WSL):

   ```sh
   make -C tests                          # link client and sync logic, 89 checks
   cd tests/host
   esphome compile --only-generate xtm-host.yaml
   python3 build_host.py                  # ESPHome's Linux build with the system g++
   python3 run_host_test.py               # 43 end-to-end checks against a simulated Board A
   python3 check_sync_glue.py             # the ESP-NOW code against ESPHome's headers
   ```

Flashing happens during bring-up, below.

---

## 11. Bring-up

Seven steps from a bare, assembled Board A to a working light. Each step has a **pass** line;
stop at the first miss and see [troubleshooting](#16-troubleshooting). The tests are deliberately
the minimum that proves the board is safe and the loops behave; calibration and the flicker check
catch the rest.

Test points on Board A: **TP1** +48V, **TP2** +5V5, **TP3** +5VA, **TP4** +3V3, **TP5** VOUT,
**TP6** cathode tap, **TP7** BIAS, **TP8/TP9** GND, **TP10** buck DAC, **TP12/14/16/18** the four
setpoints, **TP13/15/17/19** the four sense points.

### Step 1: Before power

Inspect U1, U2, U3, U6 and U7 under magnification, and the polarity of D1–D3 and C1. Measure to
GND: TP1 (+48V) about 78 kΩ; TP5 (VOUT) about 170 kΩ; TP2, TP3 and TP4 above 1 kΩ once the meter
has charged the capacitors.

**Pass:** no reading under 10 Ω.

### Step 2: First power

No LED, no Board B. Bench supply to J1 (pin 1 +48V, pin 2 GND), set to 48 V with a **100 mA
limit**, and raise it slowly from 0 V: the aux rails start between 32 and 41 V.

**Pass:** input current under 30 mA; TP2 5.53 V ±3%, TP3 5.00 V ±1.5%, TP4 3.30 V ±2%, TP7 0.455 V
±2%; TP5 near 0 V (the main buck stays off until the firmware runs).

### Step 3: Flash Board A and boot

Plug the STLINK-V3MINIE into J4 (its cable is keyed); Board A stays powered from the bench supply
(the STLINK senses the target voltage but doesn't power it). Flash with any of:

```sh
STM32_Programmer_CLI -c port=SWD mode=UR -w build/board_a.elf -v -rst
openocd -f interface/stlink.cfg -f target/stm32g4x.cfg -c "program build/board_a.elf verify reset exit"
pyocd flash -t stm32g431cbux build/board_a.elf
```

Leave the option bytes at their factory values (nSWBOOT0 = 1, so the BOOT0 pin decides the boot
mode); check with `STM32_Programmer_CLI -c port=SWD -ob displ`. Open the STLINK's virtual COM
port at **115200 8N1** (any serial terminal). The status LED D4 blips every 2 s when idle.

**Pass:** the banner reads `dac80504=ok`; `st` shows `state=off`, `v48` within 1% of the supply,
`vout` 3.5 V (check at TP5), and all four temperatures (`t=`) within 3 °C of the room.

`st` prints one line of `key=value` fields. `fault=` is a number: 0 none, 1 short, 2 open LED,
3 over-temperature, 4 undervoltage, 5 DAC, 6 buck. The LED voltage is `vout` minus `vcath`.

### Step 4: No-load protection

Type `b 1`: full output with nothing connected, so no current can flow. Board A keeps raising
V_out looking for headroom, reaches its 38 V ceiling, reports an open LED and drops back to its
floor. It retries three times, 5 s apart, then latches.

**Pass:** within about 3 s, `st` shows `state=fault fault=2` and `vout` back at about 3.5 V.

Then type **`reboot`**. It clears the fault, and it also throws away the forward-voltage
corrections Board A learned while nothing was connected. They only live in RAM until something is
saved, but left in place they'd make the next start at that current look like a short.

> [!NOTE]
> Board A recognises an open LED only once V_out reaches its ceiling, which with the default LED
> model happens near full output (above roughly 0.9 A). At lower levels an open output just sits
> at a raised V_out with no fault. Whenever the LED has been disconnected with the light on,
> `reboot` before connecting it again. See the known issues in [the firmware reference](FIRMWARE.md#known-issues).

### Step 5: Dummy load, every channel

`set 9 0.3` (full scale 0.3 A for this step; not saved). Connect the dummy load (ten white LEDs)
to J2 (**pin 2 LED+, pin 1 LED−**) with the DMM in series, then step through `b 0.2`, `b 0.4`,
`b 0.6`, `b 0.8` and `b 1.0`: about 45 µA, 0.4 mA, 3.7 mA, 33 mA and 300 mA, which exercises all
four channels.

- **Pass, per point:** the DMM within 3% of `st` (5% at 45 µA; calibration fixes the rest), and
  the cathode between 0.5 and 1.2 V.
- **Loops:** on the scope, TP5 shows only the 400 kHz ripple (about 27 mV p-p) and the active
  channel's sense point (TP13, 15, 17 or 19) is flat DC, with no oscillation at any level. A snap
  from `b 0.3` to `b 0.9` moves V_out smoothly within about 2 ms.
- **Fades:** `b 1 10000`, then `lvl 0 10000`. No fault; smooth both ways, ending dark. (`b 0` is
  the bottom of the curve, 5 µA, not off; `lvl 0` and `off` are off.)
- **Short:** at `b 0.4`, short J2's pins with a wire. **Pass:** `state=fault fault=1` at once and
  the light off. Remove the wire, `clear`.

### Step 6: The XTM

`set 9 1.4`. With the light off, connect the XTM to J2: **red lead (LED+) to pin 2, black lead
(LED−) to pin 1** (the silkscreen says LED+ and LED−). Raise the supply's current limit to 2 A.
`b 1`.

**Pass:** `st` shows `i=` about 1.40, an LED voltage (`vout` − `vcath`) of 28.6–36 V and `vcath`
about 1.0 V. After
10 minutes at full, the FET sensor stays under 90 °C with no derating flag, and the supply draws
about 1 A.

### Step 7: Board B

1. With the ESP32-S3-Zero **out of Board B**, plug it into your computer with a USB-C cable and
   run `esphome run xtm-1.yaml` in `firmware/board-b`. If the port doesn't appear, unplug it, hold
   its **BOOT** button while plugging it back in, and run the command again.
2. Plug the module into Board B's sockets (USB-C end toward the middle of the board), connect the
   ribbon, and power Board A. The status LED is green for 2 s, then goes dark.

> [!WARNING]
> Never plug USB into the module while it's in Board B with the ribbon connected. Its 5V pin is
> its USB supply, so Board A's 5.5 V would push back into your computer. For USB logs in place,
> unplug the ribbon first. After the first flash, updates go over Wi-Fi.

**Pass:** Home Assistant shows the fixture with Driver link on; a 50% turn-on with a 2 s
transition fades in; the knob steps and the push toggles.

**Link loss:** unplug the ribbon with the light on. **Pass:** after 1.5 s the light blinks twice
and settles at 20%; plugged back in, it returns to its level within about a second.

Then calibrate, then check for flicker.

---

## 12. Calibrate

Each fixture needs one **current calibration** (about 10 minutes, scripted). **Light matching**
across fixtures is optional and takes another 10 minutes each. Both run over Board A's console
from `firmware/board-a/tools/calibrate.py` (`pip install pyserial`, plus `pyvisa` to read a SCPI
meter directly). On Windows the port is `COMx`; on Linux usually `/dev/ttyACM0`.

### Current, per fixture

**Setup:** a 6½-digit DMM (100 µA range for the bottom points, 3 A for the top) in series with
the XTM's red lead: J2 pin 2 → DMM → LED+. The XTM on its heatsink, the room near 25 °C, and
Board A warmed for 10 minutes at a middle level (the error budget assumes the board stays within
±20 °C of its calibration temperature).

```sh
cd firmware/board-a
python3 tools/calibrate.py current --port /dev/ttyACM0                   # type each DMM reading
python3 tools/calibrate.py current --port /dev/ttyACM0 --dmm "USB0::..."  # or let it read a SCPI meter
```

The script clears the old calibration, then:

1. reads the dark current with every sink off (tens of nA of board and FET leakage);
2. drives each channel alone in raw mode at eight points, two per band, each band on **both**
   channels that share it so they agree at every crossover: ch4 at 140 µA and 1.5 mA, ch3 at 1.5
   and 15 mA, ch2 at 15 and 150 mA, ch1 at 150 mA and 1.4 A (the 1.4 A point settles for 30 s);
3. measures the keep-alive current of channels 3, 2 and 1 as each channel's low point;
4. prints the result (`calshow`) and saves it to flash.

If `st` shows the cathode under 0.4 V at the 1.4 A point (a high-V_f module with a high-burden
meter), measure that point across a 0.1 Ω four-terminal reference resistor with the DMM on volts.

**Result:** ±0.09–0.11% RSS in each range (±0.17–0.32% worst case); in the tail ±0.6% at 14 µA
and ±1.6% at 5 µA. Spot-check by putting the meter back and comparing `st` at a few `b`
positions per range.

### Light matching across fixtures (optional)

The XTM's flux tolerance is ±10%, so four fixtures at the same current can differ by up to 20%
in light. Matching makes them agree at every level (the brightest fixtures then run a little
under 1.4 A at 100%).

1. On each fixture, after its current calibration: a lux meter on the beam axis at a fixed
   distance in a dark room, the fixture warmed 5 minutes at full, then
   `python3 tools/calibrate.py lux --port ...`. It drives 0.14 A and 1.4 A, asks for the two lux
   readings and stores them. Home Assistant then shows the fixture's **Full scale light**.
2. Take the **lowest** full-scale reading of the four as the fleet reference and set it on every
   fixture: `python3 tools/calibrate.py fleet --port ... --ref <lux>`, or the **Fleet reference
   light** number in Home Assistant. 0 turns matching off.

### Where it's stored, and backing it up

Everything lives in the last 2 KB flash page of Board A (magic `XTM1`, CRC-32), which firmware
updates leave alone unless you mass-erase the chip. Writes wait until the light is off or under
10 mA and not fading. **Save each board's `calshow` and `params` output to a text file:** if its
flash is ever erased, `raw ch code` then `cal ch amps` for each listed point, and `set` for each
parameter, then `save`, restores it without the meter (add `dark_a` with the dark current `calshow`
listed). A replacement Board A needs its own calibration.

---

## 13. Verify flicker

**Pass** means nothing over 1% between 100 Hz and 20 kHz at any level, no step or reversal
during a fade, and a smooth fade to black. By design the only periodic content is the buck's
400 kHz ripple (about 0.1% at the bottom of the range) and the 4 kHz fade updates.

### The photodiode rig

- **Sensor:** a BPW34 PIN photodiode at zero bias into a transimpedance amplifier: cathode to the
  op-amp's −IN, anode to ground. A FET-input op-amp (OPA140, for example) on two 9 V batteries,
  so no bench-supply ripple gets in.
- **Gain:** 10 kΩ ∥ 100 pF for the top of the range (160 kHz bandwidth); 1 MΩ ∥ 2.2 pF for the
  bottom (72 kHz).
- **Placement:** down to about 1 mA, 0.5–1 m from the fixture on its axis at 10 kΩ; below that,
  against the fixture's front at 1 MΩ, under a black cloth. Aim for 0.3–3 V out.
- **Capture:** read the DC level DC-coupled, then capture the ripple AC-coupled: 200 ms at
  1 MS/s or faster, exported as CSV. Then:

  ```sh
  python3 tools/flicker.py ripple.csv --mean <DC volts>     # add --dark <volts>: the output with the light off
  ```

  It reports percent flicker below 20 kHz, the largest line from 100 Hz to 20 kHz and the largest
  at 25 kHz and above, then PASS or FAIL.

### What to capture

Light matching off (fleet reference 0), so each `b` below is the current shown.

| Capture | Console | Pass |
| --- | --- | --- |
| Steady levels | `b 1` (1.4 A), `b 0.822` (150 mA), `b 0.638` (15 mA), `b 0.455` (1.5 mA), `b 0.266` (140 µA), `b 0.082` (14 µA), `b 0` (5 µA) | Percent flicker and every line from 100 Hz to 20 kHz ≤ 1% |
| Crossings at the 10 s full-range rate | `b 0.78`, then `b 0.86 800` and back with `b 0.78 800`; the same between 0.60 and 0.68, and 0.41 and 0.49 | Largest departure ≤ 0.3%, no reversal |
| Crossings at the 1 s rate | The same with 80 instead of 800 | ≤ 2%, no reversal |
| Fade to black | From `b 0.3`, `lvl 0 3000` | Smooth to dark, no step at the end |
| Snaps | From off, `b 0.5`; then `b 1` | One rise within 5 ms, no overshoot |

For fades, capture DC-coupled in the scope's high-resolution mode (100 kS/s is plenty) and run
`python3 tools/flicker.py fade.csv --fade`: it compares a 1 ms average with the fade's own trend
and counts any moment the light moves against the fade.

### The phone check

Film a white wall lit by the fixture in **240 fps slow motion**, waving a pencil quickly in front
of it, at the steady levels above and during a 10 s fade. Then, in the camera's manual mode at
1/4000 s or faster, watch the wall in the live view. **Pass:** no rolling bands, no pulsing, a
smooth fade. A PWM-dimmed light shows bands in the same test, which makes a useful comparison.

---

## 14. Install it in the fixture

```mermaid
flowchart LR
  inlet["Fused, switched<br/>IEC inlet"] -->|mains| psu["LRS-100-48<br/>case earthed"]
  psu -->|"48 V, 18–20 AWG"| J1["Board A · J1"]
  J2["Board A · J2"] -->|"XTM leads ≤ 400 mm"| led(["XTM on its heatsink"])
  J3["Board A · J3"] ---|"10-way ribbon ≤ 0.5 m"| B["Board B · J1<br/>on the control panel"]
```

**The supply.** Mount the LRS-100-48 on its own, with a fused, switched IEC inlet; earth its FG
terminal (it's a Class I supply) and cover its terminals. Leave its output at 48 V: the buck's
timing margins assume at least 48 V in. Wire its +V and −V to Board A's J1 (pin 1 **+48V**, pin 2
**GND**) with 18 or 20 AWG. Only the supply's case is earthed: Board A's holes are unplated and
the 48 V side, the LED and its heatsink all stay floating, which keeps the heatsink's capacitance
out of the LED's ripple path.

**Board A.** On 10 mm M3 standoffs with free air on both faces, near a vent, within about 300 mm
of the XTM (its leads are 400 mm and aren't extended). If it stands vertically, put the J1/J2 edge
at the top so the power section's warm air doesn't rise across the precision island. It
dissipates about 2.8 W at full output: roughly 22 °C above the enclosure air on average.

**The LED.** Red lead to J2 pin 2 (LED+), black to pin 1 (LED−). Twisting the two leads together
keeps them from radiating.

**Board B.** On the control panel: the encoder's shaft through the panel with its nut as the
third fixing, plus the two M3 holes. Leave **12–14 mm behind the board** (plus a millimetre or
two) for the module on its sockets. Keep the antenna end (the board's right-hand edge, seen from
the front) clear of metal by 15 mm, or give it a plastic window, and keep Board B at least
100 mm from Board A and the LED leads.

**Enclosure materials.** PETG or ASA for anything touching Board A or the LED heatsink; PLA
softens too easily.

**Optional panel sync button:** a normally-open push button on a JST PH 2-pin lead into Board B's
J3, in parallel with the on-board sync button.

---

## 15. Use it

### Home Assistant

Each fixture appears as an ESPHome device (Settings → Devices & services, discovered
automatically on the same network). When you add it, Home Assistant asks for the **encryption
key**: that fixture's `xtmN_api_key` from `secrets.yaml`.

It shows up as one **dimmable light**, plus:

| Kind | Entities |
| --- | --- |
| Sensors | LED current and voltage, driver output and 48 V input voltages, four temperatures |
| Status | Driver state, fault, sync role, firmware; link, derating, calibrated and light-matched flags |
| Buttons | Clear fault, identify (blinks the light), restart driver |
| Settings | Link-loss level, bottom current, full-scale current, fleet reference light, link timeout |
| Switch | Sync lead |

Brightness goes to Board A as a level on its own exponential curve, and a transition goes as one
fade command that Board A runs, so fades are as smooth from Home Assistant as from the knob.

### On the fixture

- **Knob:** one detent is 1% of the brightness scale (about 13% more or less light) as an 80 ms
  fade; spinning fast takes 2× or 4× steps. Turning up from off starts at the bottom; turning
  down stops at the bottom.
- **Push:** toggles on and off with a 400 ms fade.
- **Sync button:** makes this fixture the **lead**: every other fixture follows its level. Press
  it on another fixture and the lead moves there; press it on the lead to end the group (every
  fixture keeps its level). Adjusting a follower by hand takes it out of the group.

Sync runs fixture to fixture over ESP-NOW, with no router or Home Assistant in the path. Every
fixture in a group must be on the **same Wi-Fi access point** (ESP-NOW shares the radio's
channel) and have the same `sync_key`.

### The status LED (on Board B)

| Pattern | Meaning |
| --- | --- |
| Green for 2 s | Starting |
| Red, slow blink | No link to Board A |
| Red, fast blink | Board A reports a fault (see the Fault sensor) |
| Blue, steady | This fixture leads the sync group |
| Blue, short blip each second | This fixture follows the group |
| Amber blip every 3 s | Not connected to Wi-Fi (the fixture still works) |
| Off | Normal |

### What happens when something restarts

| What restarts | What happens |
| --- | --- |
| Both boards (power-up) | The light's saved state fades in over 1 s |
| Board B, planned (OTA, restart button) | Board A holds the level; nothing visible |
| Board B, crash or ribbon unplugged | After 1.5 s Board A blinks twice and settles at 20% (the link-loss level); Board B restores the previous level when it's back |
| Board A | Board B sends its level again over 1 s |

### Updating firmware later

Board B: `esphome run xtm-N.yaml` over Wi-Fi (the light holds its level during the update).
Board A: flash with the STLINK as in step 3; its calibration page is kept.

### A venue without Wi-Fi

Every fixture works on its own without Wi-Fi (amber blip). For reliable sync with no access
point at all, make a variant of `xtm-common.yaml` with `wifi:`, `api:`, `ota:` and
`captive_portal:` removed and `espnow: channel: 1` added; you lose Home Assistant and
over-the-air updates (reflash over USB-C with the module out).

---

## 16. Troubleshooting

| Symptom | Likely cause | What to do |
| --- | --- | --- |
| Step 2: aux rails don't start by 41 V | F1 open, D1 reversed, U3 or its EN divider | Check TP1 reaches 48 V; check D1's band; reflow U3 |
| Step 2: input current well over 30 mA | A short on a rail, or a reversed part | Find the hot part (a finger or thermal camera), check D1–D3 and C1 |
| Step 3: SWD won't connect | J4 cable orientation, U1 soldering, NRST held low | Check +3V3 at TP4, reflow U1, check C78 |
| Step 3: banner lacks `dac80504=ok` | U6 soldering or orientation, SPI | Reflow U6 (pin 1!), check R40–R43 |
| Step 3: V_out not 3.5 V when idle | Buck feedback network, BUCK_DAC | Check R12–R15 values, TP10 |
| Step 4: no `fault=2` at `b 1` | Cathode tap reading high, or V_out not reaching its ceiling | Check R110, C61, D3; check TP5 climbs toward 38 V |
| `fault=2` (open) with the LED connected | LED not connected, or wired backwards | Check J2 wiring: red to pin 2. The XTM is damaged by reverse polarity |
| `fault=1` (short) straight away | A real short; the cathode tap reading high; or forward-voltage corrections learned while the LED was disconnected | Check J2 and the LED leads, D3 and C61; `reboot` and try again |
| Oscillation at a sense point | Wrong compensation or gate resistor | Check C52–C55 (2.2 nF C0G), R60–R63 (1 kΩ), R68–R71 (220 Ω) |
| Current off by more than a few % before calibration | 0.1% resistors swapped with 1% ones | Compare against `board_a-sheets.md`; calibrate |
| Bottom of the range drifts or reads high | Flux residue (leakage) | Clean the board again ([section 8](#8-assemble-board-a)) |
| Bottom of a fade jumps or drops out | The LED's own low-current behaviour | Raise the **Bottom current** setting |
| Derating flag at full output | Not enough airflow around Board A | Standoffs, free air, vents; lower headroom if needed |
| Red slow blink on Board B | No link | Ribbon orientation (pin 1 to pin 1); Board A powered and flashed; module the right way round |
| ESP32-S3-Zero not seen over USB | Not in download mode | Hold BOOT while plugging in the cable |
| Board B doesn't start at all | Module rotated 180° in its sockets | Power off, turn it round; the module may be damaged |
| Amber blip | No Wi-Fi | Check `wifi_ssid`/`wifi_password`; the fixture's own hotspot appears as its name |
| Sync doesn't reach another fixture | Different access point or sync key | Same AP and the same `sync_key` on every fixture |

---

## Appendix A: Connectors and pinouts

### Board A

**J1, 48 V in** (Phoenix MSTBA 2,5/2-G-5,08; plug MSTB 2,5/2-ST-5,08): pin 1 **+48V**, pin 2 **GND**.

**J2, LED out** (the same connector): pin 1 **LED− (CATHODE)**, pin 2 **LED+ (VOUT)**.

**J3, ribbon to Board B** (2 × 5 box header, 2.54 mm):

| Pin | Signal | Direction | Pin | Signal | Direction |
| --- | --- | --- | --- | --- | --- |
| 1 | +5V5 | A → B | 2 | GND | |
| 3 | +5V5 | A → B | 4 | GND | |
| 5 | UART TX (Board A) | A → B | 6 | GND | |
| 7 | UART RX (Board A) | B → A | 8 | BOOT0 | B → A |
| 9 | A_OK | A → B | 10 | NRST | B → A (open-drain) |

Board B's J1 has the same pinout; the ribbon is straight-through. UART at 115200 8N1 with 100 Ω
series resistors at each end.

**J4, debug** (STDC14, Samtec FTSH-107, for the STLINK-V3MINIE): 3 +3V3 (sense), 4 SWDIO,
5/7/11 GND, 6 SWCLK, 12 NRST, 13 VCP_RX, 14 VCP_TX; 1, 2, 8–10 not connected.

**Board A MCU (STM32G431CBU6)**

| Pin | Use |
| --- | --- |
| PA0 | V_out sense |
| PA1 | Cathode tap (ADC and COMP1, the short trip) |
| PA2 / PA3 | USART2 console, through the STLINK's virtual COM port |
| PA4 | DAC1 → buck feedback injection |
| PA6, PA7, PB2, PB15 | Gate monitors, channels 1–4 |
| PC6, PA8, PC10, PB7 | Gate clamps, channels 1–4 |
| PA9 / PA10 | USART1 to Board B (also the ROM bootloader's port) |
| PA11 | A_OK to Board B |
| PA12 | Status LED D4 |
| PA13 / PA14 | SWD |
| PA15, PB3, PB4, PB5 | SPI1 to the DAC80504 |
| PB0 | 48 V sense |
| PB1, PB11, PB12, PB14 | NTCs: channel-1 FET, main buck, aux rails, precision section |
| PB8-BOOT0 | 10k pull-down; Board B can raise it |
| PC13 / PC4 | Main buck EN / power-good |
| NRST | 100 nF; driven by the STLINK and by Board B |

Free: PA5 (on TP11), PB6, PB9, PB10, PB13, PC11, PC14, PC15, PF0, PF1.

### Board B

**J3, external sync button** (JST PH 2-pin): 1 SYNC_RAW (the sync input before its RC filter),
2 GND. Normally open, in parallel with SW4.

**J4, spare** (1 × 5, 2.54 mm): 1 +3V3, 2 IO3, 3 IO43 (UART0 TX), 4 IO44 (UART0 RX), 5 GND.

**ESP32-S3-Zero (U1) in its sockets**

| GPIO | Module pin | Use |
| --- | --- | --- |
| 5V / GND / 3V3 | 1 / 2 / 3 | Power: 5V from the ribbon through a ferrite and a Schottky; 3V3 from the module's own regulator |
| IO1 / IO2 | 4 / 5 | UART1 TX / RX to Board A |
| IO3 | 6 | Spare (a strapping pin), on J4 |
| IO4 / IO5 / IO6 | 7 / 8 / 9 | Encoder A / B / push |
| IO7 | 10 | Sync button and J3 |
| IO8 | 11 | BOOT0 to Board A |
| IO9 | 12 | A_OK from Board A (100k pull-down: an unplugged ribbon reads "not OK") |
| IO10 | 13 | NRST to Board A, open-drain |
| IO11 / IO12 / IO13 | 14 / 15 / 16 | Red / green / blue status LEDs, active low |
| IO44 / IO43 | 17 / 18 | Spare (UART0, the ESP32's console), on J4 |

---

## Appendix B: Board A console

On the STLINK's virtual COM port at 115200 8N1. Every command answers with `key=value` lines and
ends with a line starting `ok` or `err`.

| Command | Does |
| --- | --- |
| `st` | One status line: `state`, `fault` (0 none, 1 short, 2 open, 3 over-temperature, 4 undervoltage, 5 DAC, 6 buck), `level`, `target`, current `i`, `vout`, `vcath`, `v48`, DAC codes, gate monitors, temperatures, link |
| `lvl L [ms]` | Set a level, 0–65535, with an optional fade time |
| `b pos [ms]` | Set a position on the brightness curve, 0–1, with an optional fade time |
| `off` | Off |
| `raw ch code`, `rawi ch amps`, `ka ch`, `dark`, `exit` | Calibration mode: one channel alone at a DAC code, at a current, at its keep-alive, or all off; `exit` leaves |
| `cal ch amps` | Record the measured current for the raw channel's present code |
| `calreset ch`, `calshow`, `dark_a amps` | Calibration housekeeping |
| `set id value`, `get id`, `params` | Settings (ids in `firmware/board-a/src/core/link_protocol.h`, `enum link_param`) |
| `save` | Write calibration and settings to flash (waits until the light is off or under 10 mA) |
| `vf` | The learned forward-voltage table |
| `clear` | Clear a latched fault |
| `id [n]` | Blink to identify |
| `defaults` | Factory defaults (not saved) |
| `reboot` | Restart |

---

## Appendix C: Pre-order checklist

Nothing here is a new test; each item catches a mistake that would cost a board revision or a
parts order.

### Design files

- [ ] If you captured your own schematics: `compare_netlists.py` reports no differences against
      the generated netlists.
- [ ] `python3 design/build.py`: 0 ERC errors. DRC in KiCad 9 with the `.kicad_dru` rules in place:
      0 errors, 0 unconnected.
- [ ] Board A's layout meets `hardware/LAYOUT.md`: Kelvin pairs from the shunts' sense pads,
      switch nodes on the top layer only, the precision island's ground cage, J2's slot.
- [ ] Footprints checked against datasheets: U6 DAC80504 (RTE0016D, 0.8 mm pad), U7 OPA4388,
      U2/U3 LMR38020, U1 STM32G431CBU6, R102 WSK2512, Q1 NDT3055L, D3 BAV199, J4 STDC14, the
      ESP32-S3-Zero socket footprint, and the PEC11R on its round lug holes.
- [ ] Both boards printed 1:1 with the tall and odd parts laid on them, and the ESP32-S3-Zero on a
      mirrored print of Board B's back.
- [ ] Mechanics: Board A's standoffs, air space and wire access; Board B's shaft length, 12–14 mm
      behind it, antenna clear of metal.
- [ ] Silkscreen: polarity at J1 and J2, pin-1 marks, the module's orientation marks.
- [ ] Gerbers opened in a viewer: four copper layers (Board A) in order, two (Board B); J2's slot;
      paste layers present.

### Fabrication order

- [ ] Board A: 4 layers, 1.6 mm, standard stackup, ENIG, 1 oz outer / 0.5 oz inner, tented vias.
      Board B: 2 layers, 1.6 mm, ENIG.
- [ ] 10 of each; a 0.12 mm stencil for each.
- [ ] Only if JLC places parts: CPL from `layout/out/`, every rotation checked in their preview.

### Parts order

- [ ] Stock checked on the day, for seven sets, from the hand-assembly BOMs.
- [ ] LMR38020**F**DDAR; PEC11R-4220**F**-S0024 from Digi-Key/Mouser/Newark; FTSH-107-01-L-DV-K
      (not -K-A); Phoenix 1757019 plugs for J1/J2.
- [ ] Precision parts from franchised distributors; WSK2512R1000FEA or the WSL2512R1000FEA
      fallback for R102.
- [ ] Every descriptive line: value, voltage, dielectric and size checked.
- [ ] Off-board items: XTMs and heatsinks, LRS-100-48s and inlets, standoffs, ribbon and IDC
      sockets, knobs, STLINK-V3MINIE, USB-C cable.

### Firmware

- [ ] `esphome compile xtm-1.yaml` succeeds on your machine.
- [ ] `secrets.yaml` created: one API key per fixture, one shared sync key.
- [ ] Board A builds (`cmake --build build`) and `make -C tests` passes.

### Bench

- [ ] Bring-up: 60 V current-limited supply, DMM, scope, dummy load.
- [ ] Calibration: 6½-digit DMM with a 100 µA range; lux meter if light-matching.
- [ ] Flicker: photodiode rig parts; a phone with 240 fps slow motion.

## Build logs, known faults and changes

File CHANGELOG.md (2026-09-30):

# Changelog

Design revisions, newest first. Board A's silkscreen says **rev 1**, Board B's **rev 2**. Nothing
has been fabricated yet.

## Board B rev 2: socketed ESP32-S3-Zero (30 September 2026)

- The ESP32-S3-WROOM-1 and its USB-C receptacle, USB ESD part, 3.3 V regulator and reset/boot
  circuit are replaced by a **Waveshare ESP32-S3-Zero-M** plugged into two 1 × 9 sockets on the
  back of the board: 17 fewer parts, no 0.5 mm-pitch USB-C to hand-solder, and a module that comes
  out to be flashed.
- The link to Board A moves from IO17/IO18 to **IO1/IO2**, keeping UART0 off Board A's line; every
  other signal keeps its GPIO. IO3, IO43 and IO44 go to a spare header, J4.
- New footprint `layout/lib/XTM.pretty/ESP32-S3-Zero_Socket` with an antenna copper keep-out;
  back silkscreen marks the module's name, both ends, and pins 5V and TX.
- Board B: 42 parts, 32 nets; layout 0 DRC errors, 0 unconnected.
- ESPHome config: 4 MB flash, new UART pins.

## Scripted layout (29–30 September 2026)

- Both boards laid out by `layout/` scripts in KiCad 9 with Freerouting 1.9.0: 0 DRC errors and
  0 unconnected on both.
- Ground fan-out before routing, router keep-outs around the cathode copper, clean-up of router
  leftovers, pour stitching with island removal held off, pad tracking by UUID.
- High-voltage clearances per IPC-2221B (0.5 mm with bare pads, 0.3 mm coated); L3 carries
  signals; Q1 gets 2.3 cm² + 2.8 cm² of copper and 39 vias (thermal estimate 50 °C/W, junction
  about 127 °C in 45 °C air).
- Gerbers, drill files and JLCPCB placement files exported to `layout/out/`.

## Phase 2 final check (29 September 2026)

- DAC80504 reference halved and gain doubled (REFDIV and GAIN strapped high); footprint TI
  RTE0016D with the 0.8 mm exposed pad.
- Main buck enable moved from PB9 (the ROM bootloader's CAN TX, which idles high) to PC13.
- WSL2512R1000FEA named as a stocked fallback for the WSK2512 0.1 Ω shunt.
- J4 is the FTSH-107-01-L-DV-K; round lug holes for the encoder; a tactile-switch footprint KiCad
  still ships.
- BOM corrections: encoder, inductor saturation currents, JLC classes and fees, stock notes,
  J1/J2 plugs.
- Thermal estimate redone on the real 90 × 60 mm outline.

## Phase 2 detailed design (27–29 September 2026)

- Every value on both boards, from `design/calc.py` and `design/sim/handover.c`.
- Crossover fix: keep-alive priming and a log-domain blend (simulated dip from 3.5% to 0.14% on
  a 10 s fade).
- 22 nF across the LED; free-running bucks; buck held off while the MCU is in reset; feedback
  network rescaled for the DAC's output range; C_C 2.2 nF on all channels; op-amp output
  monitors; 3 A input fuse; sequenced on/off with a voltage-mode tail to black.
- Schematics as code with a connectivity check; BOMs with verified part numbers.
- Board A firmware (C, STM32G431) and Board B firmware (ESPHome + external component), both
  tested on a PC.
- Bring-up, calibration and flicker-verification procedures.

## Phase 1 design review (26 September 2026)

- Forced-PWM buck instead of pulse-skipping; a fourth DC range (100 Ω) instead of PWM for the
  bottom decade; the headroom loop moves into an MCU on Board A with feed-forward.
- 100 W supply, a static blend without hysteresis, a fast short-circuit trip, a V_out floor, a
  zero bias and gate clamps.
- STM32G431 on Board A; UART over a 10-way ribbon; ESP-NOW for fixture sync.

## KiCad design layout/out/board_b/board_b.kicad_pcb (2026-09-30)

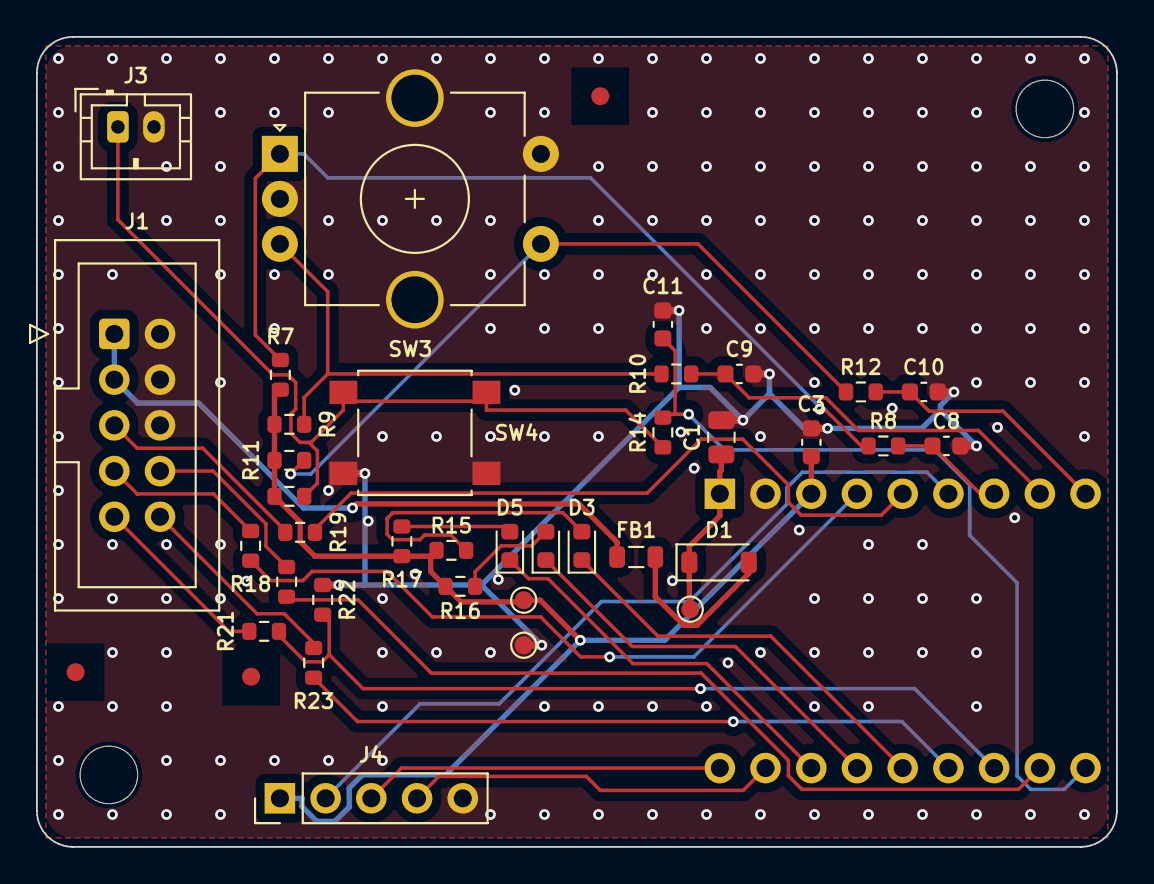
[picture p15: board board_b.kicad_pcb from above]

Board: 2 copper layers, 60.0 x 45.0 mm, 42 parts (1 on the bottom side), 32 nets.

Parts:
C1: 10uF; C_0805_2012Metric
C3: 100nF; C_0603_1608Metric
C8, C9, C10, C11: 10nF; C_0603_1608Metric
D1: B5819W; D_SOD-123
D3: red; LED_0603_1608Metric
D4: green; LED_0603_1608Metric
D5: blue; LED_0603_1608Metric
FB1: 600R@100MHz 2A; L_0805_2012Metric
FID1, FID2, FID3: FID; Fiducial_1mm_Mask2mm
H1, H2: M3; MountingHole_3.2mm_M3
J1: 2x5 box header; IDC-Header_2x05_P2.54mm_Vertical
J3: JST PH 2; JST_PH_B2B-PH-K_1x02_P2.00mm_Vertical
J4: 1x5 header; PinHeader_1x05_P2.54mm_Vertical
R7, R8, R9, R10, R11, R12, R13, R14: 10k; R_0603_1608Metric
R15: 1k; R_0603_1608Metric
R16, R17: 220R; R_0603_1608Metric
R18, R19, R20, R21, R23: 100R; R_0603_1608Metric
R22: 100k; R_0603_1608Metric
SW3: PEC11R-4220F-S0024; RotaryEncoder_Alps_EC11E-Switch_Vertical_H20mm_CircularMoun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
SW4: SYNC; SW_SPST_B3S-1000
TP1, TP2, TP3: TP; TestPoint_Pad_D1.0mm
U1: ESP32-S3-Zero-M; ESP32-S3-Zero_Socket

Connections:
+3V3: C3.1, J4.1, R7.1, R9.1, R11.1, R13.1, R15.1, R16.1, R17.1, TP2.1, U1.3
+5V5_F: D1.2, FB1.2
+5V5_IN: FB1.1, J1.1, J1.3
+5V_SYS: C1.1, D1.1, TP1.1, U1.1
A_OK: J1.9, R21.1
A_OK_IN: R21.2, R22.1, U1.12
BOOT0_A: J1.8, R20.2
BOOT0_OUT: R20.1, U1.11
ENC_A: C8.1, R8.2, U1.7
ENC_A_RAW: R7.2, R8.1, SW3.A
ENC_B: C9.1, R10.2, U1.8
ENC_B_RAW: R9.2, R10.1, SW3.B
ENC_SW: C10.1, R12.2, U1.9
ENC_SW_RAW: R11.2, R12.1, SW3.S1
GND: C1.2, C3.2, C8.2, C9.2, C10.2, C11.2, J1.2, J1.4, J1.6, J3.2, J4.5, R22.2, SW3.C, SW3.MP, SW3.S2, SW4.2, TP3.1, U1.2
LED_B: D5.1, U1.16
LED_B_A: D5.2, R17.2
LED_G: D4.1, U1.15
LED_G_A: D4.2, R16.2
LED_R: D3.1, U1.14
LED_R_A: D3.2, R15.2
LINK_RX: R19.2, U1.5
LINK_TX: R18.1, U1.4
NRST_A: J1.10, R23.2
NRST_OUT: R23.1, U1.13
RXD_A: J1.7, R18.2
SPARE_IO3: J4.2, U1.6
SPARE_IO43: J4.3, U1.18
SPARE_IO44: J4.4, U1.17
SYNC: C11.1, R14.2, U1.10
SYNC_RAW: J3.1, R13.2, R14.1, SW4.1
TXD_A: J1.5, R19.1

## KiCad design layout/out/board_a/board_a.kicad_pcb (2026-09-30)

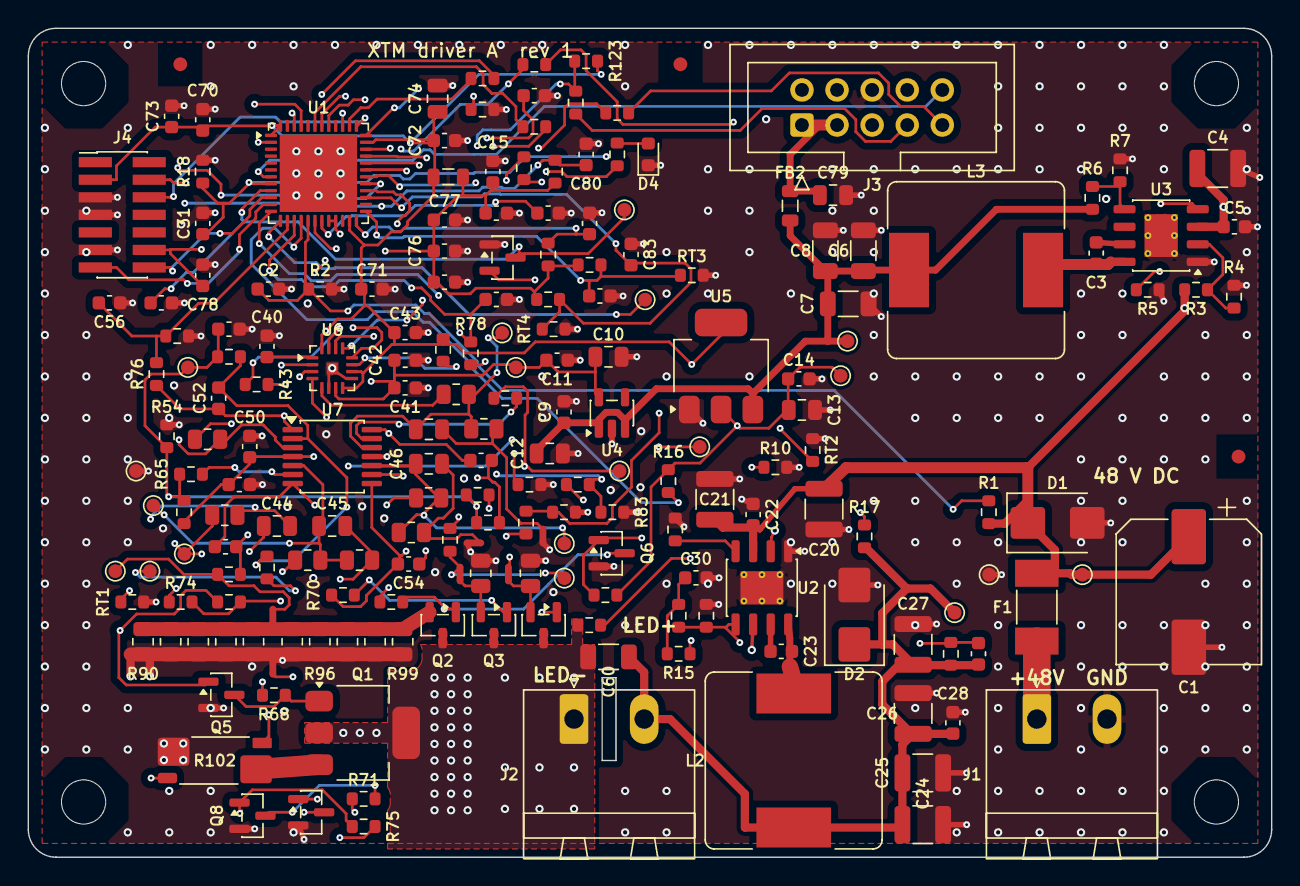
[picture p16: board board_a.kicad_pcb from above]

Board: 4 copper layers, 90.0 x 60.0 mm, 206 parts (0 on the bottom side), 96 nets.

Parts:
C1: 47uF 100V; CP_Elec_10x10
C2, C31, C80, C81, C82, C83: 10nF; C_0603_1608Metric
C3, C11, C14, C16, C23, C41, C43, C50, C70, C71, C72, C73, C76, C77, C78: 100nF; C_0603_1608Metric
C4, C20, C21, C24, C25, C26, C27: 4.7uF 100V; C_1210_3225Metric
C5, C22, C28: 100nF 100V; C_0603_1608Metric
C6, C7, C8: 22uF; C_1206_3216Metric
C9, C15, C42, C48, C51, C75: 1uF; C_0603_1608Metric
C10, C12, C74: 4.7uF; C_0805_2012Metric
C13, C79: 10uF; C_0805_2012Metric
C29: 22pF C0G; C_0603_1608Metric
C30: 47nF; C_0603_1608Metric
C40: 220nF; C_0603_1608Metric
C44, C45, C46, C47: 10nF C0G; C_0805_2012Metric
C52, C53, C54, C55: 2.2nF C0G; C_0603_1608Metric
C56, C57, C58, C59, C61: 1nF C0G; C_0603_1608Metric
C60: 22nF 100V; C_1206_3216Metric
D1: SMBJ58A; D_SMB
D2: SMBJ43A; D_SMB
D3: BAV199; SOT-23
D4: green; LED_0603_1608Metric
F1: 3A T; Fuse_Littelfuse-NANO2-451_453
FB1: 600R@100MHz; L_0805_2012Metric
FB2: 600R@100MHz 2A; L_0805_2012Metric
FID1, FID2, FID3: FID; Fiducial_1mm_Mask2mm
H1, H2, H3, H4: M3; MountingHole_3.2mm_M3
J1, J2: MSTBA 2,5/2-G-5,08; PhoenixContact_MSTBA_2,5_2-G-5,08_1x02_P5.08mm_Horizontal
J3: 2x5 box header; IDC-Header_2x05_P2.54mm_Vertical
J4: STDC14; PinHeader_2x07_P1.27mm_Vertical_SMD
L2: 33uH; L_Bourns_SRR1260
L3: 15uH; L_Bourns_SRR1260
NT1, NT2, NT3, NT4, NT5, NT6: NetTie; NetTie-2_SMD_Pad0.5mm
Q1: NDT3055L; SOT-223-3_TabPin2
Q2, Q5, Q6, Q7, Q8: 2N7002BK; SOT-23
Q3, Q4: 2N7002; SOT-23
R1, R6, R10, R16, R72, R73, R74, R75, R76, R77, R78, R79, R80, R81, R82, R83, R123: 100k; R_0603_1608Metric
R2: 6.2k; R_0603_1608Metric
R3: 280k; R_0603_1608Metric
R4, R44, R53, R120, R126, R127, R128, R129: 10k; R_0603_1608Metric
R5: 52.3k; R_0603_1608Metric
R7: 22.1k; R_0603_1608Metric
R11: 64.9k; R_0603_1608Metric
R12: 200k; R_0603_1608Metric
R13: 7.32k; R_0603_1608Metric
R14, R15: 8.25k; R_0603_1608Metric
R17, R110: 1M; R_0603_1608Metric
R18: 82k; R_0603_1608Metric
R40, R41, R42, R43: 22R; R_0603_1608Metric
R45, R47, R49, R51: 12.0k 0.1%; R_0805_2012Metric
R46, R48, R50, R52: 1.00k 0.1%; R_0805_2012Metric
R54, R60, R61, R62, R63, R125: 1k; R_0603_1608Metric
R64, R65, R66, R67: 1.82M; R_0603_1608Metric
R68, R69, R70, R71: 220R; R_0603_1608Metric
R90, R91, R92, R93, R94, R95, R96, R97, R98, R99, R100: 10R 0.1%; R_0805_2012Metric
R101: 100R 0.1%; R_0805_2012Metric
R102: 0.1R 4T; R_Shunt_Vishay_WSK2512_6332Metric_T1.19mm
R121, R122, R124: 100R; R_0603_1608Metric
RT1, RT2, RT3, RT4: 10k NTC; R_0603_1608Metric
TP1, TP2, TP3, TP4, TP5, TP6, TP7, TP8, TP9, TP10, TP11, TP12, TP13, TP14, TP15, TP16, TP17, TP18, TP19: TP; TestPoint_Pad_D1.0mm
U1: STM32G431CBU6; QFN-48-1EP_7x7mm_P0.5mm_EP5.6x5.6mm
U2, U3: LMR38020FDDAR; HSOP-8-1EP_3.9x4.9mm_P1.27mm_EP2.41x3.1mm_ThermalVias
U4: TPS7A2050PDBVR; SOT-23-5
U5: LDL1117S33R; SOT-223-3_TabPin2
U6: DAC80504RTET; Texas_RTE0016D_WQFN-16-1EP_3x3mm_P0.5mm_EP0.8x0.8mm
U7: OPA4388IPWR; TSSOP-14_4.4x5mm_P0.65mm

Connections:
+3V3: C13.1, C14.1, C43.1, C70.1, C71.1, C72.1, C73.1, C74.1, D3.2, FB1.1, J4.3, R16.2, R44.2, R72.2, R73.2, R74.2, R75.2, R123.2, TP4.1, U1.1, U1.23, U1.35, U1.48, U5.2, U6.8, U6.10, U6.16
+3V3A: C15.1, C16.1, C75.1, C76.1, C77.1, FB1.2, R126.1, R127.1, R128.1, R129.1, U1.20, U1.21
+5V5: C6.1, C7.1, C8.1, C9.1, C12.1, FB2.1, L3.2, R6.1, TP2.1, U4.1, U4.3, U5.3
+5V5_LINK: C79.1, FB2.2, J3.1, J3.3
+5VA: C10.1, C11.1, C41.1, C42.1, C50.1, C51.1, R53.1, TP3.1, U4.5, U6.7, U7.4
+48V: C1.1, C4.1, C5.1, C20.1, C21.1, C22.1, D1.1, F1.2, R1.1, R3.1, TP1.1, U2.3, U3.3
+48V_RAW: F1.1, J1.1
AUX_BOOT: C3.1, U3.7
AUX_EN: R3.2, R4.1, U3.2
AUX_FB: R6.2, R7.1, U3.5
AUX_RT: R5.1, U3.4
AUX_SW: C3.2, L3.1, U3.8
A_OK: J3.9, R124.2
A_OK_MCU: R124.1, U1.33
BIAS: C48.1, R53.2, R54.1, R64.1, R65.1, R66.1, R67.1, TP7.1
BOOT0: J3.8, R120.1, U1.46
BUCK_BOOT: C23.1, U2.7
BUCK_DAC: R15.2, TP10.1, U1.12
BUCK_EN: R10.1, U1.2, U2.2
BUCK_FB: C29.2, R12.2, R13.1, R14.1, U2.5
BUCK_PG: R16.1, U1.16, U2.6
BUCK_RT: R11.1, U2.4
BUCK_SW: C23.2, L2.1, U2.8
CATHODE: C60.2, J2.1, Q1.2, Q2.3, Q3.3, Q4.3, R110.1
CATH_TAP: C61.1, D3.3, R110.2, TP6.1, U1.9
CLAMP1: Q5.1, R72.1, U1.29
CLAMP2: Q6.1, R73.1, U1.30
CLAMP3: Q7.1, R74.1, U1.39
CLAMP4: Q8.1, R75.1, U1.45
DAC_CS: R40.2, U6.12
DAC_LDAC: R44.1, U6.11
DAC_OUT1: R45.1, U6.2
DAC_OUT2: R47.1, U6.3
DAC_OUT3: R49.1, U6.4
DAC_OUT4: R51.1, U6.5
DAC_REF: C40.1, U6.1
DAC_SCLK: R41.2, U6.13
DAC_SDI: R42.2, U6.14
DAC_SDO: R43.1, U6.15
GATE1: Q1.1, Q5.3, R68.2
GATE2: Q2.1, Q6.3, R69.2
GATE3: Q3.1, Q7.3, R70.2
GATE4: Q4.1, Q8.3, R71.2
GDRV1: C52.1, R68.1, R76.1, U7.1
GDRV2: C53.1, R69.1, R78.1, U7.7
GDRV3: C54.1, R70.1, R80.1, U7.8
GDRV4: C55.1, R71.1, R82.1, U7.14
GMON1: C56.1, R76.2, R77.1, U1.14
GMON2: C57.1, R78.2, R79.1, U1.15
GMON3: C58.1, R80.2, R81.1, U1.19
GMON4: C59.1, R82.2, R83.1, U1.28
GND: C1.2, C2.2, C4.2, C5.2, C6.2, C7.2, C8.2, C9.2, C10.2, C11.2, C12.2, C13.2, C14.2, C15.2, C16.2, C20.2, C21.2, C22.2, C24.2, C25.2, C26.2, C27.2, C28.2, C30.2, C31.2, C40.2, C41.2, C42.2, C43.2, C48.2, C50.2, C51.2, C56.2, C57.2, C58.2, C59.2, C61.2, C70.2, C71.2, C72.2, C73.2, C74.2, C75.2, C76.2, C77.2, C78.2, C79.2, C80.2, C81.2, C82.2, C83.2, D1.2, D2.2, D3.1, D4.1, J1.2, J3.2, J3.4, J3.6, J4.5, J4.7, J4.11, NT2.1, NT4.1, NT6.1, Q5.2, Q6.2, Q7.2, Q8.2, R2.2, R4.2, R5.2, R7.2, R10.2, R11.2, R13.2, R18.2, R54.2, R77.2, R79.2, R81.2, R83.2, R90.2, R91.2, R92.2, R93.2, R94.2, R95.2, R96.2, R97.2, R98.2, R99.2, R100.2, R101.2, R102.4, R120.2, RT1.2, RT2.2, RT3.2, RT4.2, TP8.1, TP9.1, U1.49, U2.1, U2.9, U3.1, U3.9, U4.2, U5.1, U6.6, U6.9, U6.17, U7.11
INJ_MID: C30.1, R14.2, R15.1
LED_STAT: R125.1, U1.34
LED_STAT_A: D4.2, R125.2
LINK_RX: R122.2, R123.1, U1.32
LINK_TX: R121.1, U1.31
MCU_DAC_CS: R40.1, U1.38
MCU_MISO: R43.2, U1.42
MCU_MOSI: R42.1, U1.43
MCU_SCLK: R41.1, U1.41
NINV1: C52.2, R60.2, R64.2, U7.2
NINV2: C53.2, R61.2, R65.2, U7.6
NINV3: C54.2, R62.2, R66.2, U7.9
NINV4: C55.2, R63.2, R67.2, U7.13
NRST: C78.1, J3.10, J4.12, U1.7
NTC1: C80.1, R126.2, RT1.1, U1.18
NTC2: C81.1, R127.2, RT2.1, U1.24
NTC3: C82.1, R128.2, RT3.1, U1.25
NTC4: C83.1, R129.2, RT4.1, U1.27
RXD_A: J3.7, R122.1
SET1: C44.1, R45.2, R46.1, TP12.1, U7.3
SET2: C45.1, R47.2, R48.1, TP14.1, U7.5
SET3: C46.1, R49.2, R50.1, TP16.1, U7.10
SET4: C47.1, R51.2, R52.1, TP18.1, U7.12
SNSHI1: R60.1, R102.2, TP13.1
SNSHI2: NT1.2, R61.1, TP15.1
SNSHI3: NT3.2, R62.1, TP17.1
SNSHI4: NT5.2, R63.1, TP19.1
SNSLO1: C44.2, R46.2, R102.3
SNSLO2: C45.2, NT2.2, R48.2
SNSLO3: C46.2, NT4.2, R50.2
SNSLO4: C47.2, NT6.2, R52.2
SPARE_PA5: TP11.1, U1.13
SRC1: Q1.3, R102.1
SRC2: NT1.1, Q2.2, R90.1, R91.1, R92.1, R93.1, R94.1, R95.1, R96.1, R97.1, R98.1, R99.1
SRC3: NT3.1, Q3.2, R100.1
SRC4: NT5.1, Q4.2, R101.1
SWCLK: J4.6, U1.37
SWDIO: J4.4, U1.36
TXD_A: J3.5, R121.2
V48_SENSE: C2.1, R1.2, R2.1, U1.17
VCP_RX: J4.13, U1.11
VCP_TX: J4.14, U1.10
VOUT: C24.1, C25.1, C26.1, C27.1, C28.1, C29.1, C60.1, D2.1, J2.2, L2.2, R12.1, R17.1, TP5.1
VOUT_SENSE: C31.1, R17.2, R18.1, U1.8

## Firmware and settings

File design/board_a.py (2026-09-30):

"""Board A: 4-decade LED driver (power, tracking buck, four linear sinks, STM32G431).

Values and their reasoning: see calc.py and docs/design-record/phase2-detailed-design.md,
section "Circuit design".
Net names: +48V_RAW, +48V, +5V5, +5VA, +3V3, +3V3A, VOUT and GND are power nets;
CATHODE is the LED cathode node; SRCk/SNSHIk/SNSLOk are channel k's FET source,
Kelvin sense top and Kelvin sense bottom.
"""
from netlib import Board, NC

SHEETS = [
    ("A1", "Power entry and auxiliary rails"),
    ("A2", "Tracking buck (V_out)"),
    ("A3", "DAC, dividers and zero bias"),
    ("A4", "Sink channels 1-4"),
    ("A5", "LED output and cathode sensing"),
    ("A6", "MCU, debug, link and monitoring"),
]


def build():
    b = Board("board_a", "Board A (driver)", SHEETS)
    b.power_sources = {"+48V": "J1 via F1", "+5V5": "U3", "+5VA": "U4", "+3V3": "U5", "+3V3A": "FB1", "VOUT": "U2"}

    # ------------------------------------------------------------------ A1 power entry and rails
    s = "A1"
    b.two("J1", "MSTBA2", "+48V_RAW", "GND", s, note="Pin 1 +48 V, pin 2 return. Mark polarity on the silkscreen")
    b.two("F1", "FUSE3A", "+48V_RAW", "+48V", s)
    b.add("D1", "SMBJ58A", {"1": "+48V", "2": "GND"}, s,
          note="Surge clamp; conducts on reverse polarity so F1 or the supply's hiccup takes over")
    b.add("C1", "C_47U_100V", {"1": "+48V", "2": "GND"}, s)
    b.two("R1", "R_100K", "+48V", "V48_SENSE", s)
    b.two("R2", "R_6K2", "V48_SENSE", "GND", s)
    b.two("C2", "C_10N", "V48_SENSE", "GND", s)
    # aux buck 5.5 V, 500 kHz
    b.add("U3", "LMR38020FDDAR", {"1": "GND", "2": "AUX_EN", "3": "+48V", "4": "AUX_RT", "5": "AUX_FB",
                                  "6": NC, "7": "AUX_BOOT", "8": "AUX_SW", "9": "GND"}, s,
          note="PG unused. Exposed pad to GND with a via array")
    b.two("R3", "R_280K", "+48V", "AUX_EN", s)
    b.two("R4", "R_10K", "AUX_EN", "GND", s, note="R3/R4: starts at ~36 V")
    b.two("R5", "R_52K3", "AUX_RT", "GND", s, note="500 kHz")
    b.two("R6", "R_100K", "+5V5", "AUX_FB", s)
    b.two("R7", "R_22K1", "AUX_FB", "GND", s, note="R6/R7: 5.53 V")
    b.two("C3", "C_100N", "AUX_BOOT", "AUX_SW", s)
    b.two("L3", "SRR1260-150M", "AUX_SW", "+5V5", s)
    b.two("C4", "C_4U7_100V", "+48V", "GND", s, note="At U3 VIN/GND, shortest possible loop")
    b.two("C5", "C_100N_100V", "+48V", "GND", s)
    for ref in ("C6", "C7", "C8"):
        b.two(ref, "C_22U", "+5V5", "GND", s)
    # +5VA analog
    b.add("U4", "TPS7A2050PDBVR", {"1": "+5V5", "2": "GND", "3": "+5V5", "4": NC, "5": "+5VA"}, s)
    b.two("C9", "C_1U", "+5V5", "GND", s)
    b.two("C10", "C_4U7", "+5VA", "GND", s)
    b.two("C11", "C_100N", "+5VA", "GND", s)
    # +3V3 digital
    b.add("U5", "LDL1117S33R", {"1": "GND", "2": "+3V3", "3": "+5V5"}, s)
    b.two("C12", "C_4U7", "+5V5", "GND", s)
    b.two("C13", "C_10U", "+3V3", "GND", s)
    b.two("C14", "C_100N", "+3V3", "GND", s)
    b.two("FB1", "FB600", "+3V3", "+3V3A", s)
    b.two("C15", "C_1U", "+3V3A", "GND", s)
    b.two("C16", "C_100N", "+3V3A", "GND", s)

    # ------------------------------------------------------------------ A2 tracking buck
    s = "A2"
    b.add("U2", "LMR38020FDDAR", {"1": "GND", "2": "BUCK_EN", "3": "+48V", "4": "BUCK_RT", "5": "BUCK_FB",
                                  "6": "BUCK_PG", "7": "BUCK_BOOT", "8": "BUCK_SW", "9": "GND"}, s,
          note="Forced-PWM variant only (the F in LMR38020F). Exposed pad to GND with a via array")
    b.two("R10", "R_100K", "BUCK_EN", "GND", s, note="Holds the buck off while the MCU is in reset")
    b.two("R11", "R_64K9", "BUCK_RT", "GND", s, note="400 kHz")
    b.two("C20", "C_4U7_100V", "+48V", "GND", s)
    b.two("C21", "C_4U7_100V", "+48V", "GND", s)
    b.two("C22", "C_100N_100V", "+48V", "GND", s, note="C22 closest to U2 pins 1 and 3")
    b.two("C23", "C_100N", "BUCK_BOOT", "BUCK_SW", s)
    b.two("L2", "SRR1260-330M", "BUCK_SW", "VOUT", s)
    for ref in ("C24", "C25", "C26", "C27"):
        b.two(ref, "C_4U7_100V", "VOUT", "GND", s)
    b.two("C28", "C_100N_100V", "VOUT", "GND", s)
    b.two("R12", "R_200K", "VOUT", "BUCK_FB", s)
    b.two("C29", "C_22P_C0G", "VOUT", "BUCK_FB", s, dnp=True, note="Feed-forward cap footprint, not fitted")
    b.two("R13", "R_7K32", "BUCK_FB", "GND", s)
    b.two("R14", "R_8K25", "BUCK_FB", "INJ_MID", s)
    b.two("R15", "R_8K25", "INJ_MID", "BUCK_DAC", s)
    b.two("C30", "C_47N", "INJ_MID", "GND", s,
          note="R12-R15, C30: V_out = 40.44 - 12.12 x V_dac; 38.0 V at 0.2 V, 3.5 V floor at 3.05 V")
    b.two("R16", "R_100K", "BUCK_PG", "+3V3", s)
    b.add("D2", "SMBJ43A", {"1": "VOUT", "2": "GND"}, s)
    b.two("R17", "R_1M", "VOUT", "VOUT_SENSE", s)
    b.two("R18", "R_82K", "VOUT_SENSE", "GND", s)
    b.two("C31", "C_10N", "VOUT_SENSE", "GND", s)

    # ------------------------------------------------------------------ A3 DAC, dividers, bias
    s = "A3"
    b.add("U6", "DAC80504RTET", {"1": "DAC_REF", "2": "DAC_OUT1", "3": "DAC_OUT2", "4": "DAC_OUT3", "5": "DAC_OUT4",
                                 "6": "GND", "7": "+5VA", "8": "+3V3", "9": "GND", "10": "+3V3", "11": "DAC_LDAC",
                                 "12": "DAC_CS", "13": "DAC_SCLK", "14": "DAC_SDI", "15": "DAC_SDO", "16": "+3V3",
                                 "17": "GND"}, s,
          note="REFDIV and GAIN to VIO: the 2.5 V internal reference divided to 1.25 V, gain 2, so 0-2.5 V "
               "full scale with VREF/DIV well under VDD/2 (undivided, 2.5 V sits at the VDD/2 limit on a 5 V "
               "supply and the DAC shuts its outputs off). RSTSEL low: resets to zero scale")
    b.two("C40", "C_220N", "DAC_REF", "GND", s, note="Nothing else may load REF")
    b.two("C41", "C_100N", "+5VA", "GND", s)
    b.two("C42", "C_1U", "+5VA", "GND", s)
    b.two("C43", "C_100N", "+3V3", "GND", s)
    b.two("R40", "R_22", "MCU_DAC_CS", "DAC_CS", s)
    b.two("R41", "R_22", "MCU_SCLK", "DAC_SCLK", s)
    b.two("R42", "R_22", "MCU_MOSI", "DAC_SDI", s)
    b.two("R43", "R_22", "DAC_SDO", "MCU_MISO", s)
    b.two("R44", "R_10K", "DAC_LDAC", "+3V3", s, note="Updates are triggered in software (TRIGGER register)")
    for k, (rt, rb, cd) in enumerate((("R45", "R46", "C44"), ("R47", "R48", "C45"),
                                      ("R49", "R50", "C46"), ("R51", "R52", "C47")), start=1):
        b.two(rt, "RT_12K", f"DAC_OUT{k}", f"SET{k}", s)
        b.two(rb, "RT_1K", f"SET{k}", f"SNSLO{k}", s,
              note=f"Returns to channel {k}'s Kelvin sense bottom, not to the plane" if k == 1 else "")
        b.two(cd, "C_10N_C0G", f"SET{k}", f"SNSLO{k}", s)
    b.two("R53", "R_10K", "+5VA", "BIAS", s)
    b.two("R54", "R_1K", "BIAS", "GND", s)
    b.two("C48", "C_1U", "BIAS", "GND", s, note="R53/R54: 0.455 V bias source for the four 1.82 M zero-bias resistors")

    # ------------------------------------------------------------------ A4 sink channels
    s = "A4"
    b.add("U7", "OPA4388IPWR", {"1": "GDRV1", "2": "NINV1", "3": "SET1", "4": "+5VA", "5": "SET2", "6": "NINV2",
                                "7": "GDRV2", "8": "GDRV3", "9": "NINV3", "10": "SET3", "11": "GND",
                                "12": "SET4", "13": "NINV4", "14": "GDRV4"}, s)
    b.two("C50", "C_100N", "+5VA", "GND", s)
    b.two("C51", "C_1U", "+5VA", "GND", s)
    fets = {1: ("Q1", "NDT3055L"), 2: ("Q2", "2N7002BK"), 3: ("Q3", "2N7002"), 4: ("Q4", "2N7002")}
    clamp_pin = {1: "CLAMP1", 2: "CLAMP2", 3: "CLAMP3", 4: "CLAMP4"}
    for k in (1, 2, 3, 4):
        n = 60 + (k - 1)
        b.two(f"R{n}", "R_1K", f"SNSHI{k}", f"NINV{k}", s)                        # R60-R63  R_IN
        b.two(f"C{52 + k - 1}", "C_2N2_C0G", f"GDRV{k}", f"NINV{k}", s)             # C52-C55  C_C
        b.two(f"R{64 + k - 1}", "R_1M82", "BIAS", f"NINV{k}", s)                    # R64-R67  zero bias
        b.two(f"R{68 + k - 1}", "R_220", f"GDRV{k}", f"GATE{k}", s)                 # R68-R71  R_G
        qref, qkey = fets[k]
        if qkey == "NDT3055L":
            b.add(qref, qkey, {"1": f"GATE{k}", "2": "CATHODE", "3": f"SRC{k}"}, s)
        else:
            b.add(qref, qkey, {"1": f"GATE{k}", "2": f"SRC{k}", "3": "CATHODE"}, s)
        b.add(f"Q{4 + k}", "2N7002BK", {"1": clamp_pin[k], "2": "GND", "3": f"GATE{k}"}, s)   # Q5-Q8 clamps
        b.two(f"R{72 + k - 1}", "R_100K", clamp_pin[k], "+3V3", s)                  # R72-R75 clamp on in reset
        b.two(f"R{76 + 2 * (k - 1)}", "R_100K", f"GDRV{k}", f"GMON{k}", s)         # R76,78,80,82
        b.two(f"R{77 + 2 * (k - 1)}", "R_100K", f"GMON{k}", "GND", s)              # R77,79,81,83
        b.two(f"C{56 + k - 1}", "C_1N_C0G", f"GMON{k}", "GND", s)                   # C56-C59
    # shunts
    b.add("R102", "WSK2512_0R1", {"1": "SRC1", "2": "SNSHI1", "3": "SNSLO1", "4": "GND"}, s,
          note="Pads 1/4 carry current, 2/3 are the Kelvin sense pads")
    for i in range(10):
        b.two(f"R{90 + i}", "RT_10R", "SRC2", "GND", s)
    b.two("NT1", "NETTIE", "SRC2", "SNSHI2", s, note="Mid-point of the SRC2 bus bar of R90-R99")
    b.two("NT2", "NETTIE", "GND", "SNSLO2", s, note="Mid-point of the ground bus bar of R90-R99")
    b.two("R100", "RT_10R", "SRC3", "GND", s)
    b.two("NT3", "NETTIE", "SRC3", "SNSHI3", s, note="At R100's pad")
    b.two("NT4", "NETTIE", "GND", "SNSLO3", s, note="At R100's pad")
    b.two("R101", "RT_100R", "SRC4", "GND", s)
    b.two("NT5", "NETTIE", "SRC4", "SNSHI4", s, note="At R101's pad")
    b.two("NT6", "NETTIE", "GND", "SNSLO4", s, note="At R101's pad")

    # ------------------------------------------------------------------ A5 LED output and cathode
    s = "A5"
    b.two("J2", "MSTBA2", "CATHODE", "VOUT", s,
          note="Pin 1 LED- (toward the sinks), pin 2 LED+ (red lead, toward the buck); a 1 mm slot between the pads")
    b.two("C60", "C_22N_100V", "VOUT", "CATHODE", s, note="C_a: directly across J2's pins")
    b.two("R110", "R_1M", "CATHODE", "CATH_TAP", s)
    b.two("C61", "C_1N_C0G", "CATH_TAP", "GND", s)
    b.add("D3", "BAV199", {"1": "GND", "2": "+3V3", "3": "CATH_TAP"}, s)

    # ------------------------------------------------------------------ A6 MCU, debug, link, monitoring
    s = "A6"
    b.add("U1", "STM32G431CBU6", {
        "1": "+3V3", "2": "BUCK_EN", "3": NC, "4": NC, "5": NC, "6": NC, "7": "NRST",
        "8": "VOUT_SENSE", "9": "CATH_TAP", "10": "VCP_TX", "11": "VCP_RX", "12": "BUCK_DAC", "13": "SPARE_PA5",
        "14": "GMON1", "15": "GMON2", "16": "BUCK_PG", "17": "V48_SENSE", "18": "NTC1", "19": "GMON3",
        "20": "+3V3A", "21": "+3V3A", "22": NC, "23": "+3V3", "24": "NTC2", "25": "NTC3", "26": NC,
        "27": "NTC4", "28": "GMON4", "29": "CLAMP1", "30": "CLAMP2", "31": "LINK_TX", "32": "LINK_RX",
        "33": "A_OK_MCU", "34": "LED_STAT", "35": "+3V3", "36": "SWDIO", "37": "SWCLK", "38": "MCU_DAC_CS",
        "39": "CLAMP3", "40": NC, "41": "MCU_SCLK", "42": "MCU_MISO", "43": "MCU_MOSI", "44": NC, "45": "CLAMP4",
        "46": "BOOT0", "47": NC, "48": "+3V3", "49": "GND"}, s,
        note="Exposed pad is VSS: solder it and stitch it to GND. PB6 and PB4 carry the UCPD dead-battery pull-downs "
             "until firmware disables them, so no clamp sits on PB6. BUCK_EN is on PC13 because the ROM bootloader "
             "drives PB9 (its FDCAN1_TX) high; PC13 has no bootloader function, so R10 holds the buck off")
    for ref in ("C70", "C71", "C72", "C73"):
        b.two(ref, "C_100N", "+3V3", "GND", s)
    b.two("C74", "C_4U7", "+3V3", "GND", s)
    b.two("C75", "C_1U", "+3V3A", "GND", s)
    b.two("C76", "C_100N", "+3V3A", "GND", s)
    b.two("C77", "C_100N", "+3V3A", "GND", s, note="C77 at VREF+ (pin 20), C76 at VDDA (pin 21)")
    b.two("C78", "C_100N", "NRST", "GND", s)
    b.two("R120", "R_10K", "BOOT0", "GND", s)
    b.add("J4", "STDC14", {"1": NC, "2": NC, "3": "+3V3", "4": "SWDIO", "5": "GND", "6": "SWCLK", "7": "GND",
                           "8": NC, "9": NC, "10": NC, "11": "GND", "12": "NRST", "13": "VCP_RX", "14": "VCP_TX"}, s,
          note="STLINK-V3MINIE: pin 13 drives the target RX (PA3), pin 14 receives the target TX (PA2). "
               "Pin 8 (SWO) stays open because PB3 is SPI1_SCK")
    b.add("J3", "IDC2x5", {"1": "+5V5_LINK", "2": "GND", "3": "+5V5_LINK", "4": "GND", "5": "TXD_A", "6": "GND",
                           "7": "RXD_A", "8": "BOOT0", "9": "A_OK", "10": "NRST"}, s,
          note="Place next to the aux buck so Board B's return current never crosses the precision section")
    b.two("FB2", "FB600_2A", "+5V5", "+5V5_LINK", s)
    b.two("C79", "C_10U", "+5V5_LINK", "GND", s)
    b.two("R121", "R_100", "LINK_TX", "TXD_A", s)
    b.two("R122", "R_100", "RXD_A", "LINK_RX", s)
    b.two("R123", "R_100K", "LINK_RX", "+3V3", s)
    b.two("R124", "R_100", "A_OK_MCU", "A_OK", s)
    b.two("R125", "R_1K", "LED_STAT", "LED_STAT_A", s)
    b.add("D4", "LED_G", {"1": "GND", "2": "LED_STAT_A"}, s)
    ntc_notes = {1: "at the ch1 FET (Q1) tab copper", 2: "between U2 and L2", 3: "between U3 and the LDOs",
                 4: "in the precision section, between U6 and U7"}
    for k in (1, 2, 3, 4):
        b.two(f"RT{k}", "NTC10K", f"NTC{k}", "GND", s, note=f"NTC{k} {ntc_notes[k]}")
        b.two(f"R{126 + k - 1}", "R_10K", "+3V3A", f"NTC{k}", s)
        b.two(f"C{80 + k - 1}", "C_10N", f"NTC{k}", "GND", s)
    # test points
    tps = [("TP1", "+48V"), ("TP2", "+5V5"), ("TP3", "+5VA"), ("TP4", "+3V3"), ("TP5", "VOUT"), ("TP6", "CATH_TAP"),
           ("TP7", "BIAS"), ("TP8", "GND"), ("TP9", "GND"), ("TP10", "BUCK_DAC"), ("TP11", "SPARE_PA5")]
    for k in (1, 2, 3, 4):
        tps += [(f"TP{11 + 2 * k - 1}", f"SET{k}"), (f"TP{11 + 2 * k}", f"SNSHI{k}")]
    for ref, net in tps:
        b.add(ref, "TP", {"1": net}, s)
    b.single_ok.update({"SPARE_PA5"})
    for i in range(1, 5):
        b.add(f"H{i}", "MH", {}, s)
    b.extras.append(("J1 J2 plugs (off-board)", "MSTB_PLUG", 2))
    for i in range(1, 4):
        b.add(f"FID{i}", "FID", {}, s)
    return b


if __name__ == "__main__":
    brd = build()
    e, w = brd.erc()
    print(f"{len(brd.parts)} parts, {len(brd.nets())} nets, {len(e)} errors, {len(w)} warnings")
    for x in e + w:
        print(" ", x)

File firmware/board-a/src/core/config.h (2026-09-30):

/*
 * Board A constants and tunables. Every value here traces to the Phase 2 design (docs/design-record/),
 * section "Circuit design", or to design/calc.py.
 */
#ifndef CONFIG_H
#define CONFIG_H

#define FW_VERSION_MAJOR 1
#define FW_VERSION_MINOR 0
#define FW_VERSION ((FW_VERSION_MAJOR << 8) | FW_VERSION_MINOR)

/* ---------------------------------------------------------------- LED */
#define I_MAX_A              1.40f     /* XTM rated current */
#define I_ABS_MAX_A          1.50f     /* never commanded above this */
#define I_TAIL_END_DEFAULT_A 5e-6f     /* bottom of the curve; adjustable (param) */
#define VF_REF_I_A           1.40f
#define VF0_DEFAULT_V        29.9f     /* typical V_f at 1.4 A, datasheet */
#define VF_NNVT_V            0.65f     /* low-current slope, ~10 dies */
#define VF_RS_OHM            1.48f     /* series resistance fitted to 27.9 V @ 0.5 A, 29.9 V @ 1.4 A */

/* ---------------------------------------------------------------- channels */
#define NCH 4                          /* index 0..3 = ch1..ch4 */
#define DAC_VREF_V      2.5f
#define DIV_RATIO       (1.0f / 13.0f) /* 12.0k / 1.00k */
#define SENSE_LSB_V     (DAC_VREF_V * DIV_RATIO / 65536.0f)
#define ZB_SRC_V        (5.0f / 11.0f) /* BIAS node */
#define ZB_R_OHM        1.82e6f
#define RIN_OHM         1000.0f
#define E_KA_V          25e-6f         /* keep-alive: sense volts above the dead-zone edge */

/* shunts, ch1..ch4 */
#define RS_CH1 0.1f
#define RS_CH2 1.0f
#define RS_CH3 10.0f
#define RS_CH4 100.0f

/* blend bands between adjacent channels: band 0 = ch4->ch3, 1 = ch3->ch2, 2 = ch2->ch1 */
#define BAND_LO_0 1.4e-3f
#define BAND_HI_0 1.6e-3f
#define BAND_LO_1 14e-3f
#define BAND_HI_1 16e-3f
#define BAND_LO_2 140e-3f
#define BAND_HI_2 160e-3f
#define ARM_FRACTION    0.5f           /* arm the next channel up at this fraction of its band bottom */
#define DISARM_FRACTION 0.25f
#define ARM_LOOKAHEAD_S 0.4f           /* arm early when a fade will reach the band within this time */

/* ---------------------------------------------------------------- fades */
#define TICK_HZ         4000u          /* fade engine and DAC update rate */
#define LEVEL_MAX       65535u         /* link level 1..65535 maps onto the curve, 0 = off */

/* ---------------------------------------------------------------- tracking buck */
#define BUCK_V0         40.44f         /* V_out = BUCK_V0 - BUCK_K * V_dac (200k / 7.32k / 2 x 8.25k) */
#define BUCK_K          12.12f
#define VDAC_MIN_V      0.20f          /* buffered DAC limits */
#define VDAC_MAX_V      3.10f
#define VOUT_FLOOR_V    3.5f           /* blackout floor */
#define VOUT_MAX_V      38.0f          /* highest commanded V_out */
#define VOUT_TAU_S      0.00025f       /* V_out response to a DAC step, used to pace current rises */
#define HEADROOM_HI_V   1.0f           /* at >= 100 mA */
#define HEADROOM_LO_V   0.7f           /* at <= 50 mA */
#define HEADROOM_MIN_V  0.45f          /* below this the sink can't hold its current */
#define VOUT_SENSE_GAIN ((1000e3f + 82e3f) / 82e3f)
#define V48_SENSE_GAIN  ((100e3f + 6.2e3f) / 6.2e3f)
#define V48_ON_V        42.0f
#define V48_UV_V        40.0f
#define TAIL_DROP_V     9.0f           /* voltage-mode tail: ~6 decades below the tail end */

/* ---------------------------------------------------------------- protection */
#define SHORT_VF_MIN_V      15.0f      /* V_out - V_cath below this with current flowing = shorted LED */
#define CATH_TRIP_MARGIN_V  1.2f       /* comparator threshold above the headroom target */
#define CATH_TRIP_MAX_V     3.0f
#define OPEN_VCATH_V        0.15f
#define NTC_B               3380.0f
#define NTC_R25             10000.0f
#define NTC_RPULL           10000.0f

/* per-NTC derate start / trip, degrees C: FET, main buck, aux rails, precision section */
#define NTC_DERATE { 95.0f, 90.0f, 90.0f, 75.0f }
#define NTC_TRIP   { 110.0f, 105.0f, 105.0f, 90.0f }

/* ---------------------------------------------------------------- link */
#define LINK_TIMEOUT_MS     1500u
#define LINK_STATUS_MS      100u
#define LINK_HOLD_MAX_S     120u
#define FALLBACK_B_DEFAULT  0.20f      /* link loss: 20 % of the encoder's scale */

#endif

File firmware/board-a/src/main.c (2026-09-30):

/*
 * Board A firmware: 4-decade LED driver for the Xicato XTM.
 *
 * Start-up order matters: the gate clamps are driven on and the main buck held off
 * before anything else, the buck DAC is set to the V_out floor before its output
 * enables, and the main buck starts only once the 48 V rail is confirmed.
 */
#include "config.h"
#include "console.h"
#include "control.h"
#include "hw.h"
#include "link.h"
#include "params.h"
#include "settings.h"

static params_t g_params;

params_t *app_params(void) { return &g_params; }

static void status_led(uint32_t now)
{
    int on;
    ctl_state_t s = control_state();
    if (s == CTL_FAULT)
        on = (now / 100u) & 1u;                                   /* 5 Hz */
    else if (link_is_lost())
        on = (now % 1000u) < 100u || ((now % 1000u) >= 200u && (now % 1000u) < 300u);   /* double blink */
    else if (s == CTL_ON || s == CTL_STARTING || s == CTL_TAIL || s == CTL_RAW)
        on = 1;
    else
        on = (now % 2000u) < 50u;                                 /* alive */
    hw_led(on);
}

int main(void)
{
    hw_init_clock();
    hw_init_gpio();                    /* clamps on, buck off, DAC CS high */
    hw_init_systick();
    uint32_t reset_cause = hw_reset_cause();

    hw_flash_load(&g_params, sizeof(g_params));
    if (!params_valid(&g_params))
        params_defaults(&g_params);

    hw_adc_init();
    hw_buckdac_init((BUCK_V0 - VOUT_FLOOR_V) / BUCK_K);   /* floor before the buck ever runs */
    hw_comp_init();
    int dac_err = dac8_init();
    hw_uart_init();
    control_init(&g_params);
    console_init(reset_cause, dac_err);
    link_init();
    hw_iwdg_start();

    /* wait for a healthy 48 V rail before starting the main buck */
    analog_t a;
    uint32_t t0 = hw_millis(), last_msg = t0;
    for (;;) {
        hw_iwdg_kick();
        hw_adc_read(&a);
        if (a.v_48 >= V48_ON_V)
            break;
        uint32_t now = hw_millis();
        if (now - last_msg > 2000u) {
            con_printf("waiting for 48 V: v48=%.1f\r\n", (double)a.v_48);
            last_msg = now;
        }
        console_poll();
        hw_led(((now - t0) / 250u) & 1u);
    }
    hw_buck_enable(1);
    uint32_t t_pg = hw_millis();
    while (!hw_buck_pg() && hw_millis() - t_pg < 50u)
        hw_iwdg_kick();
    if (!hw_buck_pg())
        con_printf("warning: buck power-good not asserted after 50 ms\r\n");

    hw_tick_start(TICK_HZ);
    hw_aok(1);
    if (dac_err) {
        con_printf("DAC80504 did not respond as expected (err=%d); outputs stay off\r\n", dac_err);
        control_force_fault(LFAULT_DAC);
    }

    for (;;) {
        hw_iwdg_kick();
        control_background();
        link_poll();
        console_poll();
        status_led(hw_millis());
    }
}

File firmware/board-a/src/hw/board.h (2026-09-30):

/* Board A pin map (matches design/board_a.py, sheet A6). */
#ifndef BOARD_H
#define BOARD_H

#include "stm32g4xx.h"

/* gate clamps ch1..ch4: high = clamp on (gate held low). Pulled up in hardware. */
#define CLAMP1_PORT GPIOC
#define CLAMP1_PIN  LL_GPIO_PIN_6
#define CLAMP2_PORT GPIOA
#define CLAMP2_PIN  LL_GPIO_PIN_8
#define CLAMP3_PORT GPIOC
#define CLAMP3_PIN  LL_GPIO_PIN_10
#define CLAMP4_PORT GPIOB
#define CLAMP4_PIN  LL_GPIO_PIN_7

/* PC13, not PB9: the ROM bootloader drives PB9 (its FDCAN1_TX) high, and PC13 has no bootloader
 * function, so R10's 100k pull-down keeps the buck off in reset, in the bootloader and when unprogrammed. */
#define BUCK_EN_PORT GPIOC
#define BUCK_EN_PIN  LL_GPIO_PIN_13
#define BUCK_PG_PORT GPIOC
#define BUCK_PG_PIN  LL_GPIO_PIN_4

#define LED_PORT GPIOA
#define LED_PIN  LL_GPIO_PIN_12
#define AOK_PORT GPIOA
#define AOK_PIN  LL_GPIO_PIN_11

#define DAC_CS_PORT GPIOA
#define DAC_CS_PIN  LL_GPIO_PIN_15

/* analog inputs */
#define ADC1_CH_VOUT  LL_ADC_CHANNEL_1    /* PA0 */
#define ADC1_CH_CATH  LL_ADC_CHANNEL_2    /* PA1, also COMP1_INP */
#define ADC1_CH_V48   LL_ADC_CHANNEL_15   /* PB0 */
#define ADC1_CH_NTC1  LL_ADC_CHANNEL_12   /* PB1  FET */
#define ADC1_CH_NTC2  LL_ADC_CHANNEL_14   /* PB11 main buck */
#define ADC1_CH_NTC3  LL_ADC_CHANNEL_11   /* PB12 aux rails */
#define ADC1_CH_NTC4  LL_ADC_CHANNEL_5    /* PB14 precision section */
#define ADC2_CH_GMON1 LL_ADC_CHANNEL_3    /* PA6 */
#define ADC2_CH_GMON2 LL_ADC_CHANNEL_4    /* PA7 */
#define ADC2_CH_GMON3 LL_ADC_CHANNEL_12   /* PB2 */
#define ADC2_CH_GMON4 LL_ADC_CHANNEL_15   /* PB15 */

#endif
